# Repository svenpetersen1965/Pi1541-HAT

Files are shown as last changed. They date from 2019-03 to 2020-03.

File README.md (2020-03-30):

# Pi1541-HAT
Just another Pi1541-HAT. Please refer to Steve Whites project page (https://cbm-pi1541.firebaseapp.com/), who had the idea for the project and develops the software running in the Raspberry Pi.

There are several Pi1541-HATs, which are all good, nevertheless I have decided to make my own HAT. 

1. It has detachable display, switches and IEC-Bus boards

2. There is a barrel connector on the IEC-Bus Board, so no requirement for using the micro USB and no side entry for the enclosure required.

Find some info on the required cable making <a href="http://tech.guitarsite.de/cable_making.html">on my website</a>

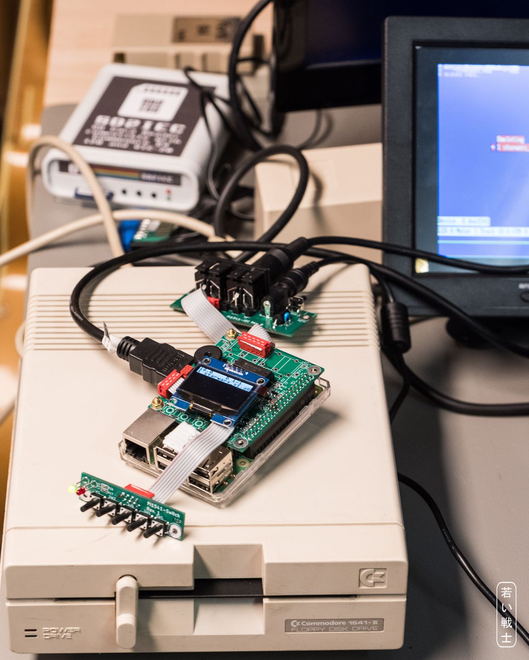
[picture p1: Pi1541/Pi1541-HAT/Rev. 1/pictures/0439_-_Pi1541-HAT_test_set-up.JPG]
Pi1541 with the detachable switch and iec board


I have made it this way to add flexibility to the HAT when it comes to be installed in an enclose and also alows a lower profile enclosure, since the high IEC-bus jacks are not above HAT level.

As a replacement for the switch board, a pcb with a rotary encoder with push button has been developed. This adds a quite bit more comfort while navigating through the directories. It mimiks the select, up and down button. This way, it works with the regular firmware (even before 1.21). Depending on the amount of text to be scrolled on the display, some pulses might get lost, which is hard to notice and does not reduce the usability.

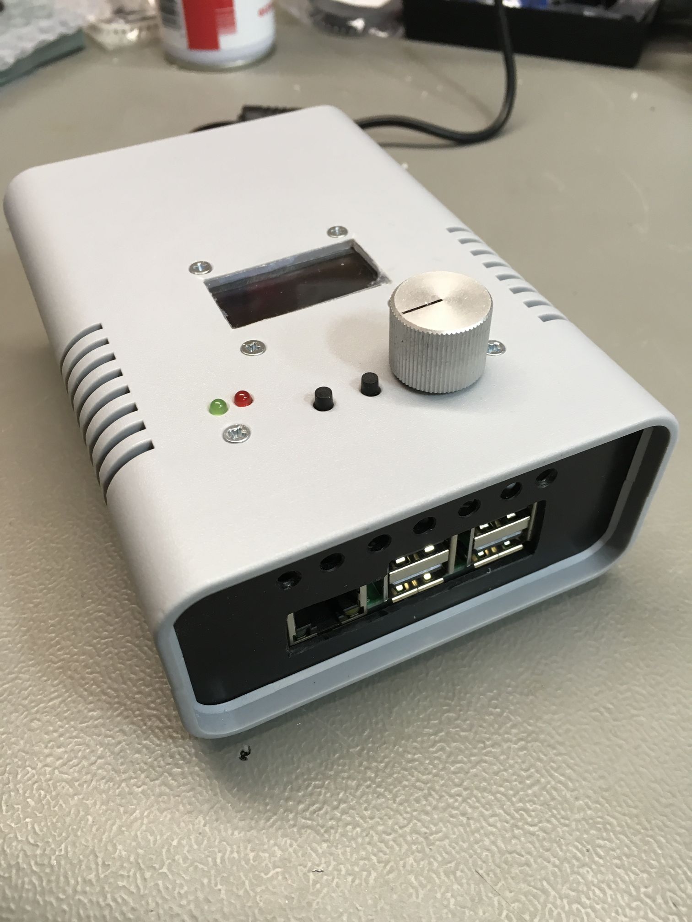
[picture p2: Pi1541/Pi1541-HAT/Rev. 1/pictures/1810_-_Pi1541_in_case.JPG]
Pi1541 withRotary Encoder Board in plastic enclusore


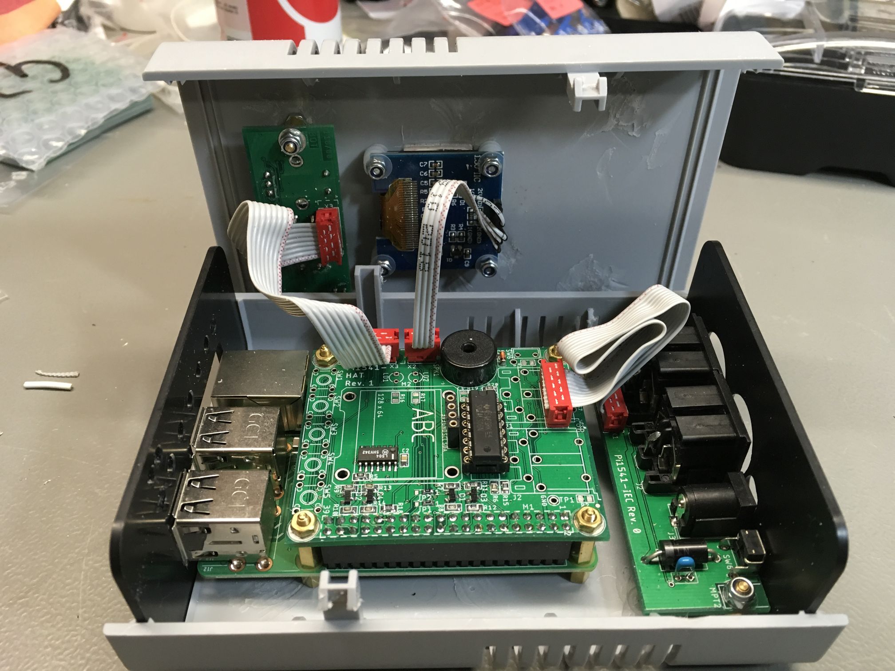
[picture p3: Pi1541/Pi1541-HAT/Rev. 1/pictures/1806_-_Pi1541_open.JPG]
Pi1541 withRotary Encoder Board (case open)


The kernal revision v1.21 supports the connection of a rotary encoder. Rev. 2 of the HAT PCB provides the connection of a rotary encoder module (KY-040), which is widely available on ebay etc. This is ment to be as a cheaper alternative for the otary encoder board of this project. 

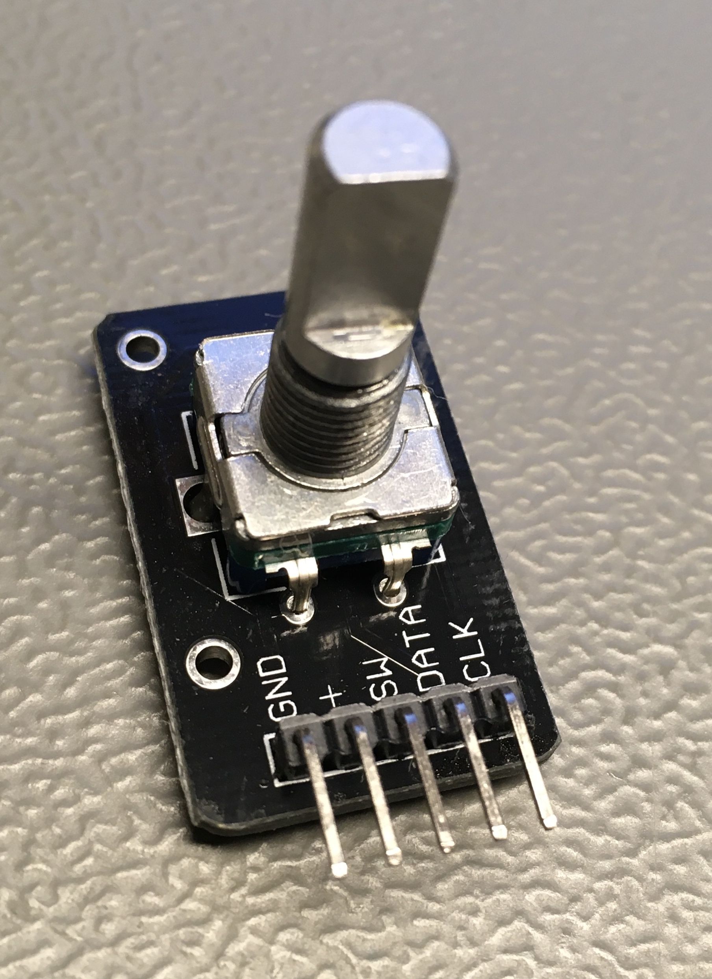
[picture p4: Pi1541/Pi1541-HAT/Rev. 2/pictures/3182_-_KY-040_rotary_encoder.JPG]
KY-040


The Rev. 2 of HAT and Switch and the (newest) Rev. 1 of the IEC board were tested and are fully functional.

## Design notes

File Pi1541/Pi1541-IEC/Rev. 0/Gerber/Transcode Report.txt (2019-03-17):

   ---- Transcoding 'X:\Projekte\_Eigene\Pi1541\Pi1541-IEC\Rev. 0\Gerber\gerber_Pi1541_IEC.crc' ----   Wed Feb 27 17:10:41 2019

D10   --> D100
D11   --> D101
-----------------------------------------------------------------

   ---- Transcoding 'X:\Projekte\_Eigene\Pi1541\Pi1541-IEC\Rev. 0\Gerber\gerber_Pi1541_IEC.out' ----   Wed Feb 27 17:10:41 2019

D12   --> D102
D13   --> D103
D14   --> D104
-----------------------------------------------------------------

   ---- Transcoding 'X:\Projekte\_Eigene\Pi1541\Pi1541-IEC\Rev. 0\Gerber\gerber_Pi1541_IEC.plc' ----   Wed Feb 27 17:10:41 2019

D12   --> D105
D13   --> D106
D14   --> D107
D15   --> D108
D16   --> D109
D17   --> D110
D18   --> D111
-----------------------------------------------------------------

   ---- Transcoding 'X:\Projekte\_Eigene\Pi1541\Pi1541-IEC\Rev. 0\Gerber\gerber_Pi1541_IEC.stc' ----   Wed Feb 27 17:10:41 2019

D12   --> D112
D13   --> D113
D14   --> D114
D15   --> D115
D16   --> D116
D17   --> D117
D18   --> D118
D19   --> D119
D20   --> D120
D21   --> D121
D22   --> D122
D23   --> D123
D24   --> D124
D25   --> D125
D26   --> D126
D27   --> D127
-----------------------------------------------------------------

   ---- Transcoding 'X:\Projekte\_Eigene\Pi1541\Pi1541-IEC\Rev. 0\Gerber\gerber_Pi1541_IEC.sts' ----   Wed Feb 27 17:10:41 2019

D12   --> D128
D13   --> D129
D14   --> D130
D15   --> D131
D16   --> D132
D17   --> D133
D18   --> D134
D20   --> D135
D22   --> D136
D23   --> D137
D24   --> D138
D25   --> D139
D26   --> D140
-----------------------------------------------------------------

   ---- Transcoding 'X:\Projekte\_Eigene\Pi1541\Pi1541-IEC\Rev. 0\Gerber\gerber_Pi1541_IEC.top' ----   Wed Feb 27 17:10:41 2019

D12   --> D141
D13   --> D142
D14   --> D143
D19   --> D144
D20   --> D145
D21   --> D146
D22   --> D147
D23   --> D148
D24   --> D149
D25   --> D150
D26   --> D151
D27   --> D152
D28   --> D153
D29   --> D154
D30   --> D155
D32   --> D156
-----------------------------------------------------------------

   ---- Transcoding 'X:\Projekte\_Eigene\Pi1541\Pi1541-IEC\Rev. 0\Gerber\excellon_Pi1541_IEC.ndk' ----   Wed Feb 27 17:10:57 2019

T1   --> T12
-----------------------------------------------------------------

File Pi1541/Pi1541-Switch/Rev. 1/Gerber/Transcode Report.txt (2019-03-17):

   ---- Transcoding 'X:\Projekte\_Eigene\Pi1541\Pi1541-Switch\Rev. 1\Gerber\gerber_Pi1541_Switch.crc' ----   Wed Feb 27 17:13:12 2019

D10   --> D100
D11   --> D101
-----------------------------------------------------------------

   ---- Transcoding 'X:\Projekte\_Eigene\Pi1541\Pi1541-Switch\Rev. 1\Gerber\gerber_Pi1541_Switch.out' ----   Wed Feb 27 17:13:12 2019

D12   --> D102
D13   --> D103
D14   --> D104
-----------------------------------------------------------------

   ---- Transcoding 'X:\Projekte\_Eigene\Pi1541\Pi1541-Switch\Rev. 1\Gerber\gerber_Pi1541_Switch.plc' ----   Wed Feb 27 17:13:12 2019

D12   --> D105
D13   --> D106
D14   --> D107
D15   --> D108
D16   --> D109
D17   --> D110
D18   --> D111
D19   --> D112
-----------------------------------------------------------------

   ---- Transcoding 'X:\Projekte\_Eigene\Pi1541\Pi1541-Switch\Rev. 1\Gerber\gerber_Pi1541_Switch.pls' ----   Wed Feb 27 17:13:13 2019

D12   --> D113
D13   --> D114
D14   --> D115
D15   --> D116
D16   --> D117
-----------------------------------------------------------------

   ---- Transcoding 'X:\Projekte\_Eigene\Pi1541\Pi1541-Switch\Rev. 1\Gerber\gerber_Pi1541_Switch.stc' ----   Wed Feb 27 17:13:13 2019

D12   --> D118
D13   --> D119
D14   --> D120
D15   --> D121
D16   --> D122
D17   --> D123
D18   --> D124
D19   --> D125
D20   --> D126
D21   --> D127
D22   --> D128
D23   --> D129
D24   --> D130
-----------------------------------------------------------------

   ---- Transcoding 'X:\Projekte\_Eigene\Pi1541\Pi1541-Switch\Rev. 1\Gerber\gerber_Pi1541_Switch.sts' ----   Wed Feb 27 17:13:13 2019

D12   --> D131
D13   --> D132
D14   --> D133
D15   --> D134
D16   --> D135
D17   --> D136
D18   --> D137
D19   --> D138
D21   --> D139
D23   --> D140
-----------------------------------------------------------------

   ---- Transcoding 'X:\Projekte\_Eigene\Pi1541\Pi1541-Switch\Rev. 1\Gerber\gerber_Pi1541_Switch.top' ----   Wed Feb 27 17:13:13 2019

D12   --> D141
D13   --> D142
D14   --> D143
D15   --> D144
D20   --> D145
D21   --> D146
D22   --> D147
D23   --> D148
D24   --> D149
D25   --> D150
D26   --> D151
-----------------------------------------------------------------

   ---- Transcoding 'X:\Projekte\_Eigene\Pi1541\Pi1541-Switch\Rev. 1\Gerber\excellon_Pi1541_Switch.ndk' ----   Wed Feb 27 17:13:25 2019

T1   --> T6
-----------------------------------------------------------------

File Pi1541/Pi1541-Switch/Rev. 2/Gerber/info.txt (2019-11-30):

       Board: Pi1541_Switch
       Rev.:  2
  
       Files:
       ======
  
       All Gerber files are generated in extended gerber format (RS274X)
       *.TOP        : Film top copper
       *.BOT        :  -"- bottom copper
       *.STC        :  -"- top soldermask 
       *.STS        :  -"- bottom soldermask
       *.PLC        :  -"- silk screen top
       *.PLS        :  -"- silk screen bottom
       *.CRC        :  -"- cream top
       *.DK         : Drills plated Through (Excellon)
       *.NDK        : Drills not plated Through (Excellon)
       *.OUT        : Board outline

       Board Size:
       ===========
       Length     :   13.65 mm
       Width      :   56.0 mm
       Thickness  :   1.6 mm
       Material   :   FR 4
       Copper     :   35 um
       Surface    :   HASL
       
       Remarks:
       ========

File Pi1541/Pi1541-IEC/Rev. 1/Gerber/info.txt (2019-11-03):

      
       Board: Pi1541-IEC
       Rev.:  1
  
       Files:
       ======
  
       All Gerber files are generated in extended gerber format (RS274X)
       *.TOP        : Film top copper
       *.BOT        :  -"- bottom copper
       *.STC        :  -"- top soldermask 
       *.STS        :  -"- bottom soldermask
       *.PLC        :  -"- silk screen top
       *.PLS        :  -"- silk screen bottom
       *.CRC        :  -"- cream top
       *.DK         : Drills plated Through (Excellon)
       *.NDK        : Drills not plated Through (Excellon)
       *.OUT        : Board outline

       Board Size:
       ===========
       Length     :   74.0 mm
       Width      :   25.5 mm
       Thickness  :   1.6 mm
       Material   :   FR 4
       Copper     :   35 um
       Surface    :   HASL
       
       Remarks:
       ========
       Width >= 8mil
       Distance >= 6mil
       Drill >= 0.4mm

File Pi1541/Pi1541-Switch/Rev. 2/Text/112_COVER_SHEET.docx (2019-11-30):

Documentation

Pi1541 - Switch

Project number: 112

Revision: 2

Date: 30.11.2019

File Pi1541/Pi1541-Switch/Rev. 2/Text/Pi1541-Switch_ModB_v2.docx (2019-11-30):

Pi1541 – Switch Rev. 2

Module description

# Description

The Pi1541-Switch is a detachable switch board for the Pi1541 HAT (project number 111). The connector to the Pi1541 HAT is placed on the solder side of the PCB. Further on, the switches SW1, SW2 and SW3 can be replaced by a pin header (J3, placed on the solder side), which is designed for connecting a rotary encoder module (such as the KY-040), which is supported since the Pi1541 kernel v1.21, which was released in November 2019.

# Switches

The switches have functions according to the firmware and configuration, which can be found at this website: https://cbm-pi1541.firebaseapp.com/ (https://cbm-pi1541.firebaseapp.com/%20%20)

The default configuration is:

Switch | Function
SW1 (left) | Select/Reset
SW2 | Move Up/Previous Disk
SW3 | Move Down/Next Disk
SW4 | Exit Folder
SW5 (right) | Insert Disk

# LEDs

LED | Color | Function
LD2 | Green | Power Indicator
LD1 | Red | Busy Indicator

# Connector

X3: 8p Micro Match, female, THT (Tyco or alternative)

The ribbon cable can also be soldered in directly.

Pin | Signal
1 | /SW1
2 | /SW2
3 | /SW3
4 | /SW4
5 | /SW5
6 | LED_OUT (LD1)
7 | +3V3
8 | GND

## Rotary Encoder connector

J3 – 5-pin pin header (2.54mm pitch) vertical or 90°.

Pin | Signal
1 | GND
2 | +3V3
3 | SW (/SW1_IN)
4 | DATA (/SW3_IN)
5 | CLK (/SW2_IN)

# Measures

Can be found in the board print out

# Revision History

Rev. 0: Prototype

Rev. 1: Moved the connector X3 to the solder side

Rev. 2: added J3 for connecting the rotary encoder.

Pi1541-Switch_ModB_v2.docx 30.11.2019 16:55 Drafted by Sven Petersen Page 2 of 2 Doc.-No.: 112-6-01-02

Pi1541-Switch_ModB_v2.docx 30.11.2019 16:55 Drafted by Sven Petersen Page 1 of 1 Doc.-No.: 112-6-01-02

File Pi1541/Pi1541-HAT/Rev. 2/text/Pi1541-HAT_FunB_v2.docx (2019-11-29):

Pi1541-HAT Rev. 2

Functional Description

J1 and J2 are the IEC-Bus connectors for the Commodore computers. X1 can be assembled instead of J1 and J2 to make use of an external IEC-Bus PCB.

SW6 is an IEC-Bus RESET switch.

IC1A is the bus driver for the IEC-Bus DATA signal. R3 is the required 1k pull-up-resistor. Since DATA is a bi-directional signal, there is an input stage (IC2A and IC2B), too. This circuit resembled the original 1541 input circuitry. The input signals are inverted twice (which is not required, since the Pi1541 can be configured to use inverted input signals). Q1 in conjunction with R7 and R8 is acting as a 5V/3.3V level shifter. This is a common level shifter circuit as suggested for I²C-bus level shifting by NXP.

The circuit for the CLK signal of the IEC-bus is the same. ATN and /RESET do not have an output stage. The input stage of the /RESET signal is making use of the 74LS06 (IC1). Thus, the pull-up-resistor R6 is required.

M1 is the Raspberry Pi connector.

LD1 is the activity LED. LD2 is the power LED.

Both jumpers JP1 and JP2 should be jumpered 1-2 to drive the display M2 with the primary I²C-Bus of the Raspberry Pi.

A 0.96” OLED-Display can be connected to M3. In case a 1.3” display is used, the LED and the switches cannot be populated anymore and an external Pi1541-Switch board is required.

The display can also be connected to the MicroMatch connector X2.

SW1 to SW5 are the user interface for navigating through the directories of the disk archive on the SD-card.

Q5 is driving the piezo buzzer. D1 is acting as a protection, since piezo crystals are generating a voltage, when they are moved/compressed. R20 is required, since the idle level of the SND_OUT signal is HIGH. C3 can be used for sound shaping and additional protection.

TP1 is a ground connection for measurement/debugging.

J3 is for attaching a rotary encoder module. The pinning matches the wide spread KY-040.

Pi1541-HAT_FunB_v2.docx 29.11.2019 17:01 Drafted by Sven Petersen Page 2 of 2 Doc.-No.: 000-6-00-00

Pi1541-HAT_FunB_v2.docx 29.11.2019 17:01 Drafted by Sven Petersen Page 1 of 1 Doc.-No.: 111-6-02-02

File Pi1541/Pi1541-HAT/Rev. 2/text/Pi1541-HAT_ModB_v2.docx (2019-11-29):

Pi1541-HAT Rev. 2

Module description

# Description

The Pi1541 HAT is the required electrical and user interface for the Raspberry Pi (Model 3, 3+ or better) to emulate the Commodore 1541 floppy disk drive in conjunction with Steve White’s software project (https://cbm-pi1541.firebaseapp.com/ (https://cbm-pi1541.firebaseapp.com/%20%20)). This software is a cycle exact, real-time emulation of the 1541. The disk images are stored on the SD-card of the Raspberry Pi and the switches and the display (of the HAT) allow the user to navigate through his disk archive. Since Pi1541 emulates the exact hardware of the 1541, it is compatible to every speed loader, that work with the original disk drive.

This Pi1541 HAT is one of many possible variants. It holds the original I/O-driver configuration of the 1541, which is then adapted to the Raspberry Pi. The user interface consists of an OLED-display, six switches and a piezo buzzer, which resembles the sound of the working stepper motor.

Further on, it is designed to offer a good flexibility. The display can be either connected to a 4 pole receptable on the board or it can be detached and connected with a small piece of ribbon cable. The switches can also be soldered on the PCB or on a little extra PCB (Pi1541-Switch), which also holds two LEDs and is designed for a front panel mount. The two IEC-connectors can be mounted on this PCB or a separate PCB (Pi1541-IEC), which also holds a RESET switch and a barrel connector for a 5V power supply.

# Pin outs

## IEC-Bus

J1 and J2 – Lumberg 010599 06, 6p DIN receptables

Pin | Signal
1 | /SRQ (not used in this design)
2 | GND
3 | ATN
4 | CLK
5 | DATA
6 | /RESET

## IEC Bus (break out board)

X1 – 10p Micro Match receptible, female, vertical, through hole, e.g. MPE Garry 369-1-010

X1 can be assembled instead of J1 and J2

Pin | Signal
1 | /SRQ (not used in this design)
2 | GND
3 | ATN
4 | CLK
5 | DATA
6 | /RESET
7 | +5V
8 | +5V
9 | GND
10 | GND

## Display

M2 - A 0.96” OLED display (I²C) can be connected to the 4p receptable M2 (0.1” pin distance). This connector provides +3.3V supply voltage. It is important to check the pinning of the display. Some might have swapped +3.3V and GND, so inserting those displays will destroy them.

From left to right:

Pin | Signal
1 | VCC
2 | GND
3 | SCL
4 | SDA

## External Display

In case the display is desired to be mounted externally or it is bigger than the footprint (e.g. 1.3”) or it has a different pin sequence such as GND, VCC etc. it can be attached to this connector.

X2 – 4p Micro Match receptible, female, vertical, through hole, e.g. MPE Garry 369-1-004

Pin | Signal
1 | VCC
2 | GND
3 | SCL
4 | SDA

## External Switches

X3 – 8p Micro Match receptible, female, vertical, through hole, e.g. MPE Garry 369-1-008

Pin | Signal
1 | /SW1
2 | /SW2
3 | /SW3
4 | /SW4
5 | /SW5
6 | LED_OUT (LD1)
7 | +3V3
8 | GND

## Raspberry Pi Connector

A 2x20 Pin receptible, assembled on the solder side of the PCB.

Pin | GPIO | Signal | Comment
1 | - | +3.3V | Supply voltage
2 | - | +5V | Supply voltage
3 | SDA | SDA (I²C) | I²C-Bus (display)
4 | - | +5V | Supply voltage
5 | SCL | SCL (I²C) | I²C-Bus (display)
6 | - | GND | Ground
7 | 4 | /SW4_IN | Switch 4, active low
9 | - | GND | Ground
11 | 17 | /CLK_OUT | /CLK_(output to IEC-Bus driver)
12 | 18 | /DATA_OUT | /DATA (output to IEC-Bus driver)
13 | 27 | /SW1_IN | Switch 1, active low
14 | - | GND | Ground
15 | 22 | /SW2_IN | Switch 2, active low
16 | 23 | /SW3_IN | Switch 3, active low
17 | - | +3.3V | Supply voltage
18 | 24 | ATN_IN | ATN (IEC-Bus), 3.3V-level
20 | - | GND | Ground
22 | 25 | DATA_IN | DATA (IEC-Bus), 3.3V-level
25 | - | GND | Ground
27 | ID_SD | ID_SD | Secondary I²C: SDA
28 | IC_SC | ID_SC | Secondary I²C: SCL
29 | 5 | /SW5_IN | Switch 5, active low
30 | - | GND | Ground
33 | 13 | SND_OUT | Sound/Piezo buzzer
34 | - | GND | Ground
36 | 16 | LED_OUT | Activity LED
37 | 26 | CLK_IN | CLK (IEC-Bus), 3.3V-level
38 | 20 | /RESET_IN | /RESET (IEC-Bus), 3.3V-level
39 | - | GND | Ground

## Rotary Encoder connector

J3 – 5-pin pin header (2.54mm pitch) vertical or 90°.

Pin | Signal
1 | GND
2 | +3V3
3 | SW (/SW1_IN)
4 | DATA (/SW3_IN)
5 | CLK (/SW2_IN)

# Jumpers

JP1 and JP2 are SMD jumpers (to be bridged by a 0603 resistor/0Ω). The I²C bus for the display can be selected. For a proper function, they should both be bridged between 1-2. This selects the primary I²C-bus.

# Switches

Switch | Function
SW1 (left) | Select/Reset
SW2 | Move Up/Previous Disk
SW3 | Move Down/Next Disk
SW4 | Exit Folder
SW5 (right) | Insert Disk

SW6 is a RESET switch for the IEC-Bus

# Configuration

The configuration of the software can be found in the root directory of the micro SD-card (options.txt). It has to be edited before powering up the Raspberry Pi for the first time.

Since there are input and output drivers, for the bidirectional IEC-Bus signals signal, the parameter has to be set in the following way:

splitIECLines = 1

There is a buzzer acting as a sound device for resembling the working stepper motor of the real drive:

SoundOnGPIO = 1

SoundOnGPIODuration = 70 // Length of buzz in micro seconds

SoundOnGPIOFreq = 900 // Frequency of buzz in Hz

The I²C-Bus for the display requires this configuration:

i2cBusMaster = 1 //SDA - pin 3 SCL - pin 5

More information about the configuration and setup can be found on the Pi1541 project website mentioned above. It is highly recommended to read the instructions there before setting up the SD card.

The (optional) rotary encoder is activated with

RotaryEncoderEnable = 1

# Revision history

## Rev. 0 → Rev. 1

- R20 added, due to the SND_OUT being High during idle
- X1 became 10p to enable a power supply being connected on the external IEC-Board
- Added TP1 as a ground connection for measurement

## Rev. 1 → Rev. 2

- J3 for an optional rotary encoder added (supported by the Firmware/Kernel v1.21 and later)

Pi1541-HAT_ModB_v2.docx 29.11.2019 16:20 Drafted by Sven Petersen Page 2 of 2 Doc.-No.: 111-6-01-02

Pi1541-HAT_ModB_v2.docx 29.11.2019 16:20 Drafted by Sven Petersen Page 1 of 1 Doc.-No.: 111-6-01-02

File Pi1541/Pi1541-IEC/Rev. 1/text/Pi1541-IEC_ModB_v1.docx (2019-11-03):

# Pi1541-IEC Rev. 1

# Module Description

# Description

The Pi1541-IEC serves the Pi1541-HAT (project number 111) as an optional break out board for the IEC connectors. It also contains a barrel connector (5,5/2,5mm) for an alternative power supply connection plus an overvoltage protection. A reset switch for the IEC-bus can be placed. A ribbon cable plus a MicroMatch connector provide the connection to the Pi1541-HAT. A power switch can be connected to a pin header (JP1) near the barrel connector. If this is not desired, it can be closed with a solder bridge.

# Pinouts

## IEC-Bus

J1 and J2 – Lumberg 010599 06, 6p DIN receptacles

Pin | Signal
1 | /SRQ (not used in this design)
2 | GND
3 | ATN
4 | CLK
5 | DATA
6 | /RESET

## IEC Bus (to Pi1541 HAT)

X1 – 10p Micro Match receptacle, female, vertical, through hole, e.g. MPE Garry 369-1-010

Pin | Signal
1 | /SRQ (not used in this design)
2 | GND
3 | ATN
4 | CLK
5 | DATA
6 | /RESET
7 | +5V
8 | +5V
9 | GND
10 | GND

## +5VDC Power

5,5mm/2,5mm barrel connector

Pin | Signal
Center | +5VDC
Shaft | GND

# Prototype Testing

The prototype was tested together with Pi1541-HAT Rev. 1. Please refer to the respective document.

# Revision History

## Rev. 0 → Rev. 1

- Jumper JP1 added for connecting a power switch

Pi1541-IEC_ModB_v1.docx 03.11.2019 08:36 Drafted by Sven Petersen Page 2 of 2 Doc.-No.: 115-6-01-01

Pi1541-IEC_ModB_v1.docx 03.11.2019 08:36 Drafted by Sven Petersen Page 1 of 1 Doc.-No.: 115-6-01-00

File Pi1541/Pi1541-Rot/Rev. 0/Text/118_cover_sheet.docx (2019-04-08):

Project Documentation

Pi1541 – Rotary Encoder Board

Project number: 118

Revision: 0

Date: 17.03.2019

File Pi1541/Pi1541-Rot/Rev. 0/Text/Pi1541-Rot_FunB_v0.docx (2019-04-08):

Pi1541 – Rotary Encoder Board Rev. 0

Functional Description

The rotary encoder RT1 issues two square wave signals on channel A and channel B, depending on the direction of the turn, channel A is ahead of channel B or vice versa.

Since the rotary encoder is working mechanically, the two channels are required to be “debounced”. R6/R8/C6 or R5/R7/C7 are serving this purpose, as recommended by the manufacturer of the rotary encoder.

There are two identical circuits for the direction recognition, which consist of a D-flip flop and a mono-flop each. For both directions, channel A and Channel B play an opposite role.

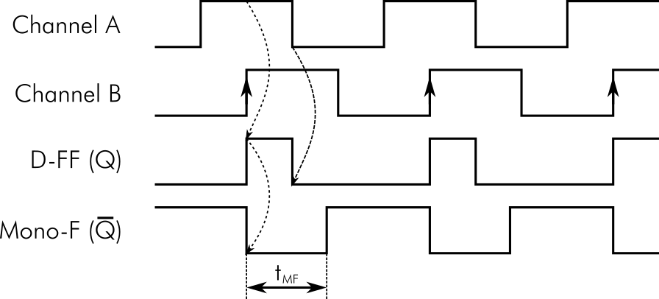
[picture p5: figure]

Figure 1: Channel A ahead of channel B

The case shown in Figure 1 describes a turn fitting the detected direction. Here, channel B is driving the clock signal of the D-flipflop (IC1), while channel A is connected to the D-input and the /CLR-signal of that D-FF. A rising edge of channel B will latch the level of channel A (in this case a HIGH) to the output Q. Later in the signal cycle, channel A will get LOW, which resets the D-FF via the /CLR input. The positive pulse generated on the output Q triggers the following mono-flop (IC2). This way, a LOW pulse of a duration tMF will be issued on the /Q output of IC2. tMF is determined by the R/C combination (R3 and C3 or R4 and C4) connected to the mono-flop.

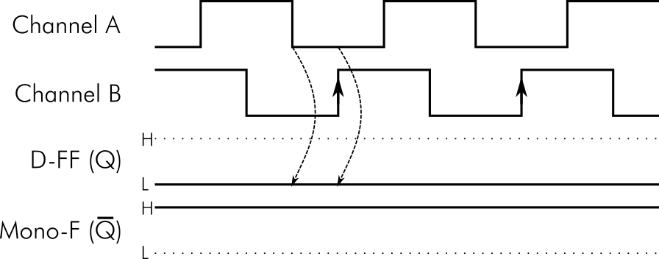
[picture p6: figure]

Figure 2: Channel B ahead of channel A

Turning the rotary encoder opposite to the detected direction will result in output signals shown in Figure 2. A LOW level of channel A will reset the D-FF. The output Q of IC1 will be reset. When the rising edge of Channel B latches the level of channel A, which is LOW at that time. The output Q of the D-FF will remain low. No pulses are generated by the mono-flop (IC2).

Pushing the rotary encoder will work as the Select/Reset switch. Pushing SW4 will exit the folder, SW5 will select the disk images for a multi disk game/demo.

Pi1541-Rot_FunB_v0.docx 08.04.2019 16:58 Drafted by Sven Petersen Page 2 of 2 Doc.-No.: 000-6-00-00

Pi1541-Rot_FunB_v0.docx 08.04.2019 16:58 Drafted by Sven Petersen Page 1 of 1 Doc.-No.: 118-6-02-00

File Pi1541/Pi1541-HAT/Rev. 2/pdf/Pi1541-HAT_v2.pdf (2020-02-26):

# Project Documentation

## Pi1541 HAT

## Project number: 111

## Revision: 2

## Date: 29.11.2019

Pi1541-HAT_ModB_v2.docx | | 29.11.2019 16:20
Drafted by Sven Petersen | Page 1 of 4 | Doc.-No.: 111-6-01-02

### Pi1541-HAT Rev. 2

### Module description

## Description

The Pi1541 HAT is the required electrical and user interface for the Raspberry Pi (Model 3, 3+ or better) to emulate the Commodore 1541 floppy disk drive in conjunction with Steve White’s software project (https://cbm-pi1541.firebaseapp.com/). This software is a cycle exact, real-time emulation of the 1541. The disk images are stored on the SD-card of the Raspberry Pi and the switches and the display (of the HAT) allow the user to navigate through his disk archive. Since Pi1541 emulates the exact hardware of the 1541, it is compatible to every speed loader, that work with the original disk drive.

This Pi1541 HAT is one of many possible variants. It holds the original I/O-driver configuration of the 1541, which is then adapted to the Raspberry Pi. The user interface consists of an OLED-display, six switches and a piezo buzzer, which resembles the sound of the working stepper motor.

Further on, it is designed to offer a good flexibility. The display can be either connected to a 4 pole receptable on the board or it can be detached and connected with a small piece of ribbon cable. The switches can also be soldered on the PCB or on a little extra PCB (Pi1541-Switch), which also holds two LEDs and is designed for a front panel mount. The two IEC-connectors can be mounted on this PCB or a separate PCB (Pi1541-IEC), which also holds a RESET switch and a barrel connector for a 5V power supply.

## Pin outs

### IEC-Bus

J1 and J2 – Lumberg 010599 06, 6p DIN receptables

Pin Signal
1 /SRQ (not used in this design) 2 GND
3 ATN
4 CLK
5 DATA
6 /RESET

### IEC Bus (break out board)

X1 – 10p Micro Match receptible, female, vertical, through hole, e.g. MPE Garry 369-1-010

X1 can be assembled instead of J1 and J2

Pi1541-HAT_ModB_v2.docx | | 29.11.2019 16:20
Drafted by Sven Petersen | Page 2 of 4 | Doc.-No.: 111-6-01-02
Pin | Signal
1 /SRQ (not used in this design) 2 GND
3 ATN
4 CLK
5 DATA
6 /RESET
7 +5V
8 +5V
9 GND
10 GND

### Display

M2 - A 0.96” OLED display (I²C) can be connected to the 4p receptable M2 (0.1” pin distance).
This connector provides +3.3V supply voltage. It is important to check the pinning of the display. Some might have swapped +3.3V and GND, so inserting those displays will destroy them.

From left to right:

Pin Signal
1 VCC
2 GND
3 SCL
4 SDA

### External Display

In case the display is desired to be mounted externally or it is bigger than the footprint (e.g. 1.3”) or it has a different pin sequence such as GND, VCC etc. it can be attached to this connector.

X2 – 4p Micro Match receptible, female, vertical, through hole, e.g. MPE Garry 369-1-004

Pin Signal
1 VCC
2 GND
3 SCL
4 SDA

### External Switches

X3 – 8p Micro Match receptible, female, vertical, through hole, e.g. MPE Garry 369-1-008

Pin Signal
1 /SW1
2 /SW2
3 /SW3
4 /SW4
5 /SW5
6 LED_OUT (LD1)
7 +3V3
8 GND

Pi1541-HAT_ModB_v2.docx | | 29.11.2019 16:20
Drafted by Sven Petersen | Page 3 of 4 | Doc.-No.: 111-6-01-02

### Raspberry Pi Connector

A 2x20 Pin receptible, assembled on the solder side of the PCB.

Pin | GPIO | Signal | Comment
1 | - | +3.3V | Supply voltage
2 | - | +5V | Supply voltage
3 | SDA | SDA (I²C) | I²C-Bus (display)
4 | - | +5V | Supply voltage
5 | SCL | SCL (I²C) | I²C-Bus (display)
6 | - | GND | Ground
7 | 4 | /SW4_IN | Switch 4, active low
9 | - | GND | Ground
11 | 17 | /CLK_OUT | /CLK_(output to IEC-Bus driver)
12 | 18 | /DATA_OUT | /DATA (output to IEC-Bus driver)
13 | 27 | /SW1_IN | Switch 1, active low
14 | - | GND | Ground
15 | 22 | /SW2_IN | Switch 2, active low
16 | 23 | /SW3_IN | Switch 3, active low
17 | - | +3.3V | Supply voltage
18 | 24 | ATN_IN | ATN (IEC-Bus), 3.3V-level
20 | - | GND | Ground
22 | 25 | DATA_IN | DATA (IEC-Bus), 3.3V-level
25 | - | GND | Ground
27 | ID_SD | ID_SD | Secondary I²C: SDA
28 | IC_SC | ID_SC | Secondary I²C: SCL
29 | 5 | /SW5_IN | Switch 5, active low
30 | - | GND | Ground
33 | 13 | SND_OUT | Sound/Piezo buzzer
34 | - | GND | Ground
36 | 16 | LED_OUT | Activity LED
37 | 26 | CLK_IN | CLK (IEC-Bus), 3.3V-level
38 | 20 | /RESET_IN | /RESET (IEC-Bus), 3.3V-level
39 | - | GND | Ground

### Rotary Encoder connector

J3 – 5-pin pin header (2.54mm pitch) vertical or 90°.

Pin Signal
1 GND
2 +3V3
3 SW (/SW1_IN)
4 DATA (/SW3_IN)
5 CLK (/SW2_IN)

## Jumpers

JP1 and JP2 are SMD jumpers (to be bridged by a 0603 resistor/0Ω). The I²C bus for the display can be selected. For a proper function, they should both be bridged between 1-2. This selects the primary I²C-bus.

Pi1541-HAT_ModB_v2.docx | | 29.11.2019 16:20
Drafted by Sven Petersen | Page 4 of 4 | Doc.-No.: 111-6-01-02

## Switches

Switch | Function
SW1 (left) | Select/Reset
SW2 | Move Up/Previous Disk
SW3 | Move Down/Next Disk
SW4 | Exit Folder
SW5 (right) | Insert Disk

SW6 is a RESET switch for the IEC-Bus

## Configuration

The configuration of the software can be found in the root directory of the micro SD-card (options.txt). It has to be edited before powering up the Raspberry Pi for the first time.

Since there are input and output drivers, for the bidirectional IEC-Bus signals signal, the parameter has to be set in the following way:

splitIECLines = 1

There is a buzzer acting as a sound device for resembling the working stepper motor of the real drive:

SoundOnGPIO = 1

SoundOnGPIODuration = 70 // Length of buzz in micro seconds

SoundOnGPIOFreq = 900 // Frequency of buzz in Hz

The I²C-Bus for the display requires this configuration:

i2cBusMaster = 1 //SDA - pin 3 SCL - pin 5

More information about the configuration and setup can be found on the Pi1541 project website mentioned above. It is highly recommended to read the instructions there before setting up the SD card.

The (optional) rotary encoder is activated with

RotaryEncoderEnable = 1

## Revision history

### Rev. 0 → Rev. 1

- R20 added, due to the SND_OUT being High during idle
- X1 became 10p to enable a power supply being connected on the external IEC-Board
- Added TP1 as a ground connection for measurement

### Rev. 1 → Rev. 2

- J3 for an optional rotary encoder added (supported by the Firmware/Kernel v1.21 and later)

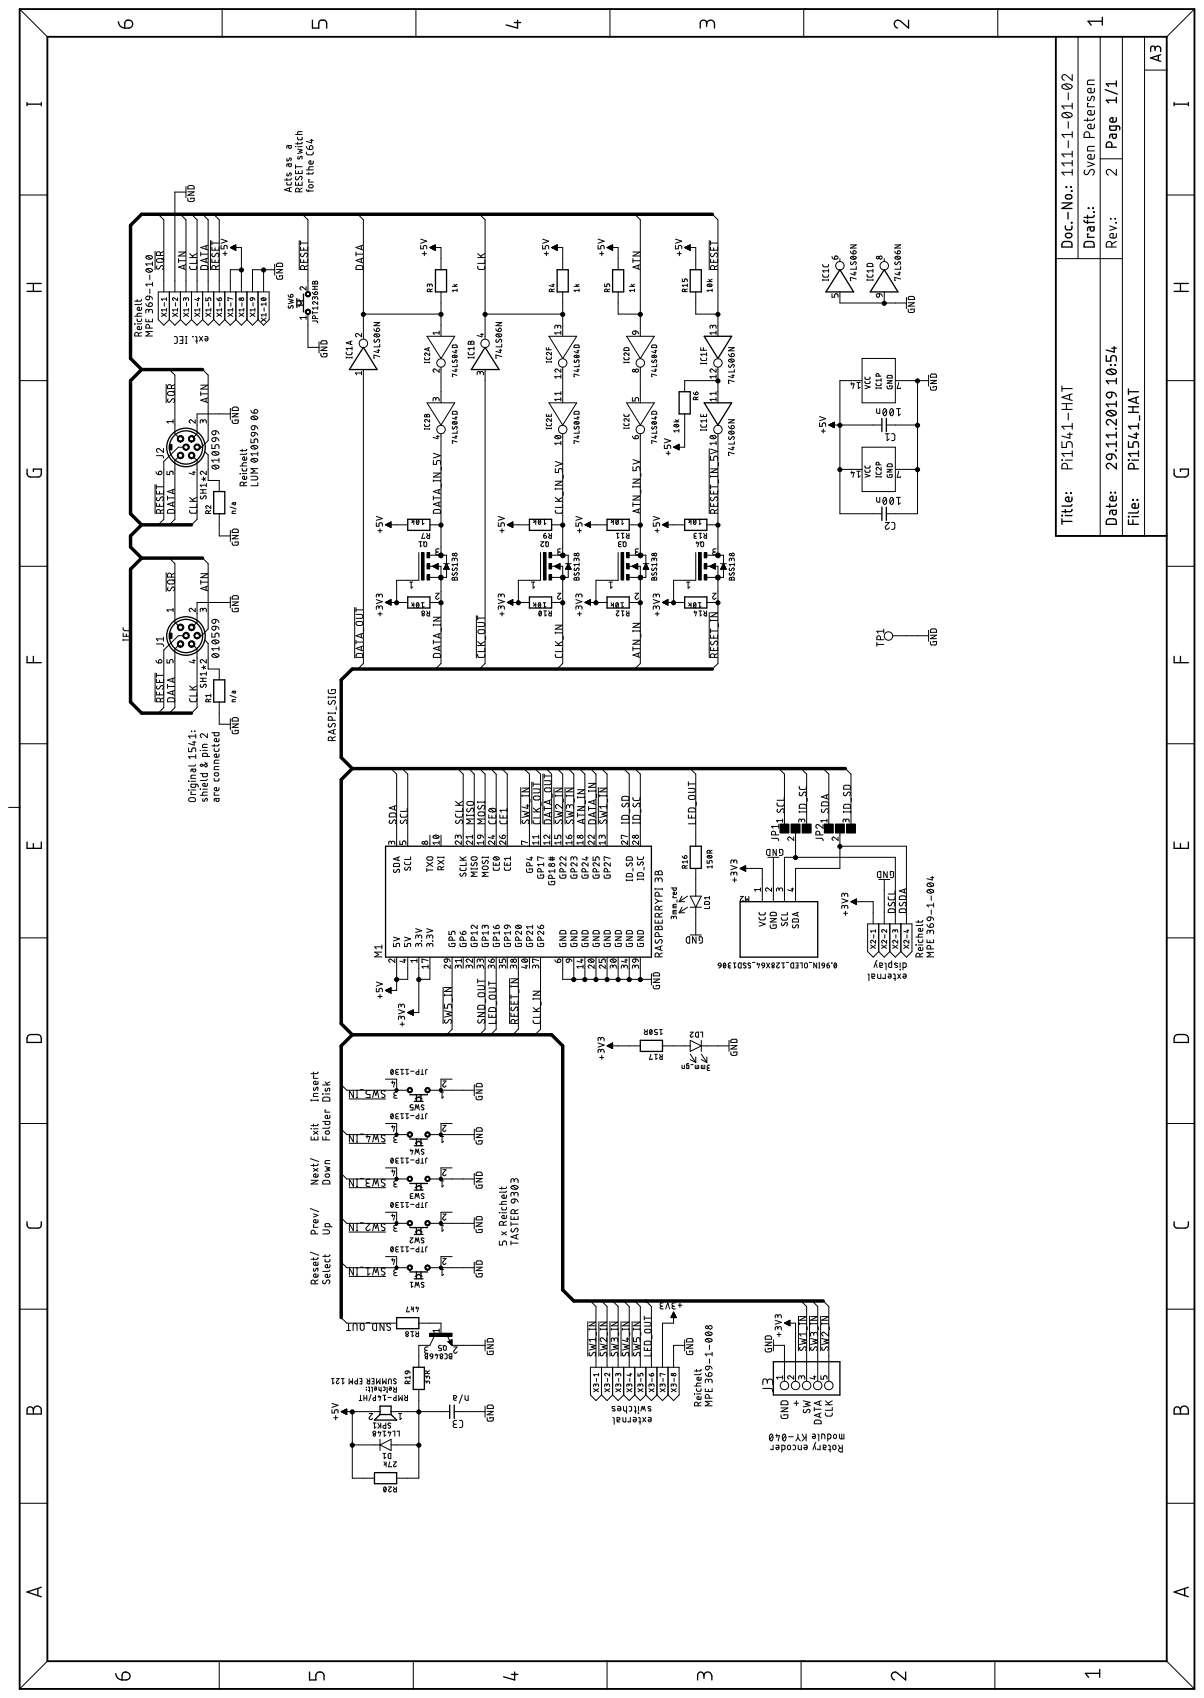
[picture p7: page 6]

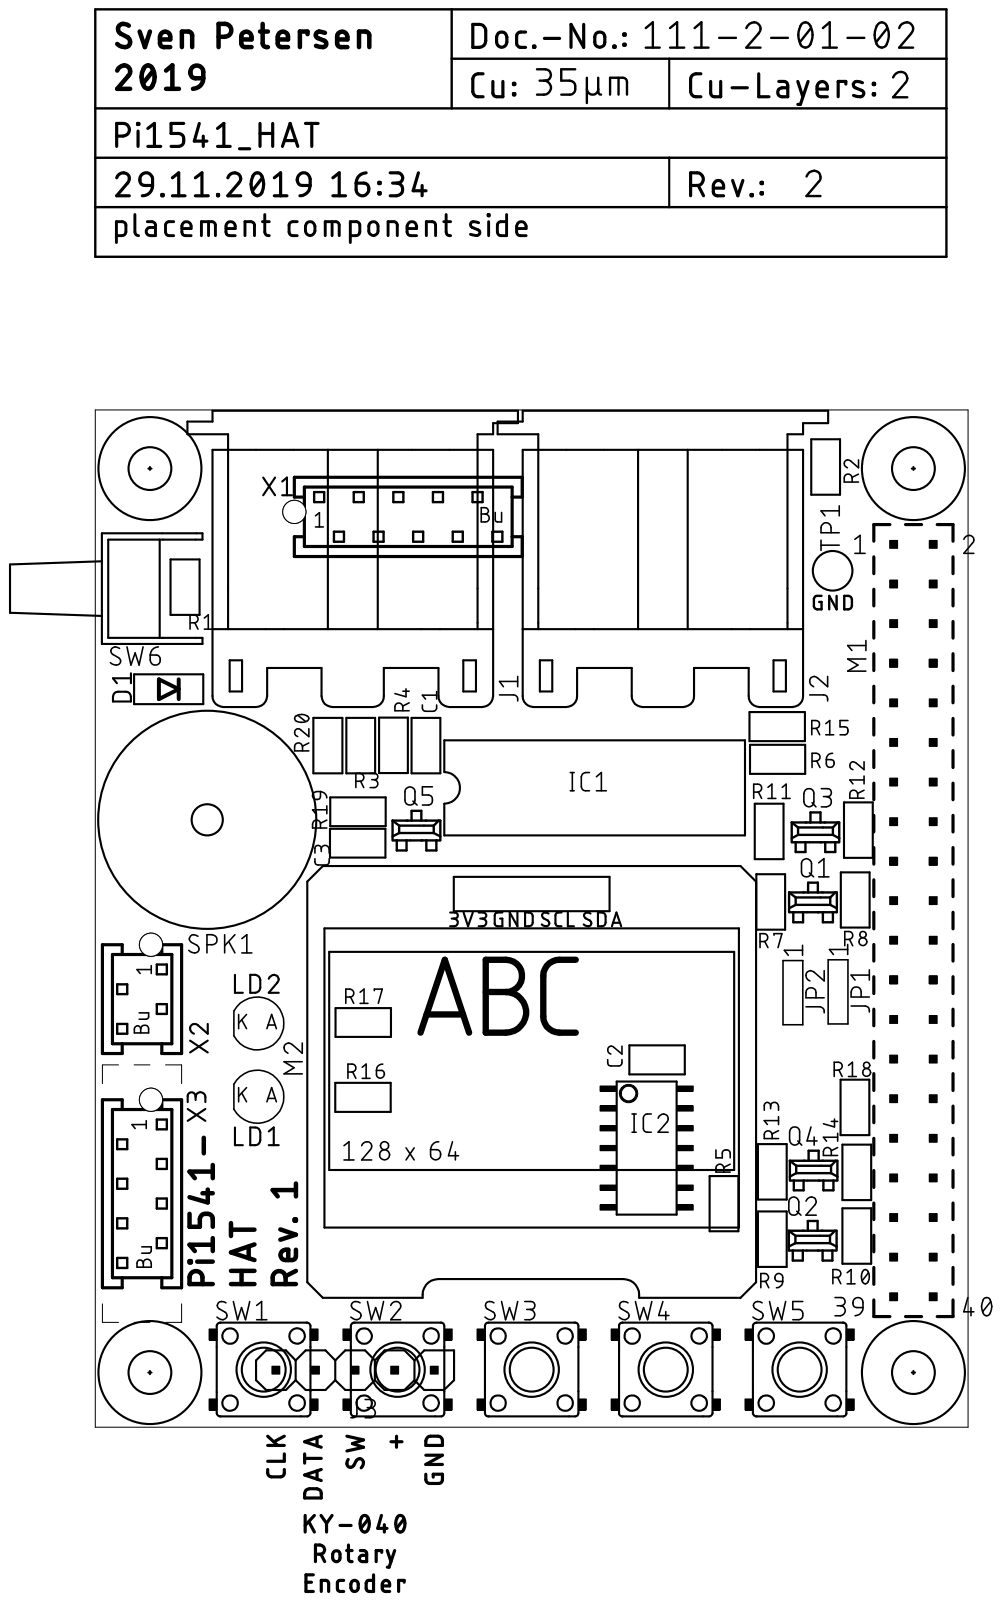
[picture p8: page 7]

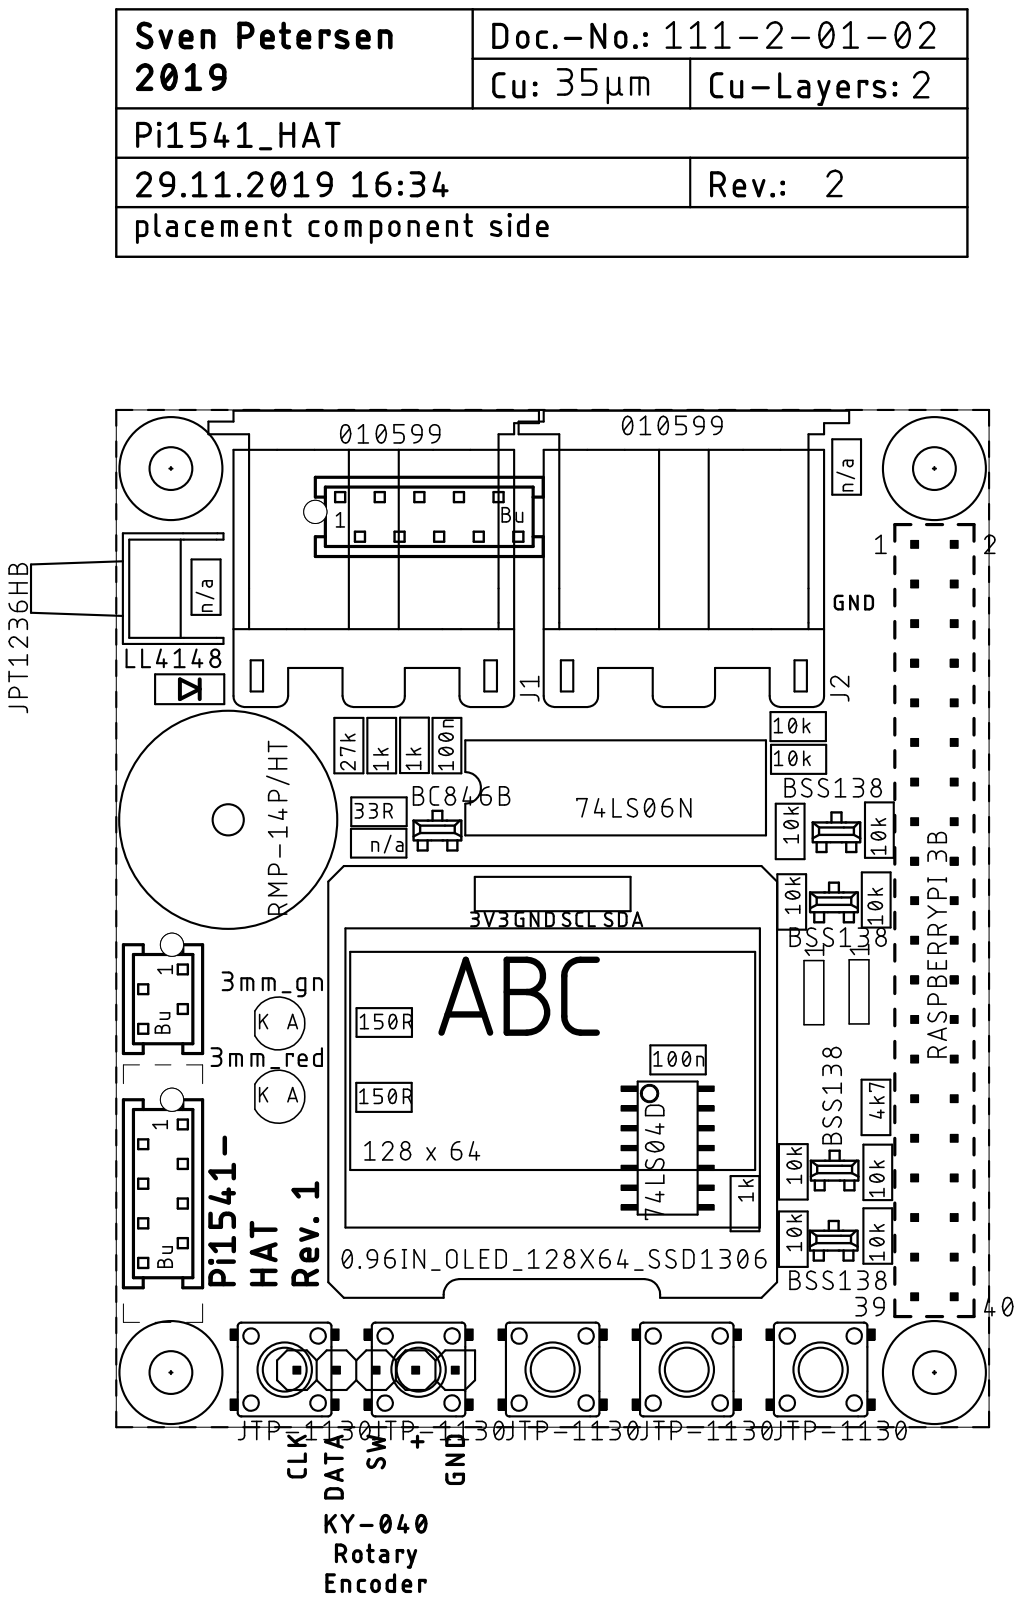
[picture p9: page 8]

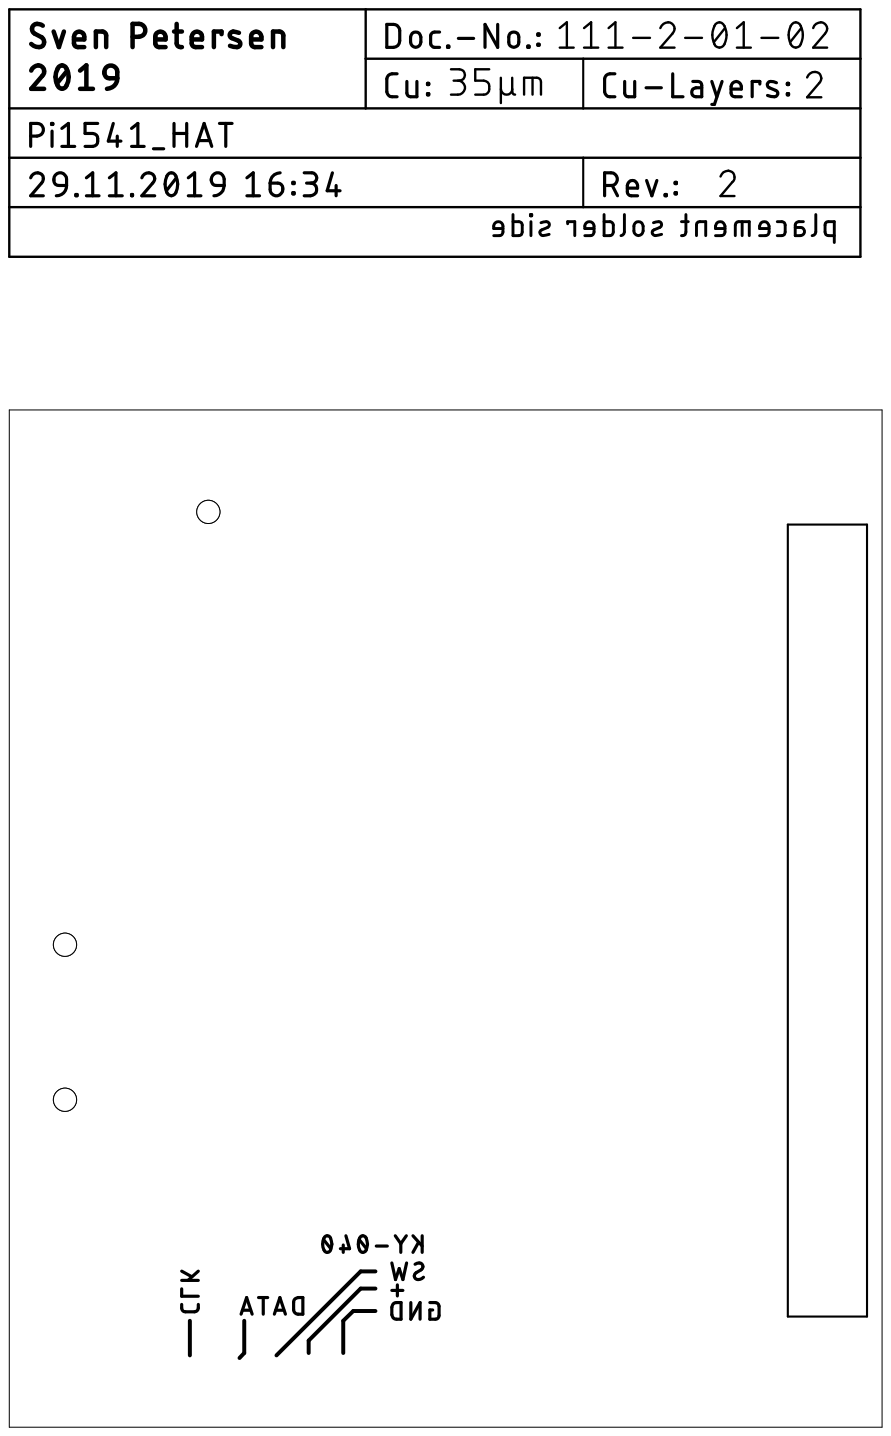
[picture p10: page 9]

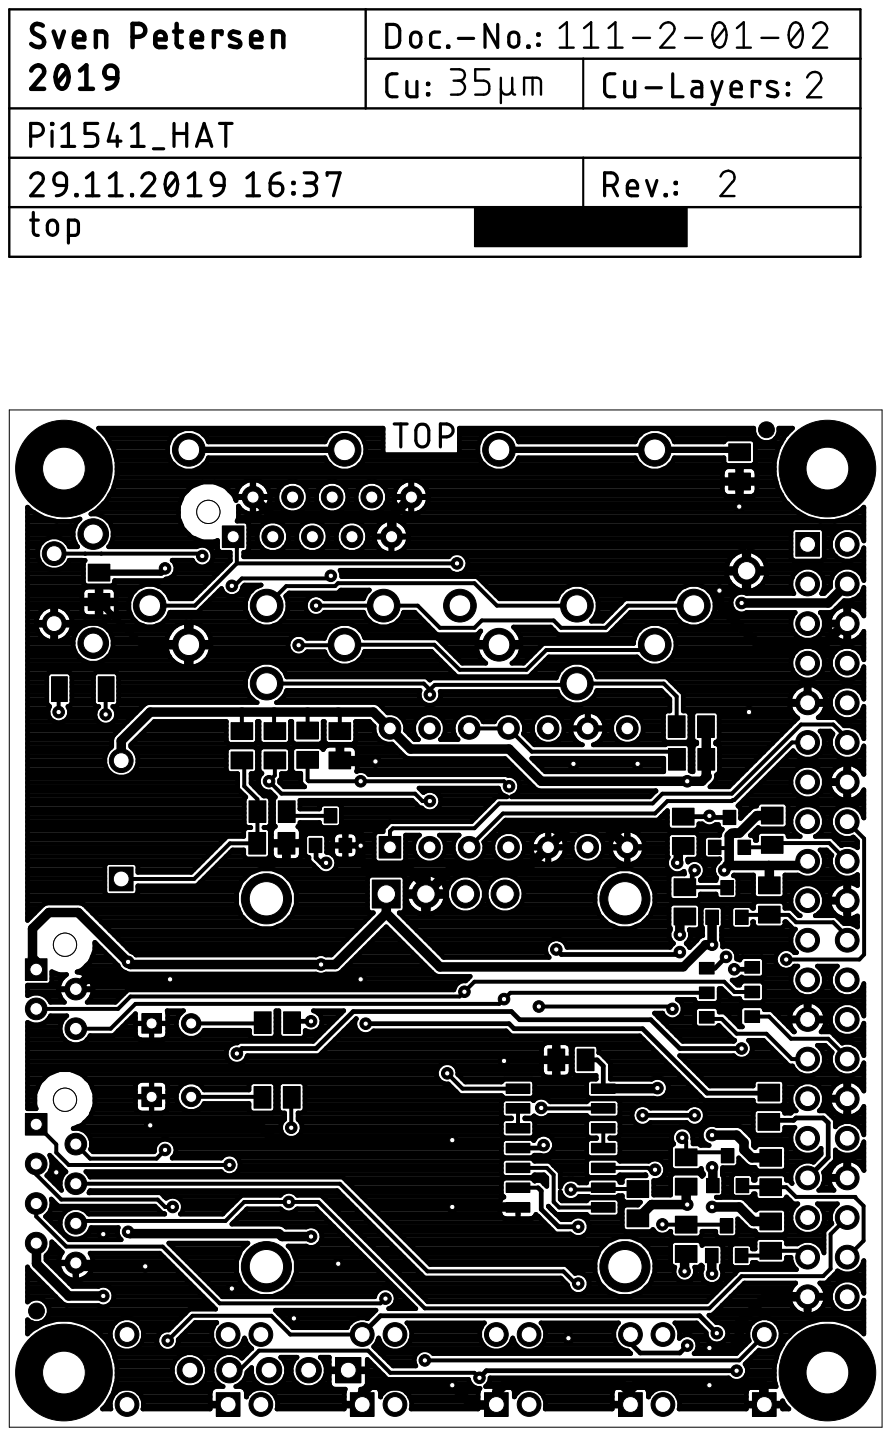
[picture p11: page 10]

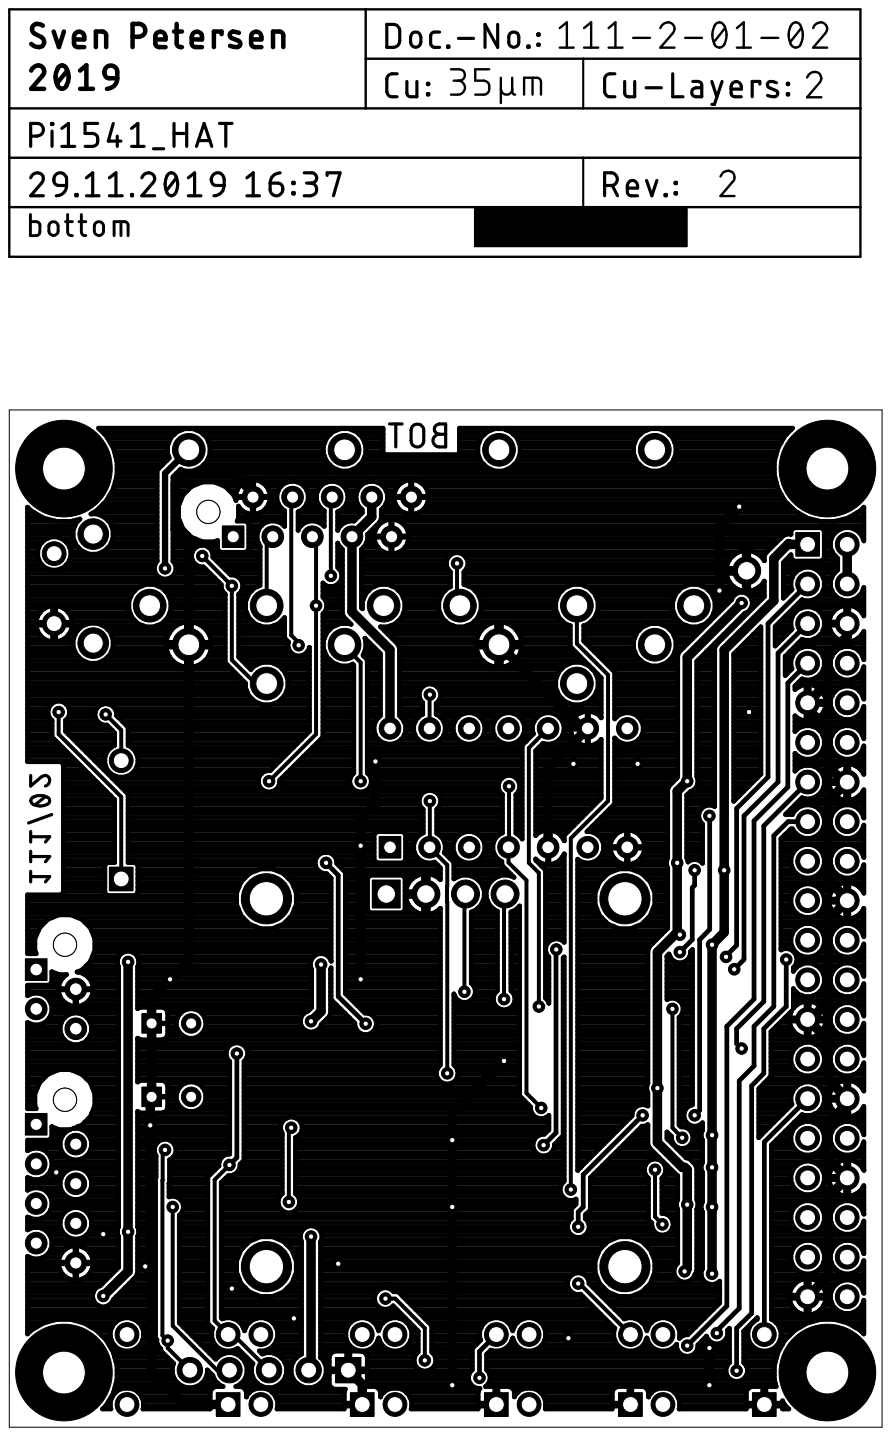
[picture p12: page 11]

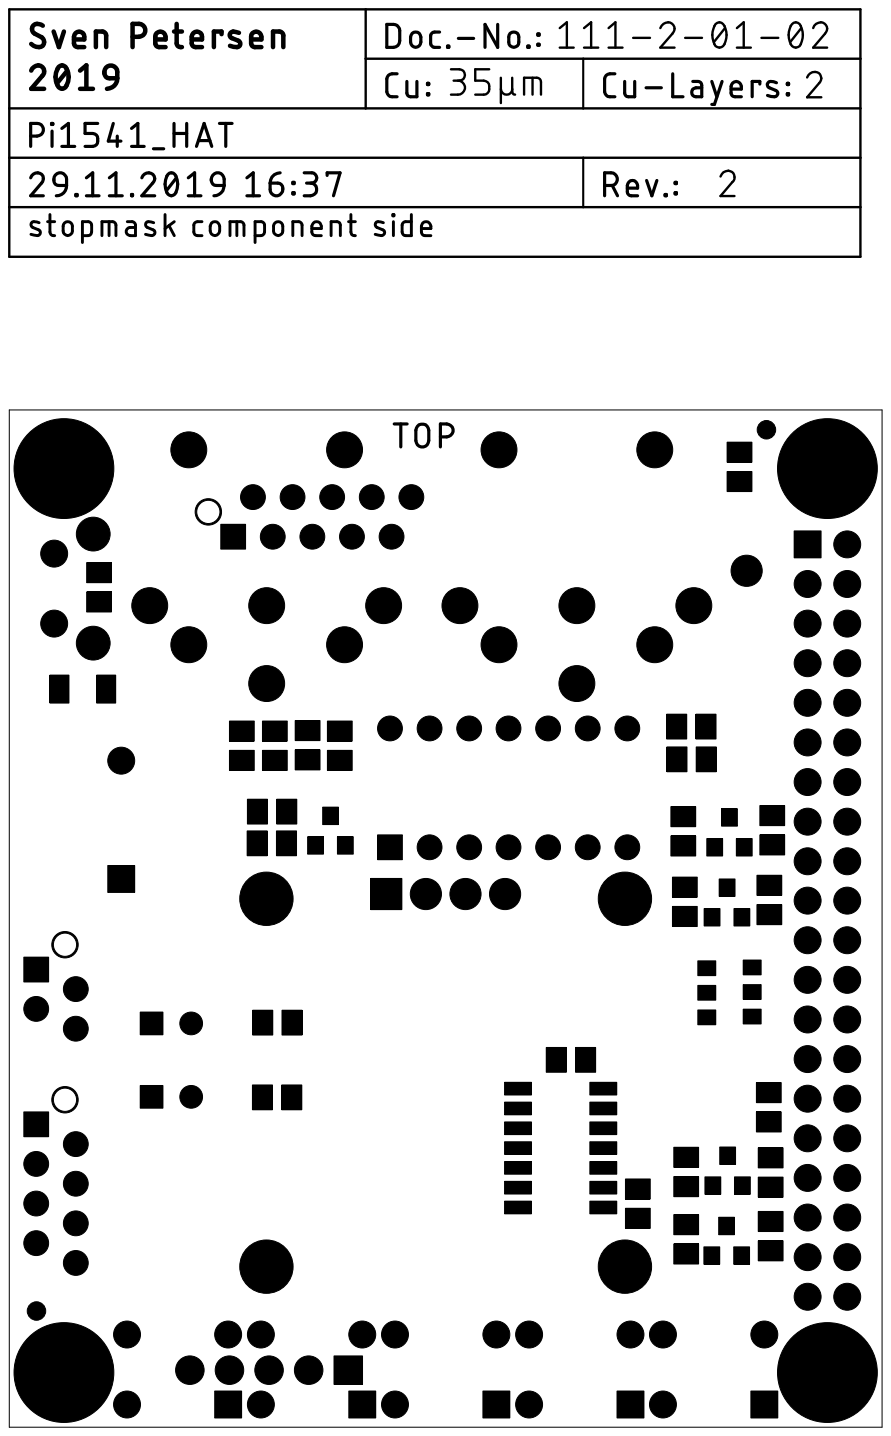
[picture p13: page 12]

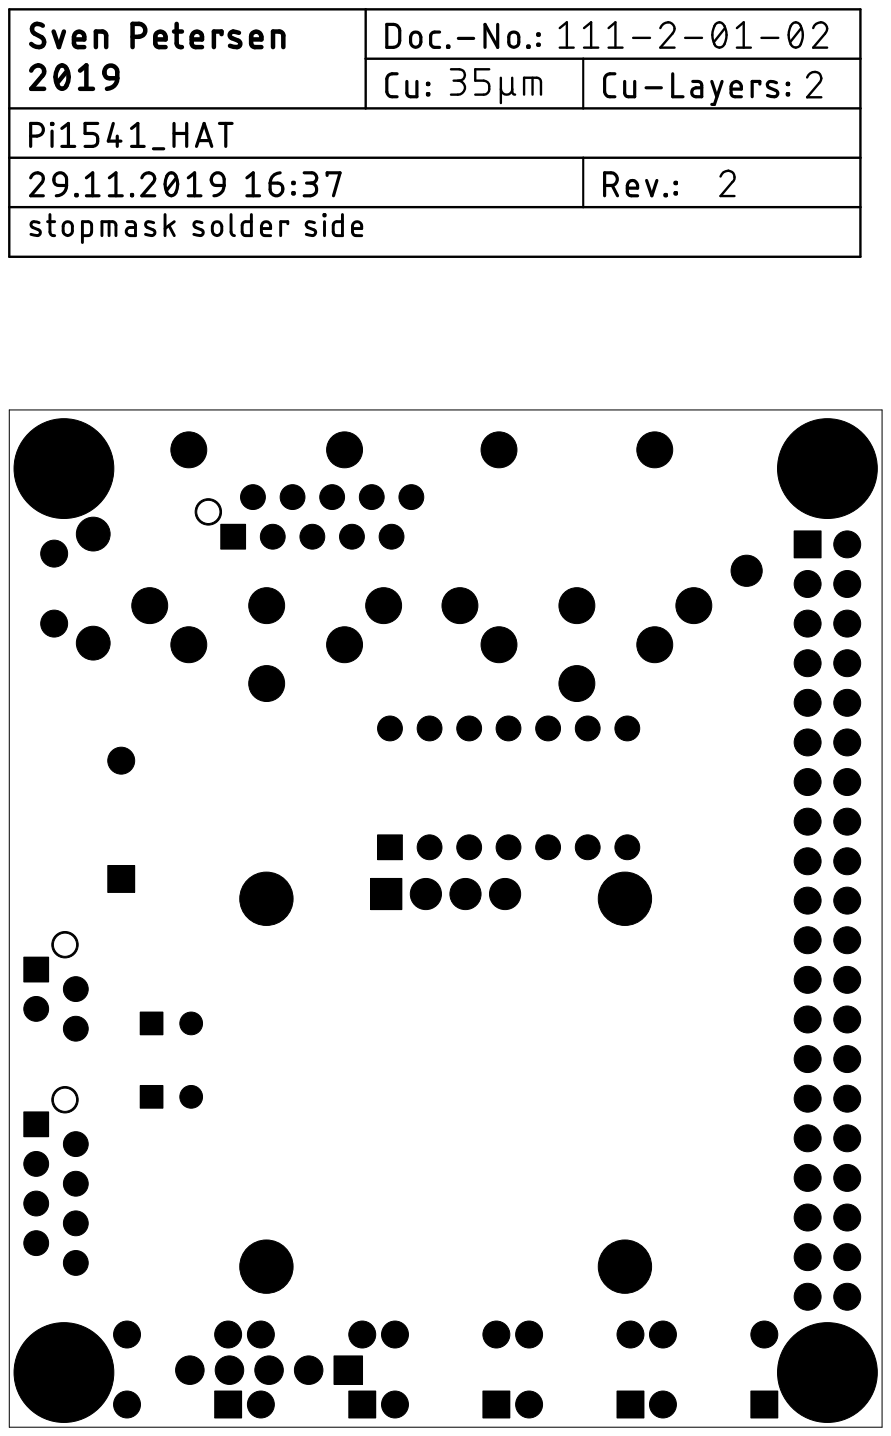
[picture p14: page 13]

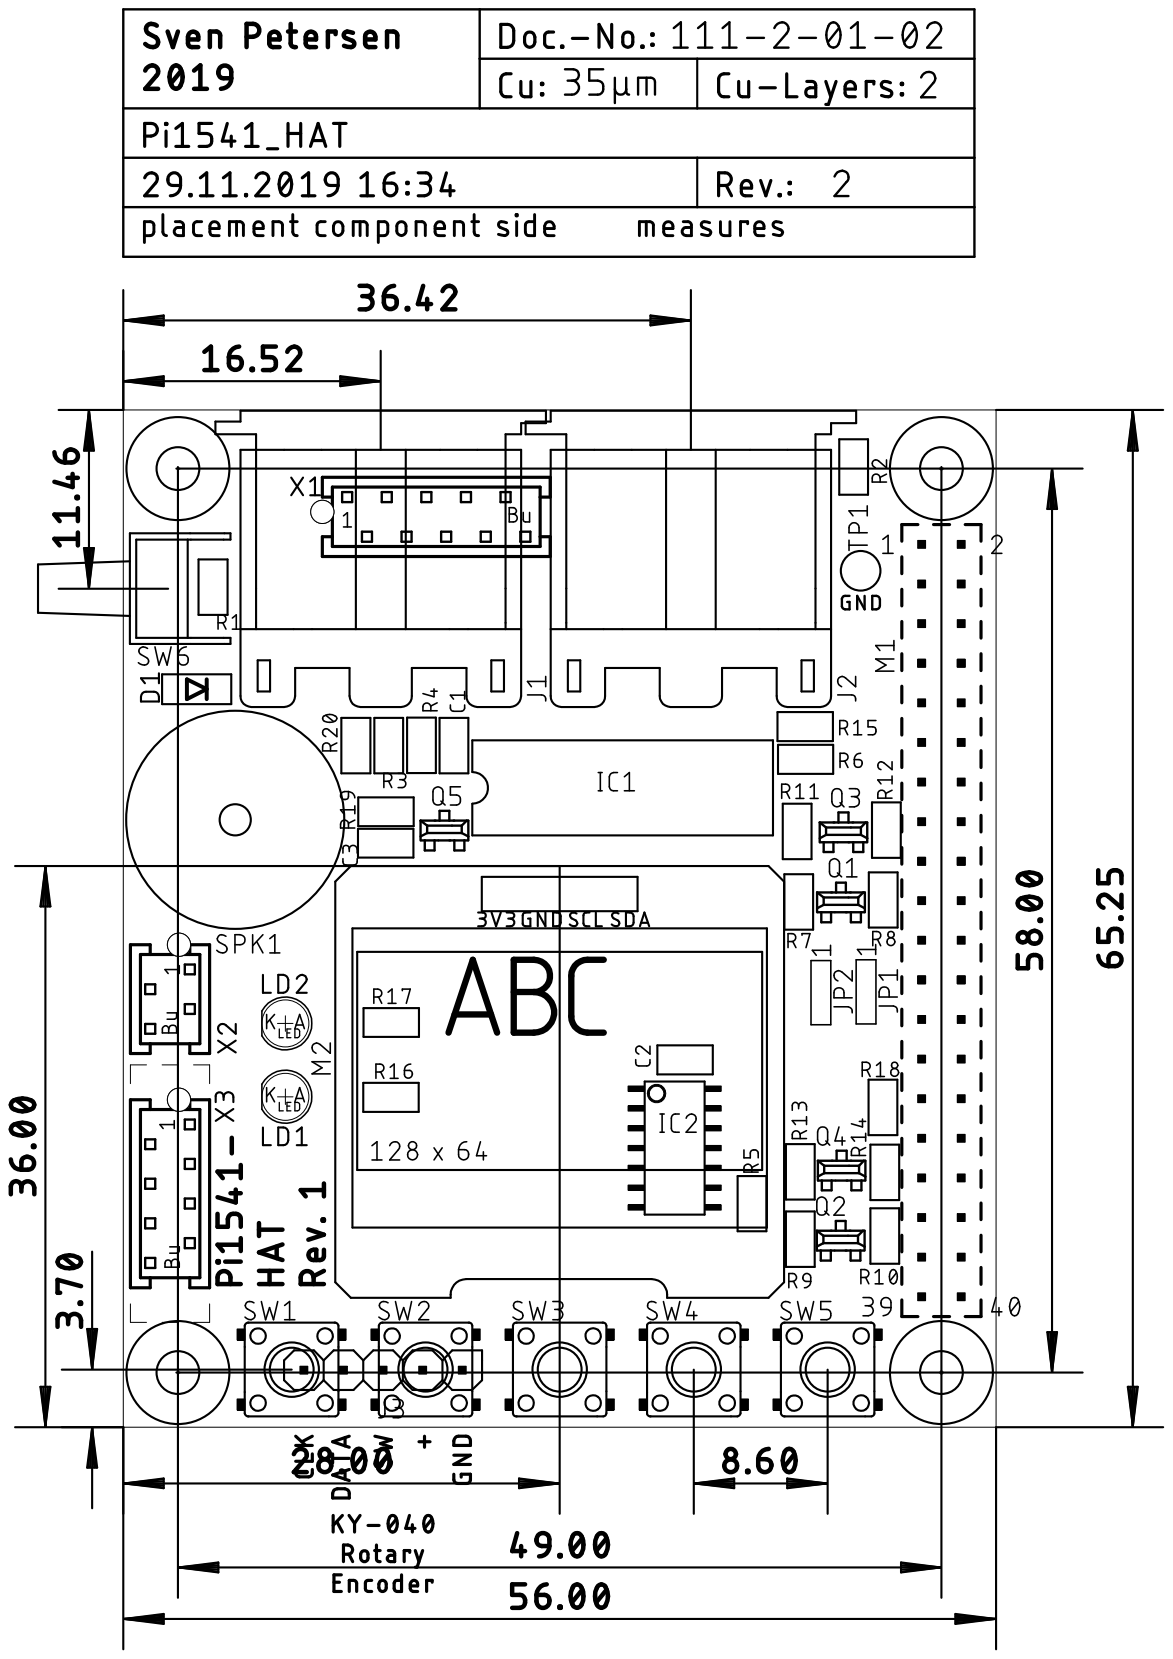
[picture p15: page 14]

Pi1541-HAT_FunB_v2.docx | | 29.11.2019 17:01
Drafted by Sven Petersen | Page 1 of 1 | Doc.-No.: 111-6-02-02

### Pi1541-HAT Rev. 2

### Functional Description

J1 and J2 are the IEC-Bus connectors for the Commodore computers. X1 can be assembled instead of J1 and J2 to make use of an external IEC-Bus PCB.

SW6 is an IEC-Bus RESET switch.

IC1A is the bus driver for the IEC-Bus DATA signal. R3 is the required 1k pull-up-resistor. Since DATA is a bi-directional signal, there is an input stage (IC2A and IC2B), too. This circuit resembled the original 1541 input circuitry. The input signals are inverted twice (which is not required, since the Pi1541 can be configured to use inverted input signals). Q1 in conjunction with R7 and R8 is acting as a 5V/3.3V level shifter. This is a common level shifter circuit as suggested for I²C-bus level shifting by NXP.

The circuit for the CLK signal of the IEC-bus is the same. ATN and /RESET do not have an output stage. The input stage of the /RESET signal is making use of the 74LS06 (IC1). Thus, the pull-up-resistor R6 is required.

M1 is the Raspberry Pi connector.

LD1 is the activity LED. LD2 is the power LED.

Both jumpers JP1 and JP2 should be jumpered 1-2 to drive the display M2 with the primary I²C-Bus of the Raspberry Pi.

### A 0.96” OLED-Display can be connected to M3. In case a 1.3” display is used, the LED and

the switches cannot be populated anymore and an external Pi1541-Switch board is required.

The display can also be connected to the MicroMatch connector X2.

SW1 to SW5 are the user interface for navigating through the directories of the disk archive on the SD-card.

Q5 is driving the piezo buzzer. D1 is acting as a protection, since piezo crystals are generating a voltage, when they are moved/compressed. R20 is required, since the idle level of the SND_OUT signal is HIGH. C3 can be used for sound shaping and additional protection.

TP1 is a ground connection for measurement/debugging.

J3 is for attaching a rotary encoder module. The pinning matches the wide spread KY-040.

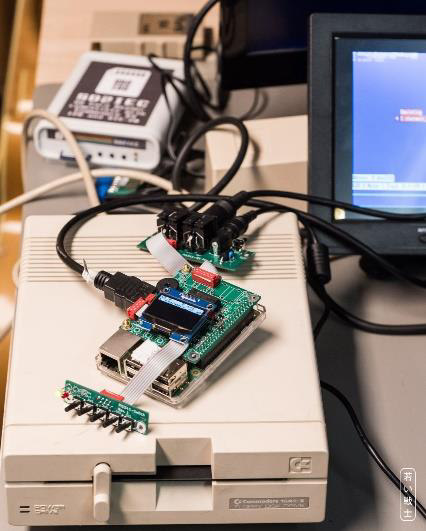
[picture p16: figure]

Pi1541-HAT_Prototype_Testing_v2.docx | | 26.02.2020 14:41
Drafted by Sven Petersen | Page 1 of 3 | Doc.-No.: 111-6-03-01

### Pi1541-HAT Rev. 2

### Prototype Testing

## Test set-up

The testing setup was a C64G (ASSY 250469), standard kernel, no cartridge, connected to the Pi1541 (Device 8) which was then connected to a 1541-II (device 9).

Firmware version of Pi!541 was v1.19 (ROM: CBM DOS V2.6).

Figure 1: Test set-up
The external keyboard “Pi1541 Switch Rev. 1” was attached to the HAT with a ribbon cable (length
15cm) and the external IEC-connectors “Pi1541-IEC Rev. 0” was attached via a ribbon cable of approximately 15cm. The Pi1541 was powered with a 5V/4A PSU via the barrel connector on the Pi5141-IEC.

## Test

Test | Result | Testing
Powering from Micro-USB | Pi1541 boots and is functional | ok
Powering from Barrel connector | Pi1541 boots and is functional | ok
1.3” OLED Display | Shows graphics and lists | ok
SW1 (select/Reset) | Selects Images and leaves them again | ok
SW2 (up) | Scrolling lists works | ok
SW3 (down) | Scrolling lists works | ok
SW4 (Exit Folder) | Exits Folder | ok
SW5 (Insert Disk) | In Browser mode, it enters a directory and leaps to the end of the list. Adding multi disks to a list. | ok
Power LED | Lights up while Pi1541 is powered | ok
Activity LED (LD1) | Lights while drive active | ok
Speaker | Produces sound on track stepping | ok
Loading “Ghost’n’Goblins” | Game loads and plays normally | ok
Loading “Barbarian II” | Loading, flipping disks works, game plays normally | ok

Pi1541-HAT_Prototype_Testing_v2.docx | | 26.02.2020 14:41
Drafted by Sven Petersen | Page 2 of 3 | Doc.-No.: 111-6-03-02
Test | Result | Testing
Loading “Creatures 2” | Loading, flipping disks works, game plays normally | ok
Loading “Defender of the crown” | Disk 1 loads normally and runs. Hooks up on flipping to disk 2. See addendum. | ok
Copying Disk from Pi1541 to 1541-II with DraCopy | Worked several times | ok
Copying Disk from 1541-II to Pi1541 with DraCopy | Worked | ok
Loading the X’2018 demo “drinking buddy” | Demo loads and runs normally | ok
Copying “drinking buddy” to a floppy disk using DraCopy | Disk copied successfully, demo loads and runs normally from a floppy disk (temporarily: Pi1541 disconnected, 1541-II set to device 8) | ok
Copying “drinking buddy” from floppy disk to Pi1541using DraCopy | Disk copied successfully, demo loads and runs normally | ok
Loading X’2018 demo “dsr-x2018.d64” | Demo loads and runs normally | ok
Loading X’2018 demo “frantic4bhf.d64” | Demo loads and runs normally | ok
Loading X’2018 demo “unboxed side1.d64” | Demo loads and runs until inserting the image “unboxed side 2.d64”, then hooks up. See addendum. | ok
Loading X’2018 demo “rewind.d64” | Demo loads and runs normally | ok
Loading X’2018 demo “starwars_s1.d64” | Demo loads and runs normally, flipping to disk 2 (s2): system hooks up” See addendum. | ok
Loading Galencia with Final Cartridge III+ | Game loads and plays normally | ok
Loading L’Abbaye des Morts with Final Cartridge III+ | Game loads and plays normally | ok

## Conclusion

The Pi1541 HAT and all attached boards seem to work properly. The problem with flipping disks occurs with modern software, that is assumed to detect the disk automatically. Leaving
the disk image with “select” (SW1), navigating to the other disk image and selecting is again
is not working in this case. A similar problem was observed when accidentally trying to load something from the P1541, while no disk image was selected. This causes a hook-up of the C64 even in plain BASIC mode. This is considered to be a software issue or a matter of the applied method of flipping disks.

Addendum:
Adding the disks of a multi-disk game or demo works with adding them to a list with SW5. Then flipping disks can be achieved with SW2 and SW3 and select.

The system is fully functional.

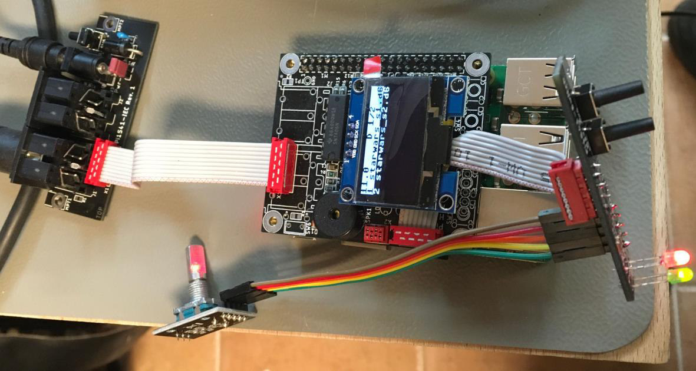
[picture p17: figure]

Pi1541-HAT_Prototype_Testing_v2.docx | | 26.02.2020 14:41
Drafted by Sven Petersen | Page 3 of 3 | Doc.-No.: 111-6-03-02

## Rev. 2

The rotary encoder support of software version v1.2 was tested. The file “options.txt” was modified
for that (add “RotaryEncoderEnable = 1“. The connection of a KY-040 module to the HAT and the switch board, both worked.

Figure 2: Test Setup Rev. 2

The HAT Rev. 2, the Switch Board Rev. 2 and the (new) IEC Rev. 1 were connected and tested:

Loading and saving programs worked properly.

The buttons 4 and 5 (on the Switch board) work as expected.

The STARWARS Demo of X2018 works properly. Some other demos, as well. (Those demos are considered to be good test cases for the Pi1541 firmware).
Ghost’n’goblins loads properly (this is also considered to be a test case for the Pi1541 (7406
drivers).

Conclusion:

Pi1541-HAT Rev. 2, Pi1541-Switch Rev. 2 and Pi1541-IEC Rev. 1 are considered to be fully functional.

Pos. Qty Value Footprint Ref.-No. Comment

1 1 111-2-01-02 2 Layer PCB Rev. 2 2 layer, Cu 35µ, HASL, 56.0mm x 65.25mm, 1.6mm FR4

2 1 369-1-008 MICMA08B X3 MicroMatch MPE, e.g. Reichelt MPE 369-1-008

3 1 372-1-008 (X3) option: MicroMatch MPE, e.g. Reichelt MPE 372-1-008

4 1 0.96IN_OLED_128X64_SS

D1306

OLED_0.96_SSD

1306

M2 0.96" OLED Display 128x64, controller: SSD1306 or

1.3" OLED Display 128x64, controller SH1106

5 1 115-1-004 (M2) option: MPE Garry, e.g. Reichelt MPE 115-1-004

6 2 010599 10599 J1, J2 Lumberg, e.g. Reichelt 010599 06

7 3 100n 0805 C1, C2, C3

8 10 10k 0805 R6, R7, R8, R9, R10, R11, R12,

R13, R14, R15

9 2 150R 0805 R16, R17

10 3 1k 0805 R3, R4, R5

11 1 33R 0805 R19

12 1 3mm_gn 3MM LD2 LED 3mm, green
13 1 3mm_red 3MM LD1 LED 3mm, red

14 1 74LS04D SO-14 IC2

15 1 74LS06N DIL-14 IC1
16 1 BC846B SOT23 Q5

17 4 BSS138 SOT23 Q1, Q2, Q3, Q4

18 2 JMP_0603 CP3P JP1, JP2 Jumper, default: 0R/0603 (1-2)

19 2 0R 0603 (JP1), (JP2)

20 1 JPT1236HB JTP_1236HB SW6 Namae Electronics, e.g. Reichelt TASTER 3305B
21 5 JTP-1130 JTP-1130 SW1, SW2, SW3, SW4, SW5 Namae Electronics, e.g. Reichelt TASTER 9303

22 1 LL4148 SOD80C D1 Diode

23 1 369-1-004 MICMA04B X2 MicroMatch MPE, e.g. Reichelt MPE 369-1-004

24 1 372-1-004 (X2) option: MicroMatch MPE, e.g. Reichelt MPE 372-1-004

25 1 369-1-010 MICMA06B X1 MicroMatch MPE, e.g. Reichelt MPE 369-1-010

26 1 372-1-010 (X1) option: MicroMatch MPE, e.g. Reichelt MPE 372-1-010

27 1 RASPBERRYPI 3B M1 Raspberry Pi 3B or better

## Pi1541-HAT Rev. 2

## Bill of Material Rev. 2.0

Pi1541-HAT_BOM_v2_0.xlsx

Drafted by Sven Petersen Page 1 of 2

29.11.2019 16:31
Doc.No.: 111-5-01-02.0

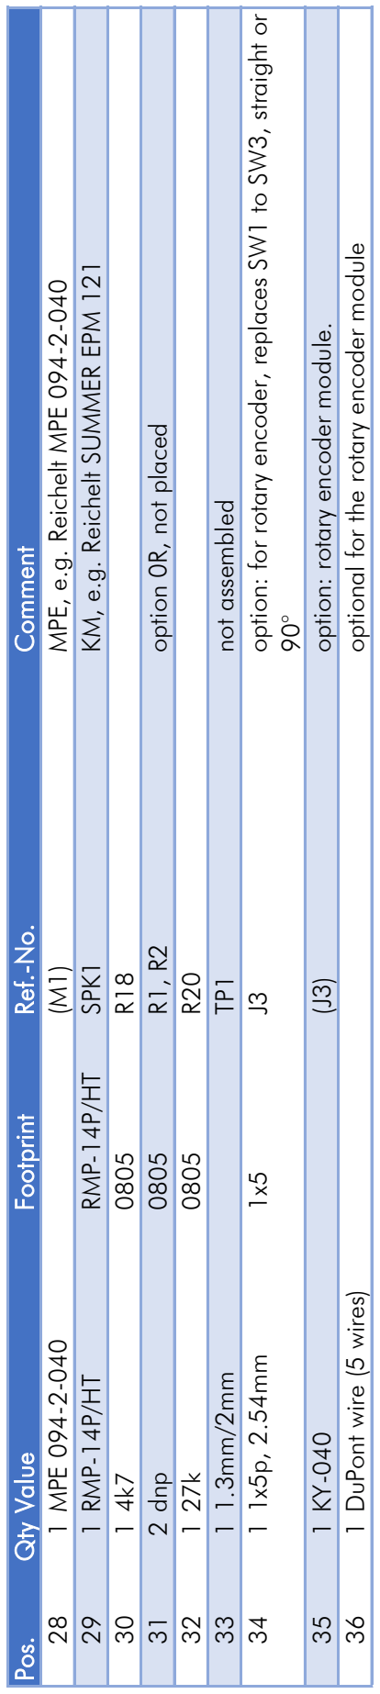
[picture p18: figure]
33 1 1.3mm/2mm TP1 not assembled

Pos. Qty Value Footprint Ref.-No. Comment

## Pi1541-HAT Rev. 2

## Bill of Material Rev. 2.0

28 1 MPE 094-2-040 (M1) MPE, e.g. Reichelt MPE 094-2-040

29 1 RMP-14P/HT RMP-14P/HT SPK1 KM, e.g. Reichelt SUMMER EPM 121

31 2 dnp 0805 R1, R2 option 0R, not placed

34 1 1x5p, 2.54mm 1x5 J3 option: for rotary encoder, replaces SW1 to SW3, straight or

35 1 KY-040 (J3) option: rotary encoder module.

36 1 DuPont wire (5 wires) optional for the rotary encoder module

Pos. Rev. 1 ® Rev. 2

### 1 PCB revision 34 new, option

### 35 new, option

### 36 new, option

Pi1541-HAT_BOM_v2_0.xlsx

Drafted by Sven Petersen Page 2 of 2

29.11.2019 16:31
Doc.No.: 111-5-01-02.0

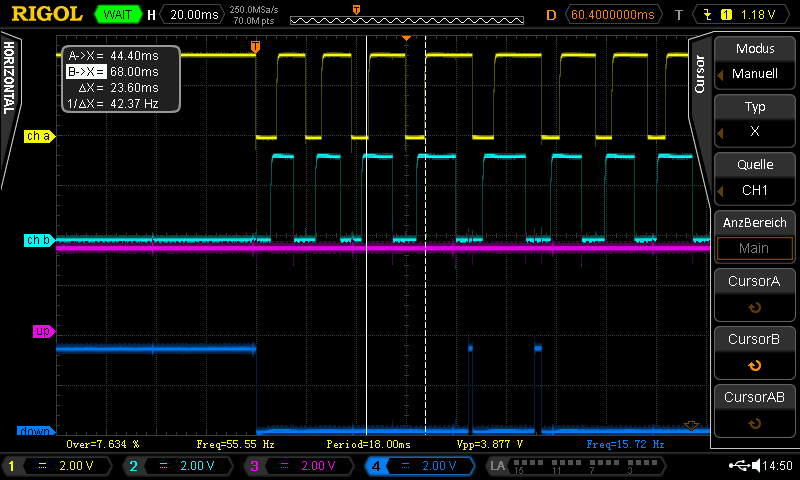
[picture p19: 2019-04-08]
Pi1541/Pi1541-Rot/Rev. 0/pictures/CW_over_75k.png

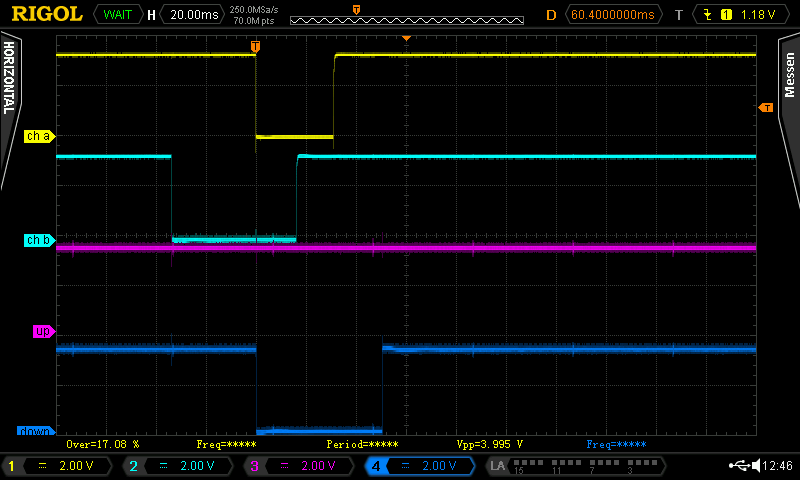
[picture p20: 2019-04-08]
Pi1541/Pi1541-Rot/Rev. 0/pictures/CW_150k.png

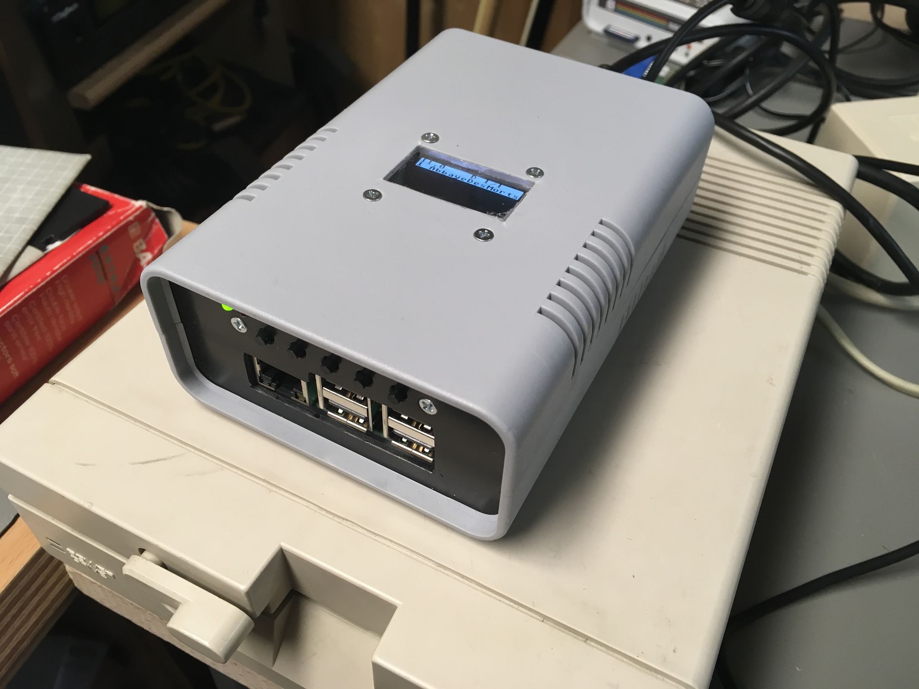
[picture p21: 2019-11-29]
Pi1541/Pi1541-HAT/Rev. 2/pictures/1747_-_Pi1541_in_case.JPG

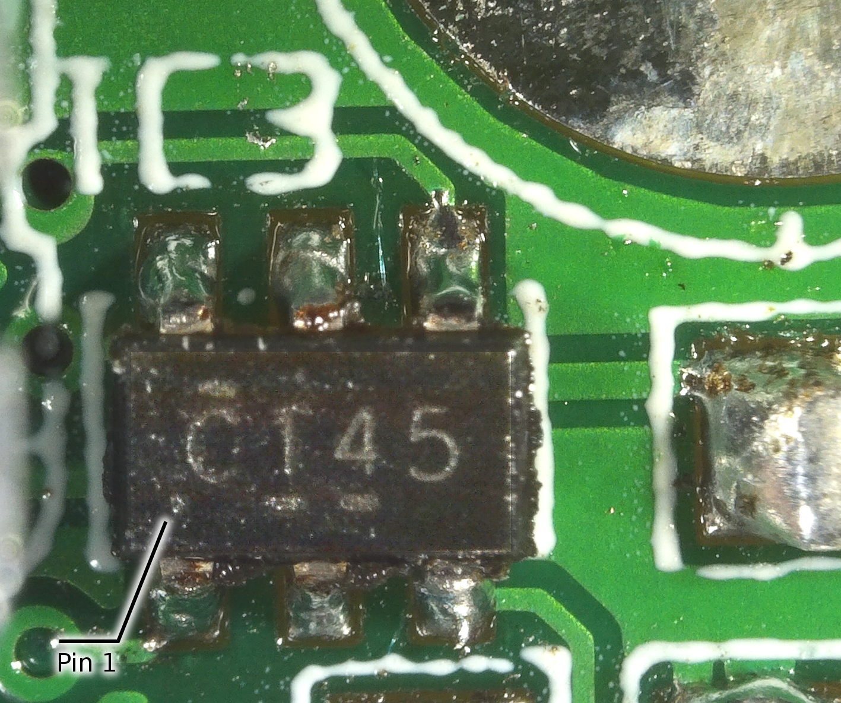
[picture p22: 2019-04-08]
Pi1541/Pi1541-Rot/Rev. 0/pictures/Pi1541-Rot_IC3_plc.JPG

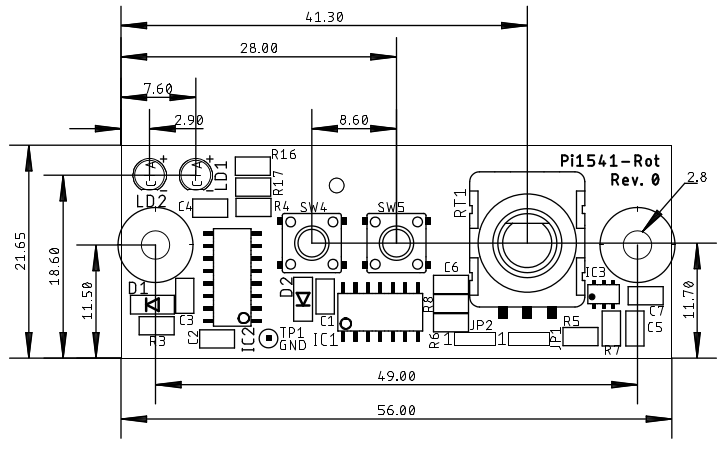
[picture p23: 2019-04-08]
Pi1541/Pi1541-Rot/Rev. 0/pictures/Pi1541-Rot_meas_v0.png

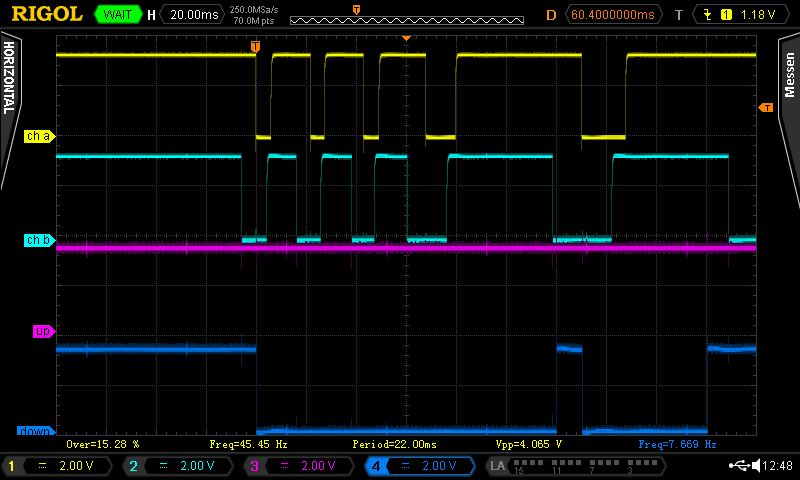
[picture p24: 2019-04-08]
Pi1541/Pi1541-Rot/Rev. 0/pictures/CW_over_150k_2.png

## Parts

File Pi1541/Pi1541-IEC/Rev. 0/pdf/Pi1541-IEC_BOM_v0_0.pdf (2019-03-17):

Pos. | Qty Value | Footprint | Ref.-No. | Comment
1 | 1 115-2-01-00 | 2 Layer | PCB Rev. 0 | 2 layer, Cu 35µ, HASL, LLL x BBB, 1.6mm FR4
2 | 2 10599 | 10599 | J1, J2 | Lumberg, e.g. Reichelt 010599 06
3 | 1 100n | C-2,5 | C1
4 | 1 1N5908 | CB429 | D1 | TVS Diode (5V)
5 | 1 369-1-010 | MICMA10B | X1 | MicroMatch MPE, e.g. Reichelt MPE 369-1-010
6 | 1 372-1-010 | | (X1) | MicroMatch MPE, e.g. Reichelt MPE 372-1-010
6 | 2 5.60.223 | 5.60.223 | MPT1, MPT2 | Ettinger, e.g. Bürklin 17 H 917
7 | 1 FCR681465P | FCR681465P | J3 | Cliff, Reichelt CLIFF FCR681465P
8 | 1 JPT1236HB | JTP_1236HB | SW6 | Namae Electronics, e.g. Reichelt TASTER 3305B
9 | 2 n/a | 0805 | R1, R2 | not assembled

## Pi1541-IEC Rev. 0 Bill of Material Rev. 0.0

Pi1541-IEC_BOM_v0_0.xlsx
Drafted by Sven Petersen | Page 1 of 1

27.02.2019 14:09
Doc.No.: 115-5-01-00.0

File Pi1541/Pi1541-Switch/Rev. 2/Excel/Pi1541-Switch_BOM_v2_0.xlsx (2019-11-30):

Pi1541-Switch Rev. 2
Bill of Material Rev. 2.0
Pos. | Qty | Value | Footprint | Ref.-No. | Comment
1 | 1 | 112-2-01-02 | 2 Layers | PCB Rev. 2 | 2 layers, Cu 35µ, HASL, 13.65mm x 56.0mm, 1.6mm FR4
2 | 1 | 369-1-008 | MICMA08B | X3 | MPE Garry, Reichel MPE 369-1-008, Micromatch, female, tht, 8 pin
3 | 2 | 150R | 0805 | R16, R17 | resistor
4 | 1 | 3mm_gn | 3MM | LD2 | LED, 3mm, green
5 | 1 | 3mm_red | 3MM | LD1 | LED, 3mm, red
6 | 5 | JTP-1130D | JTP-1130 | SW1, SW2, SW3, SW4, SW5 | Namae Electronics, Reichelt JTP-1130, H=13mm
7 | 1 | 1x5p, pitch 2.54mm |  | J3 | Optional for rotary encoder (KY-040 etc.), standard pin header. Replaces SW1, SW2 and SW3
Pos. |  | Rev. 1 ® Rev. 2
1 |  | PCB revision
7 |  | new

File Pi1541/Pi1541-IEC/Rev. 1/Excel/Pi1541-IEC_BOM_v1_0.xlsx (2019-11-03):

Pi1541-IEC Rev. 1
Bill of Material Rev. 1.0
Pos. | Qty | Value | Footprint | Ref.-No. | Comment
1 | 1 | 115-2-01-01 | 2 Layer | PCB Rev. 1 | 2 layer, Cu 35µ, HASL, 71.0mm x 25.5mm, 1.6mm FR4
2 | 2 | 10599 | 10599 | J1, J2 | Lumberg, e.g. Reichelt 010599 06, tme.eu: 0105-06
3 | 1 | 100n | C-2,5 | C1 | ceramic capacitor, pitch: 2.5mm
4 | 1 | 1N5908 | CB429 | D1 | TVS Diode (5V)
5 | 1 | 369-1-010 | MICMA10B | X1 | MicroMatch MPE, e.g. Reichelt MPE 369-1-010, tme.eu 1-215079-0/C
6 | 1 | 372-1-010 |  | (X1) | MicroMatch MPE, e.g. Reichelt MPE 372-1-010, tme.eu: 1-215083-0/C
6 | 2 | 5.60.223 | 5.60.223 | MPT1, MPT2 | Ettinger, e.g. Bürklin 17 H 917 (optional for mounting)
7 | 1 | FCR681465P | FCR681465P | J3 | Cliff, Reichelt: CLIFF FCR681465P, tme.eu: FCR681465P
8 | 1 | JPT1236HB | JTP_1236HB | SW6 | Namae Electronics, e.g. Reichelt TASTER 3305B, tme.eu: TACTA-68N-F
9 | 2 | n/a | 0805 | R1, R2 | not assembled
10 | 1 | jumper 2.54mm |  | JP1 | optional for connecting power switch
 |  | Rev. 0 ® Rev. 1
Pos. | 1 | PCB revision
Pos. | 10 | new

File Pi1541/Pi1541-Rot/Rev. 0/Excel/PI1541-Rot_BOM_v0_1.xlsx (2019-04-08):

Pi1541-Rotary Encoder Board Rev. 0
Bill of Material Rev. 0.1
Pos. | Qty | Value | Footprint | Ref.-No. | Comment
1 | 1 | 118-2-01-00 | 2 Layer | PCB Rev. 0 | 2 layer, Cu 35µ, HASL, LLL x BBB, 1.6mm FR4
2 | 1 | 369-1-008 | MICMA08B | X3 | MPE Garry, Reichel MPE 369-1-008, Micromatch, female, tht, 8 pin
3 | 3 | 100n | 0805 | C1, C2, C7 | cer cap 0805
4 | 4 | 10k | 0805 | R5, R6, R7, R8 | resistor 0805, 5% or better
5 | 2 | 10n | 0805 | C5, C6 | cer cap 0805
6 | 2 | 150R | 0805 | R16, R17 | resistor 0805, 5% or better
7 | 2 | 100k | 0805 | R3, R4 | resistor 0805, 5% or better
8 | 2 | 1u | 0805 | C3, C4 | cer cap 0805, 10% or better, e.g. Reichelt X5R 0805 CD 1,0U
9 | 1 | 3mm_gn | 3MM | LD2 | LED, 3mm, green, e.g. Reichelt LED 3MM GN
10 | 1 | 3mm_red | 3MM | LD1 | LED, 3mm, red, e.g. Reichelt LED 3MM RT
11 | 2 | JMP_0603 | CP3P | JP1, JP2 | Jumper (in copper, no sourcable part), 0R resistor (0603) placed 1-2 by default
12 | 1 | 0R | 603 | (JP1), (JP2) | resistor 0603, placed on SMD jumper, e.g. Reichelt RND 0603 0
13 | 2 | JTP-1130 | JTP-1130 | SW4, SW5 | Namae Electronics, Reichelt JTP-1130, H=13mm
14 | 2 | LL4148 | SOD80C | D1, D2 | Diode, MINIMELF
15 | 1 | SN74HC123D | SO-16 | IC2 | e.g. TI, Toshiba, etc. Reichelt: SMD HC 123
16 | 1 | SN74HC74D | SO-14 | IC1 | e.g. NXP, Reichelt: SMD HC 74
17 | 1 | knob for rotary axis 6 mm |  | (RT1) | e.g. Reichelt KNOPF 10-150B
18 | 1 | STEC11B13 | STEC11B13 | RT1 | Alps, Reichelt: STEC11B13
19 | 2 | n/a | 0805 | R1, R2 | not assembled
20 | 1 | SN74LVC2G14 | SOT23-6 | IC3 | TI, e.g. Reichelt SN 74LVC2G14DBV
 |  | Revision History
Pos |  | v0.0 -> v0.1
7 |  | Value | R3/4
8 |  | Reichelt P/N | C3/4

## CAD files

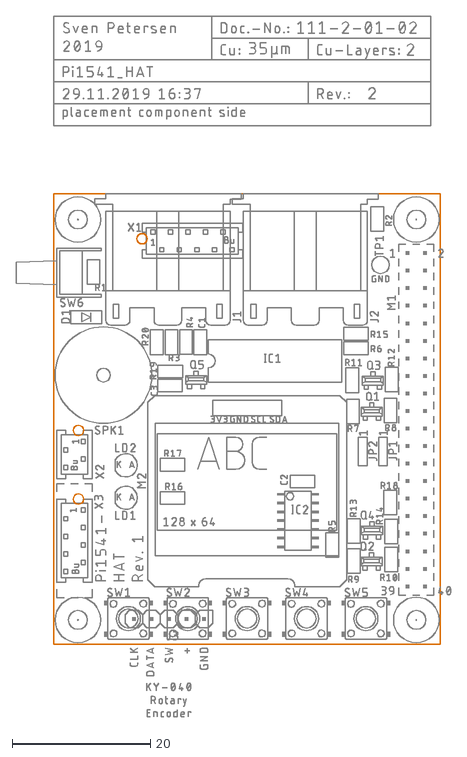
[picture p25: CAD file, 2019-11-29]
Pi1541/Pi1541-HAT/Rev. 2/dxf/Pi1541_HAT.dxf
63.0 x 101.5

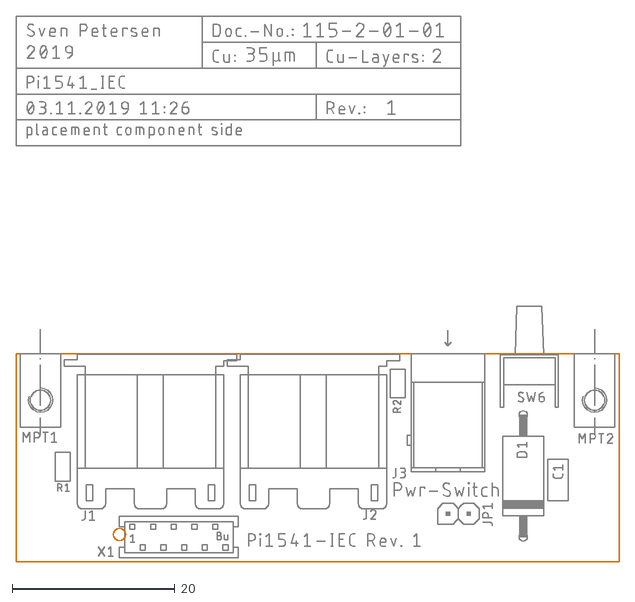
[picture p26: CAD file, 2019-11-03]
Pi1541/Pi1541-IEC/Rev. 1/dxf/Pi1541_IEC.dxf
74.0 x 66.9

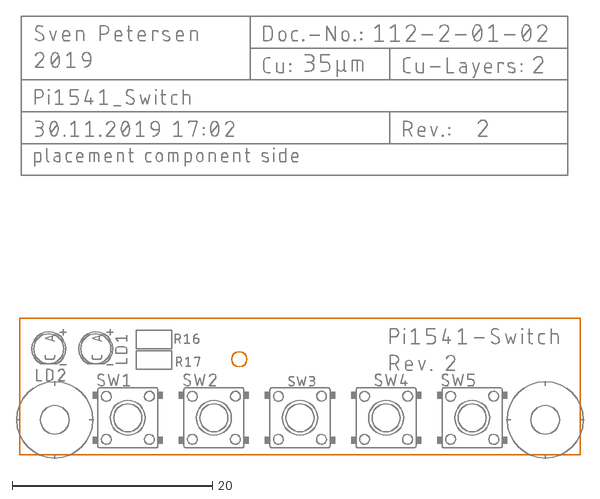
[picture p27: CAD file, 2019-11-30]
Pi1541/Pi1541-Switch/Rev. 2/dxf/Pi1541_Switch.dxf
56.7 x 44.2

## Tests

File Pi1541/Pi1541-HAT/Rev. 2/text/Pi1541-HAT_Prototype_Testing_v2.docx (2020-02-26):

Pi1541-HAT Rev. 2

Prototype Testing

# Test set-up

The testing setup was a C64G (ASSY 250469), standard kernel, no cartridge, connected to the Pi1541 (Device 8) which was then connected to a 1541-II (device 9).

Firmware version of Pi!541 was v1.19 (ROM: CBM DOS V2.6).

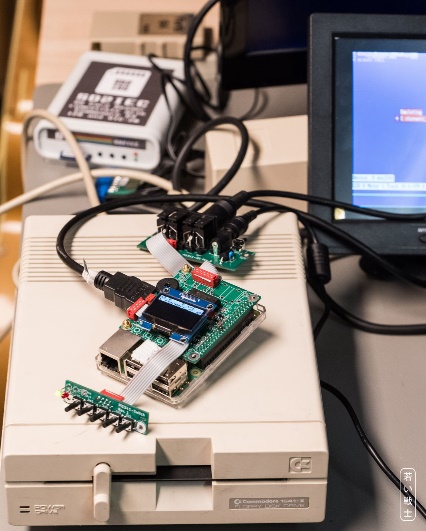
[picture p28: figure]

Figure 1: Test set-up

The external keyboard “Pi1541 Switch Rev. 1” was attached to the HAT with a ribbon cable (length 15cm) and the external IEC-connectors “Pi1541-IEC Rev. 0” was attached via a ribbon cable of approximately 15cm. The Pi1541 was powered with a 5V/4A PSU via the barrel connector on the Pi5141-IEC.

# Test

Test | Result | Testing
Powering from Micro-USB | Pi1541 boots and is functional | ok
Powering from Barrel connector | Pi1541 boots and is functional | ok
1.3” OLED Display | Shows graphics and lists | ok
SW1 (select/Reset) | Selects Images and leaves them again | ok
SW2 (up) | Scrolling lists works | ok
SW3 (down) | Scrolling lists works | ok
SW4 (Exit Folder) | Exits Folder | ok
SW5 (Insert Disk) | In Browser mode, it enters a directory and leaps to the end of the list. Adding multi disks to a list. | ok
Power LED | Lights up while Pi1541 is powered | ok
Activity LED (LD1) | Lights while drive active | ok
Speaker | Produces sound on track stepping | ok
Loading “Ghost’n’Goblins” | Game loads and plays normally | ok
Loading “Barbarian II” | Loading, flipping disks works, game plays normally | ok
Loading “Creatures 2” | Loading, flipping disks works, game plays normally | ok
Loading “Defender of the crown” | Disk 1 loads normally and runs. Hooks up on flipping to disk 2. See addendum. | ok
Copying Disk from Pi1541 to 1541-II with DraCopy | Worked several times | ok
Copying Disk from 1541-II to Pi1541 with DraCopy | Worked | ok
Loading the X’2018 demo “drinking buddy” | Demo loads and runs normally | ok
Copying “drinking buddy” to a floppy disk using DraCopy | Disk copied successfully, demo loads and runs normally from a floppy disk (temporarily: Pi1541 disconnected, 1541-II set to device 8) | ok
Copying “drinking buddy” from floppy disk to Pi1541using DraCopy | Disk copied successfully, demo loads and runs normally | ok
Loading X’2018 demo “dsr-x2018.d64” | Demo loads and runs normally | ok
Loading X’2018 demo “frantic4bhf.d64” | Demo loads and runs normally | ok
Loading X’2018 demo “unboxed side1.d64” | Demo loads and runs until inserting the image “unboxed side 2.d64”, then hooks up. See addendum. | ok
Loading X’2018 demo “rewind.d64” | Demo loads and runs normally | ok
Loading X’2018 demo “starwars_s1.d64” | Demo loads and runs normally, flipping to disk 2 (s2): system hooks up” See addendum. | ok
Loading Galencia with Final Cartridge III+ | Game loads and plays normally | ok
Loading L’Abbaye des Morts with Final Cartridge III+ | Game loads and plays normally | ok

# Conclusion

The Pi1541 HAT and all attached boards seem to work properly. The problem with flipping disks occurs with modern software, that is assumed to detect the disk automatically. Leaving the disk image with “select” (SW1), navigating to the other disk image and selecting is again is not working in this case. A similar problem was observed when accidentally trying to load something from the P1541, while no disk image was selected. This causes a hook-up of the C64 even in plain BASIC mode. This is considered to be a software issue or a matter of the applied method of flipping disks.

Addendum:
Adding the disks of a multi-disk game or demo works with adding them to a list with SW5. Then flipping disks can be achieved with SW2 and SW3 and select.

The system is fully functional.

# Rev. 2

The rotary encoder support of software version v1.2 was tested. The file “options.txt” was modified for that (add “RotaryEncoderEnable = 1“. The connection of a KY-040 module to the HAT and the switch board, both worked.

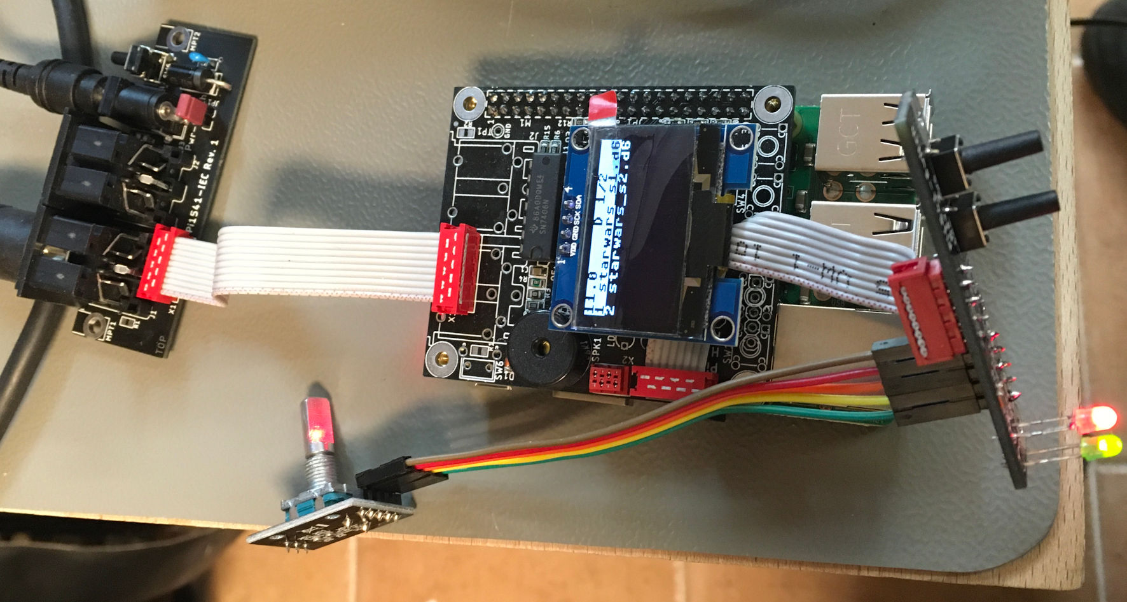
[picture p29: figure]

Figure 2: Test Setup Rev. 2

The HAT Rev. 2, the Switch Board Rev. 2 and the (new) IEC Rev. 1 were connected and tested:

Loading and saving programs worked properly.

The buttons 4 and 5 (on the Switch board) work as expected.

The STARWARS Demo of X2018 works properly. Some other demos, as well. (Those demos are considered to be good test cases for the Pi1541 firmware).

Ghost’n’goblins loads properly (this is also considered to be a test case for the Pi1541 (7406 drivers).

Conclusion:

Pi1541-HAT Rev. 2, Pi1541-Switch Rev. 2 and Pi1541-IEC Rev. 1 are considered to be fully functional.

Pi1541-HAT_Prototype_Testing_v2.docx 26.02.2020 14:35 Drafted by Sven Petersen Page 2 of 2 Doc.-No.: 111-6-03-02

Pi1541-HAT_Prototype_Testing_v2.docx 26.02.2020 14:35 Drafted by Sven Petersen Page 1 of 1 Doc.-No.: 111-6-03-01

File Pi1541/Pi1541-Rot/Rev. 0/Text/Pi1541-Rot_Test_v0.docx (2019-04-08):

Pi1541 – Rotary Encoder Board Rev. 0

Prototype Testing

# Test Setup

The Board was connected to the existing Pi1541 setup, replacing the switch board. The software running on the Pi1541 is v1.19 (not modified).

A 4-channel oscilloscope was connected to the two rotary encoder outputs and the outputs for the up and down switch. The latter outputs are active low, that means a pulse is present while low level.

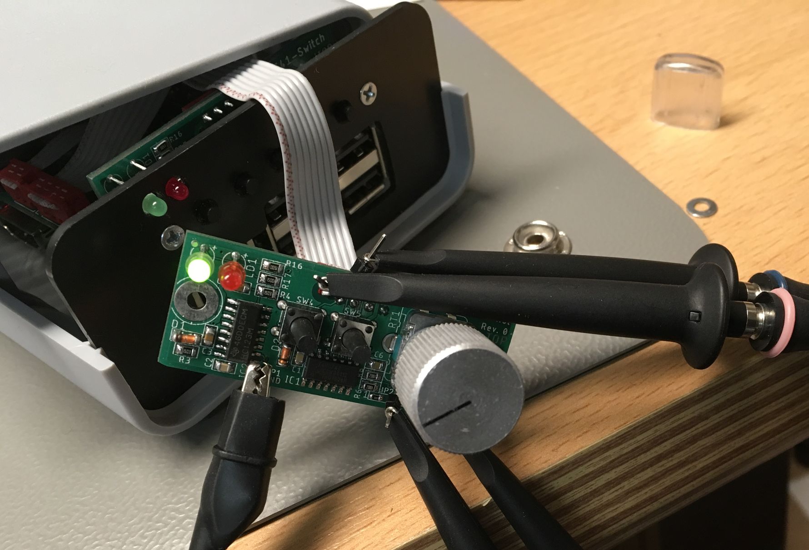
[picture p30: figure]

Figure 1: Test setup

# Test Results

Test | Result | Testing
Turning the rotary encode CW | Proper function as a down switch (SW3) | Ok
Turning the rotary encoder CCW | Proper function as an up switch (SW2 | Ok
Pushing the rotary encode | Proper function as the select switch (SW1) | Ok
Pushing Switch SW4 | Proper function as a back switch | Ok
Pushing Switch SW5 | Proper function as an insert disk switch | Ok
Turning the rotary encoder fast (in every direction) | Some pulses get lost. It seems that the Pi1541 is not fast enough to follow. The more to scroll on the display, the more pulses get lost. | It does not influence the usability in a bad way. Ok.
Optimizing the mono-flop timing: R3 and R4 replaced with 47k | Pulses too short for the Pi1541 to detect | Not ok.
Optimizing the mono-flop timing: R3 and R4 replaced with 100k | Pulses are detected by the Pi1541 software. Pulse length 33ms | Ok.
Optimizing the mono-flop timing: R3 and R4 replaced with 75k | Pulses are detected by the Pi1541 software. Pulse length 26ms | Ok.


Figure 2: Turning clockwise (R3/4=150k) Þ Pulses on the „down-channel” (SW3)

Figure 2 shows the signals of the rotary encode (ch a and ch b) and the output signals issued in the up-switch (SW2) and down-switch channel (SW3). When turning clockwise, the (low) pulse is issued on the “down” channel.

Turning counter-clockwise is shown in Figure 3. The pulse width od the pulses is determined by the capacitors C3 and C4 (both 1u) and the resistors R3 and R4. Turning the rotary encoder too fast is resulting in “wide pulses”, the mono-flop is retriggered while the set time is elapsing, thus a pulse is lost. This shown in Figure 4. The first four ticks on the rotary encoder result in one pulse.

To increase the possible speed of the rotary encode, the resistors R3/R4 are modified. A value of 47k instead of the original 150k for these resistors results in the rotary encoder is not recognized by the Pi1541 software at all. In this case the pulse width is approximately 17ms. The resistor values were increased to 100k, the rotary encoder was effective again. The capacitors have a tolerance of 10%. Proving, that the value of 100k is suitable, two 75k resistors were soldered in. The output signals were recognized by the Pi1541 software.

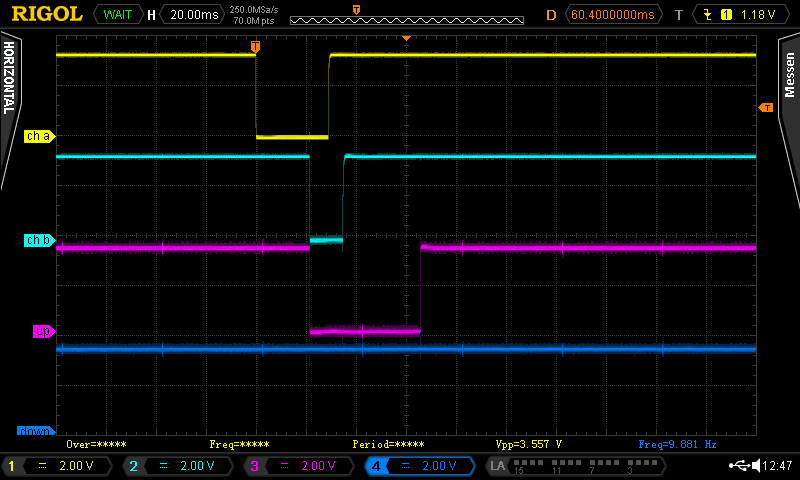
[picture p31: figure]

Figure 3: Turning counter-clockwise (R3/4=150k) Þ Pulses on the „up-channel” (SW2)


Figure 4: Turning CW too fast

# Assembly

The latches at the side of the rotary encoder were a bit tight fit, the component could be installed, though. In future revisions, the size of the holes should be increased from 2.4mm to 2.6mm.

IC3 does not have a Pin 1 mark on the top silk layer, it is only included in the documentation print out (layer 51 tDocu). This can be improved in the library.

# Conclusion

The rotary encoder board is fully functional and the lost pulses, when turning too fast are not considered as a problem. A rate of approximately 15 clicks per seconds can be achieved by the hardware. One complete turn of the rotary encoder are 20 clicks. In case the file/directory names are long, the scrolling is slower than if the names to be scrolled are short. The rotary encoder speeds up the navigation a lot compared to navigating with the buttons. It is much more comfortable to use.

Pi1541-Rot_Test_v0.docx 08.04.2019 16:59 Drafted by Sven Petersen Page 2 of 2 Doc.-No.: 118-6-03-00

Pi1541-Rot_Test_v0.docx 08.04.2019 16:59 Drafted by Sven Petersen Page 1 of 1 Doc.-No.: 118-6-03-00

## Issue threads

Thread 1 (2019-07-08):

(FR) add on/off switch next to the barrel connector

r10513, 2019-07-08:
In this way user can turn off her pi1541 without unplugging the power jack from the barrel.

svenpetersen1965, 2019-11-03:
Good idea. I will do it in a revision.

svenpetersen1965, 2019-11-03:
Done.

Closed 2019-11-07.

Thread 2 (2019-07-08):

(FR) swap positions of iec bus and switches bus

r10513, 2019-07-08:
This mod will enable users with Raspberry PI 3A/3A+ to have the connectors for serial cables where normally are the ethernet jack and the 4 USB sockets. Rpi 3a is shorter than Rpi 3b.

svenpetersen1965, 2019-11-07:
I have done it.

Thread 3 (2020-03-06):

Input-Stage Question

drachenminister, 2020-03-06:
Your are using a 74LS04 in the Input-Stages for DATA_IN, CLK_IN and ATN_IN and Level-Shifting via BSS138s and 10K resistors.

Would it be possible to use something like a [74HC4049 Hex inverting HIGH-to-LOW level shifter](https://assets.nexperia.com/documents/data-sheet/74HC4049.pdf) running off of 3.3v instead?

Or is there a problem with it beeing push-pull and not open collector?

Also, as it should be possible to only invert the signals once (ore use the non inverting 74HC4050) one could make room for RESET_IN as well an get rid of the BSS138s and 10K resitors all together.

But then there is a second pull-up resistor between the two inverters on the RESET_IN which baffels me.

lg
Martin Schneider

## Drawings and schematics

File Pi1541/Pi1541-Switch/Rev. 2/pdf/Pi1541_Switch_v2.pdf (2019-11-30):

# Documentation

## Pi1541 - Switch

## Project number: 112

## Revision: 2

## Date: 30.11.2019

Pi1541-Switch_ModB_v2.docx | | 30.11.2019 16:55
Drafted by Sven Petersen | Page 1 of 2 | Doc.-No.: 112-6-01-02

### Pi1541 – Switch Rev. 2

### Module description

## Description

The Pi1541-Switch is a detachable switch board for the Pi1541 HAT (project number 111). The connector to the Pi1541 HAT is placed on the solder side of the PCB. Further on, the switches SW1, SW2 and SW3 can be replaced by a pin header (J3, placed on the solder side), which is designed for connecting a rotary encoder module (such as the KY-040), which is supported since the Pi1541 kernel v1.21, which was released in November 2019.

## Switches

The switches have functions according to the firmware and configuration, which can be found at this website: https://cbm-pi1541.firebaseapp.com/

The default configuration is:

Switch | Function
SW1 (left) | Select/Reset
SW2 | Move Up/Previous Disk
SW3 | Move Down/Next Disk
SW4 | Exit Folder
SW5 (right) | Insert Disk

## LEDs

LED | Color | Function
LD2 | Green | Power Indicator
LD1 | Red | Busy Indicator

## Connector

X3: 8p Micro Match, female, THT (Tyco or alternative)

The ribbon cable can also be soldered in directly.

Pin | Signal
1 /SW1
2 /SW2
3 /SW3
4 /SW4
5 /SW5
6 LED_OUT (LD1)
7 +3V3
8 GND

Pi1541-Switch_ModB_v2.docx | | 30.11.2019 16:55
Drafted by Sven Petersen | Page 2 of 2 | Doc.-No.: 112-6-01-02

### Rotary Encoder connector

J3 – 5-pin pin header (2.54mm pitch) vertical or 90°.

Pin Signal
1 GND
2 +3V3
3 SW (/SW1_IN)
4 DATA (/SW3_IN)
5 CLK (/SW2_IN)

## Measures

Can be found in the board print out

## Revision History

Rev. 0: Prototype

Rev. 1: Moved the connector X3 to the solder side

Rev. 2: added J3 for connecting the rotary encoder.

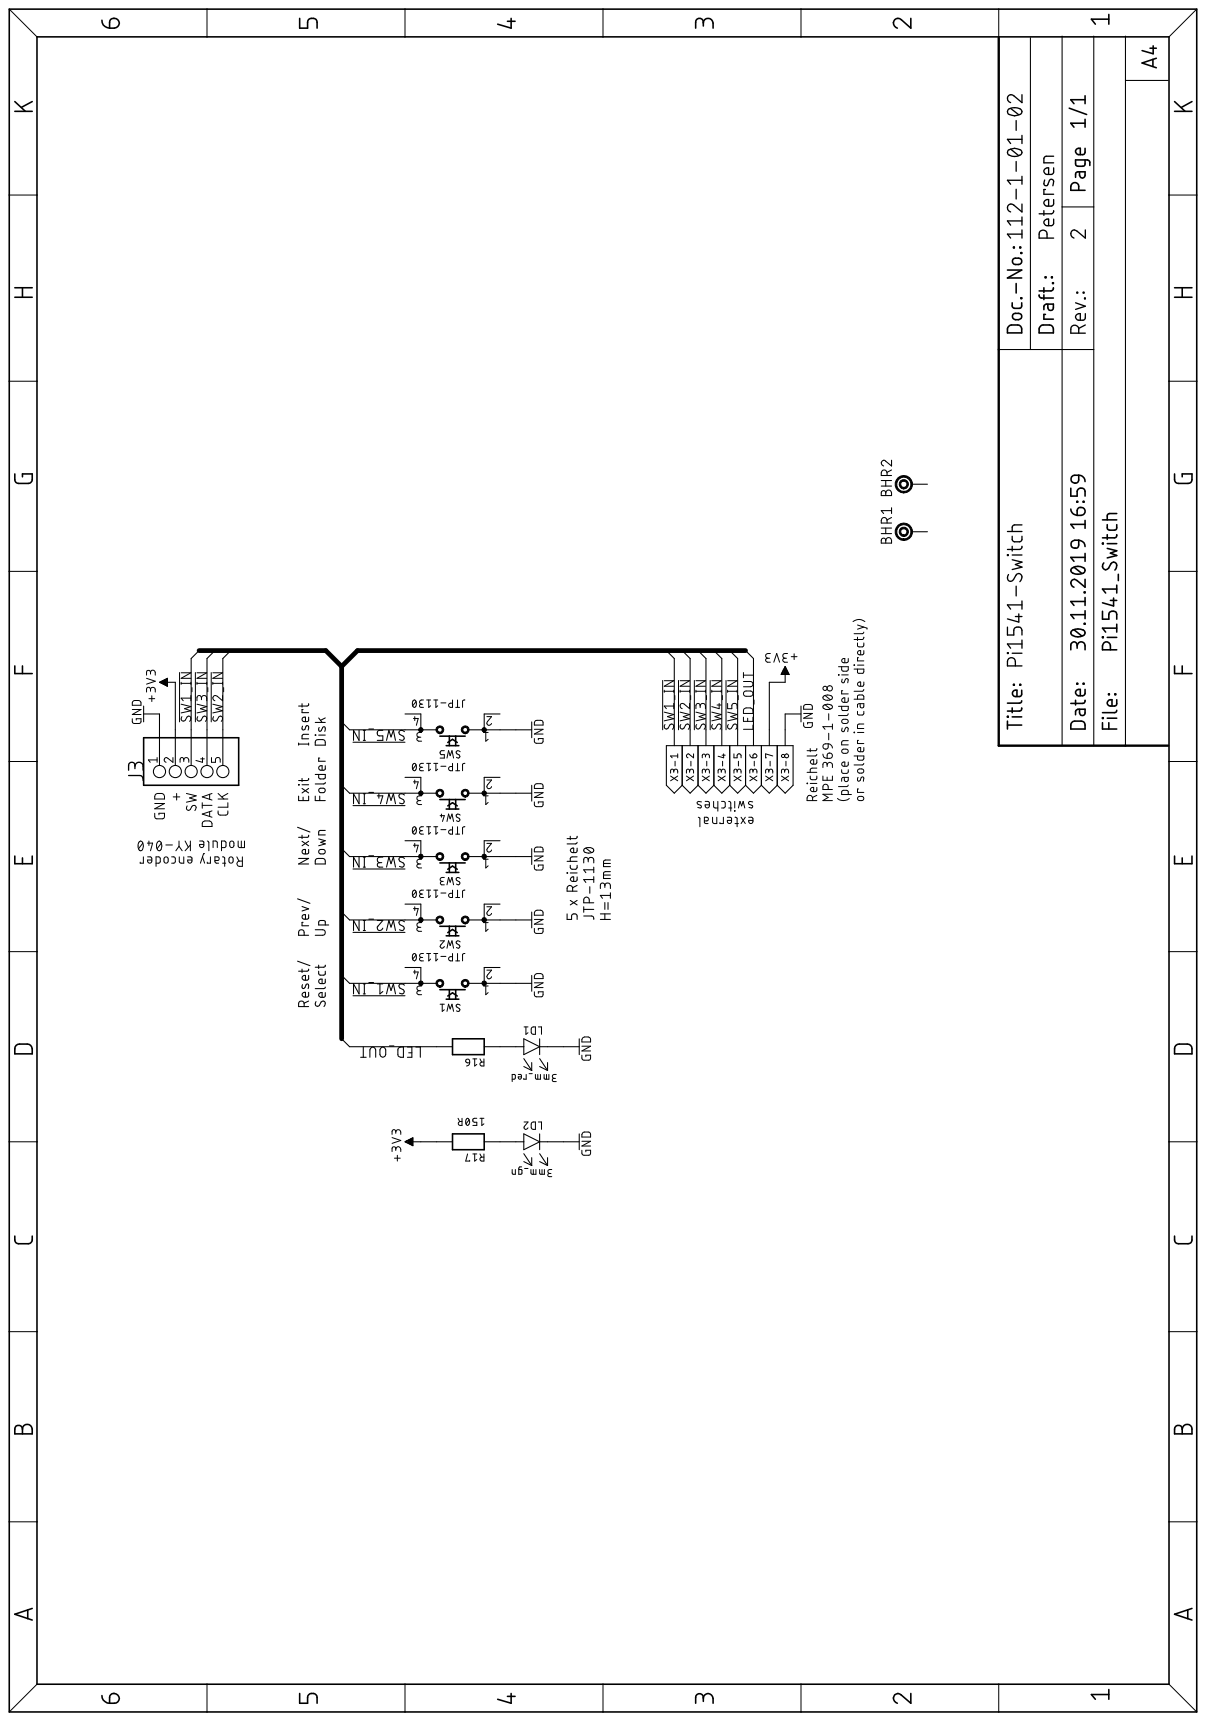
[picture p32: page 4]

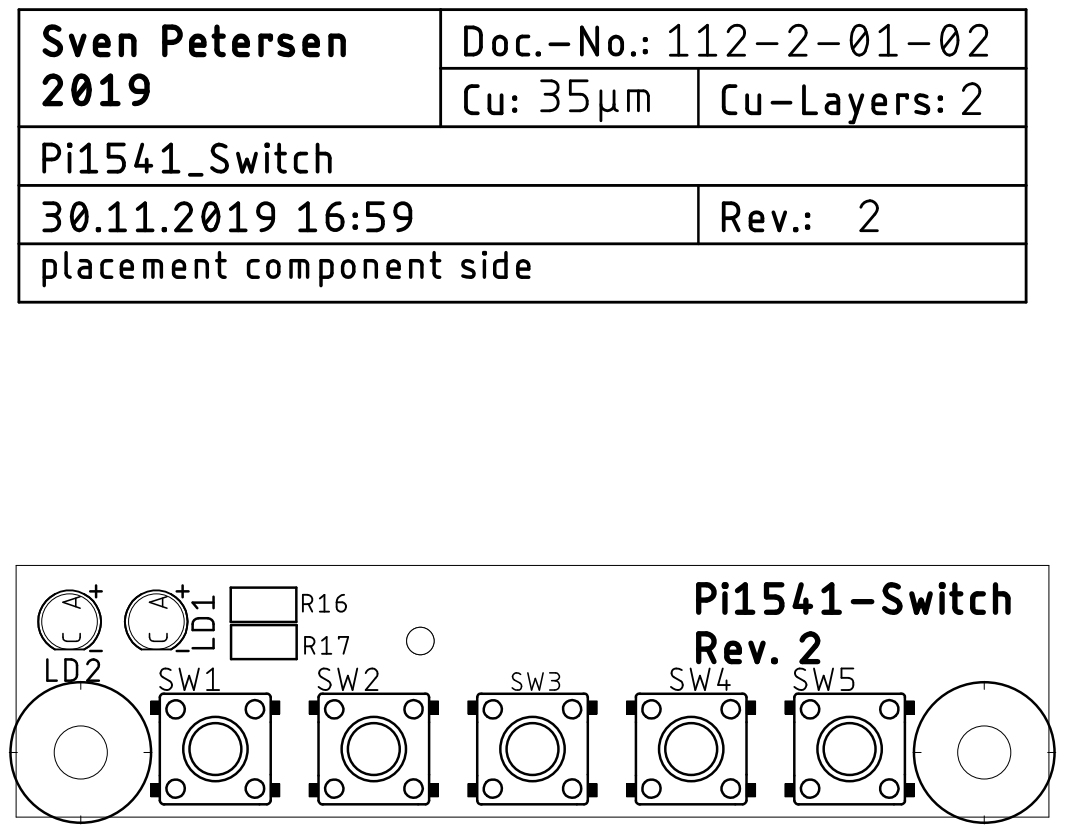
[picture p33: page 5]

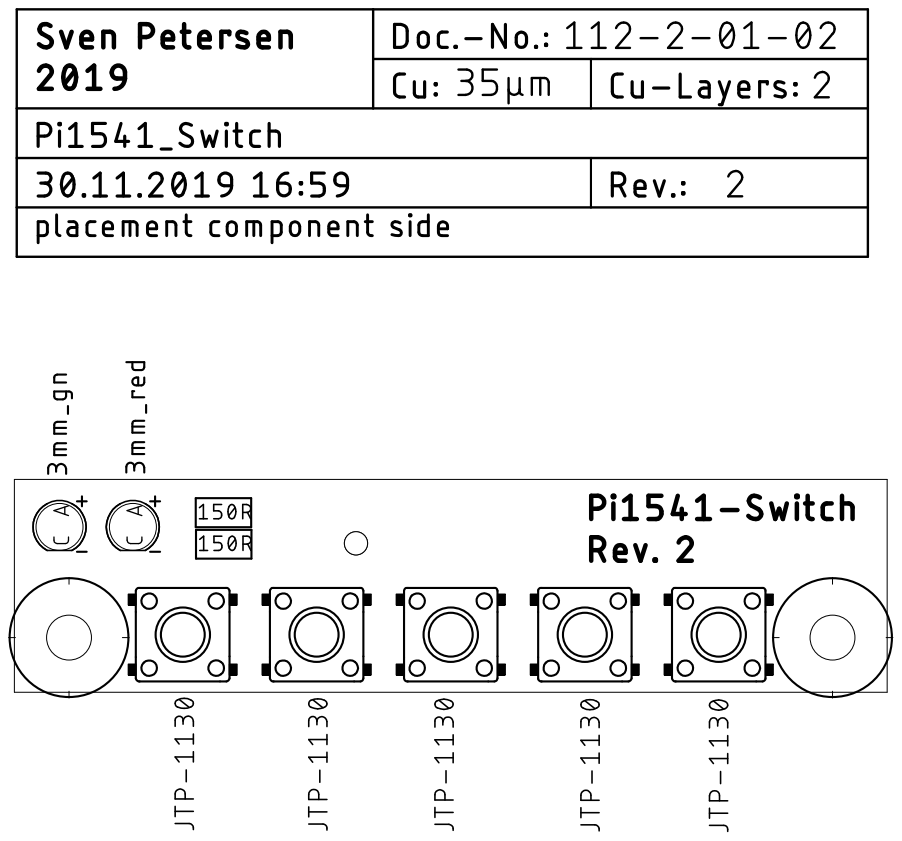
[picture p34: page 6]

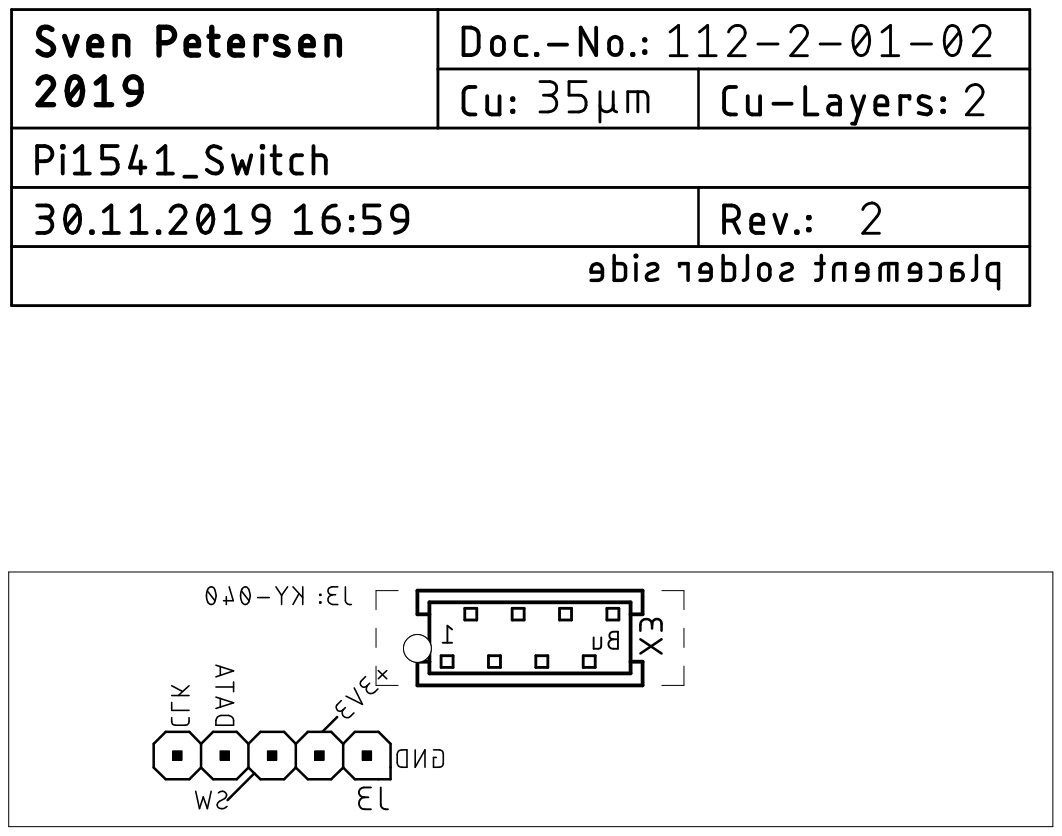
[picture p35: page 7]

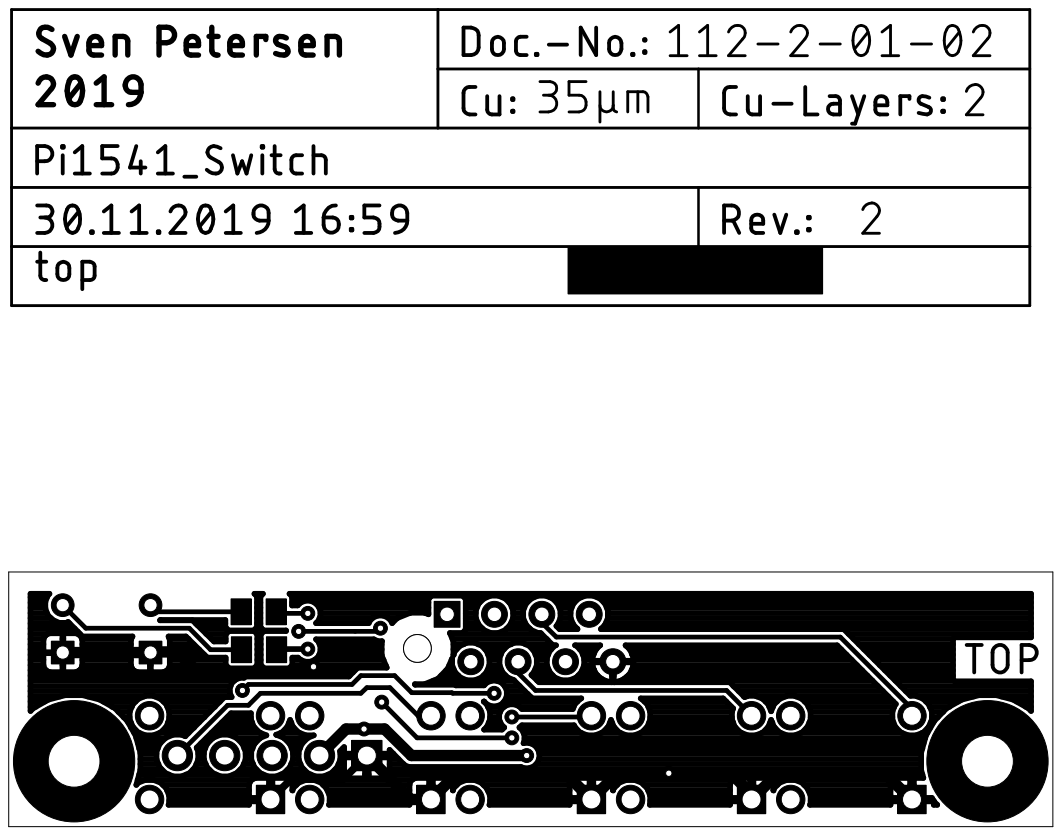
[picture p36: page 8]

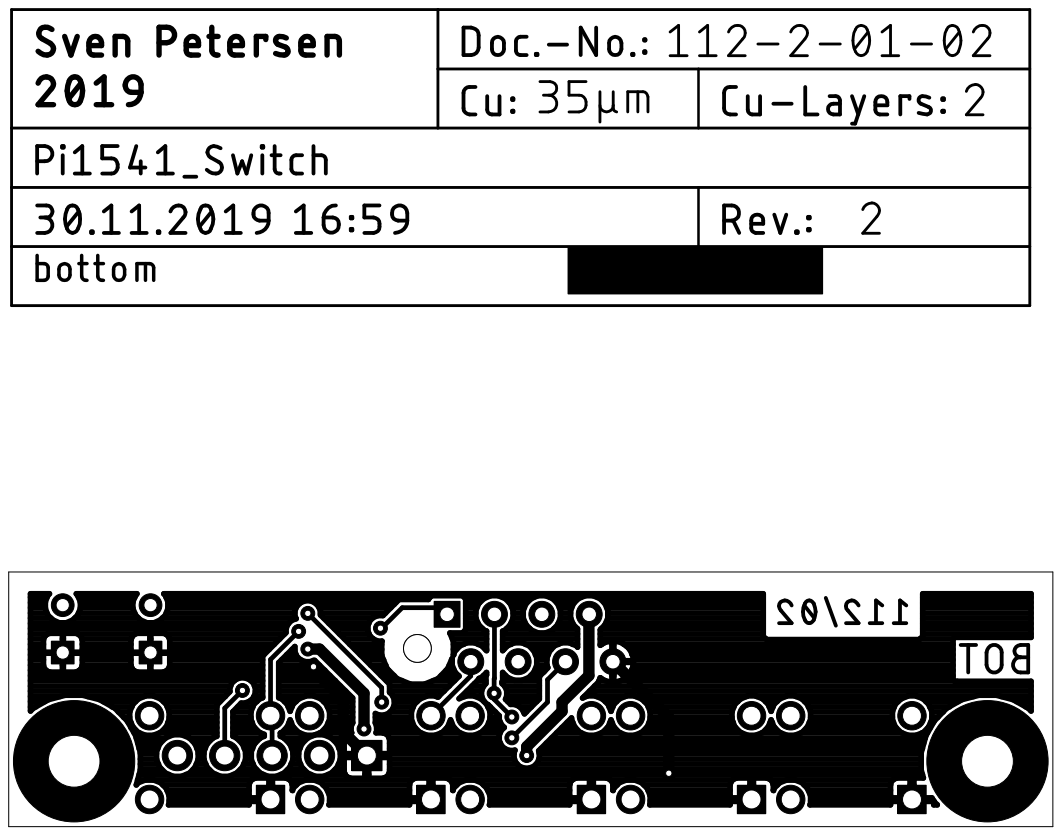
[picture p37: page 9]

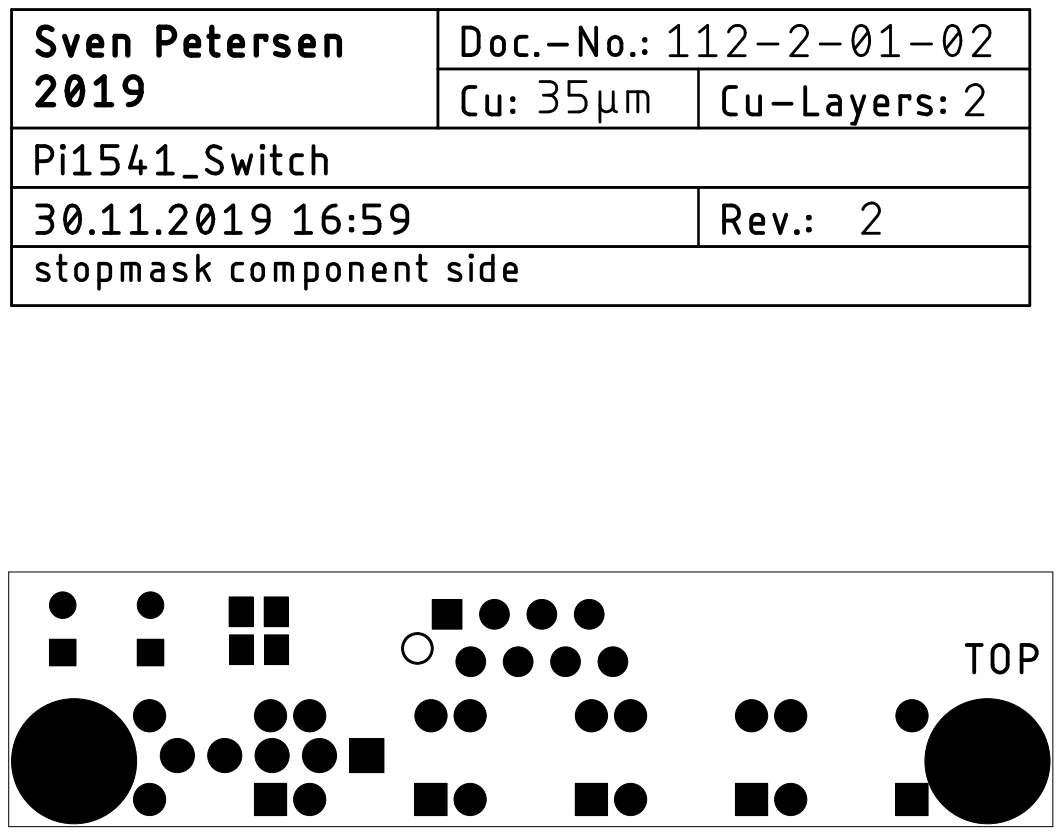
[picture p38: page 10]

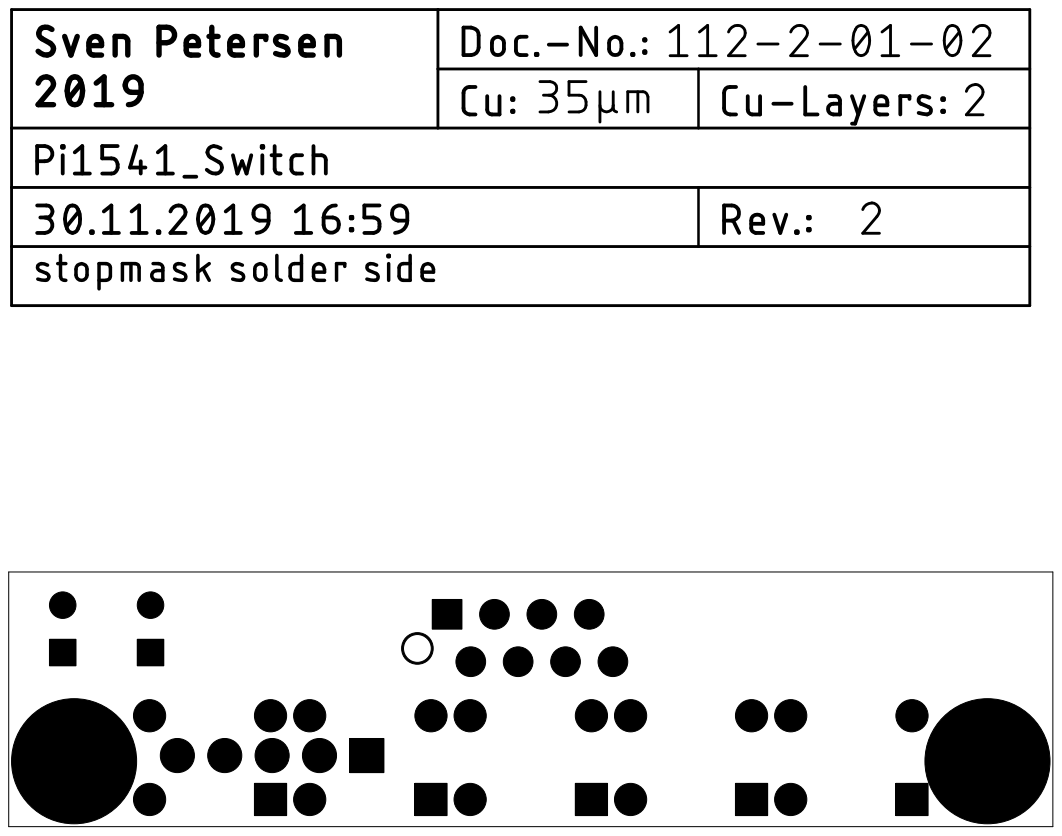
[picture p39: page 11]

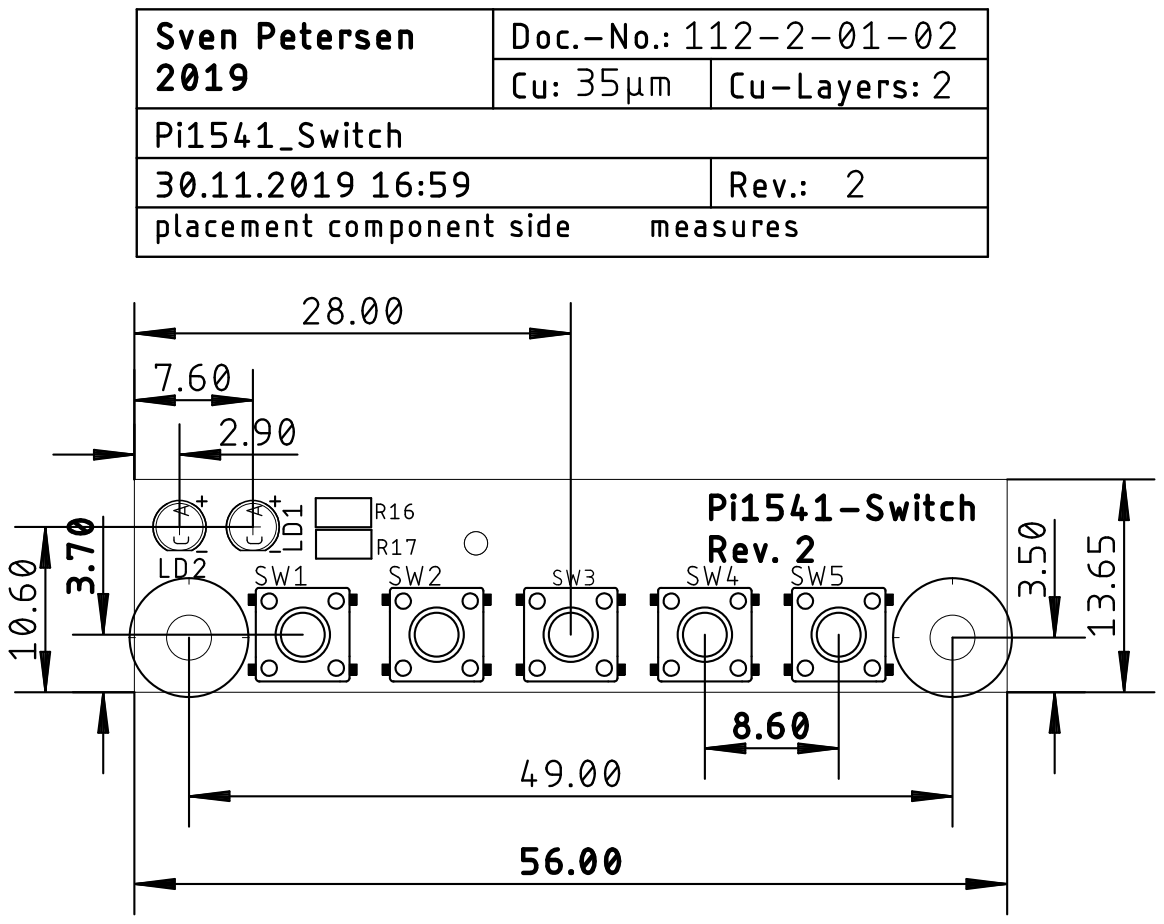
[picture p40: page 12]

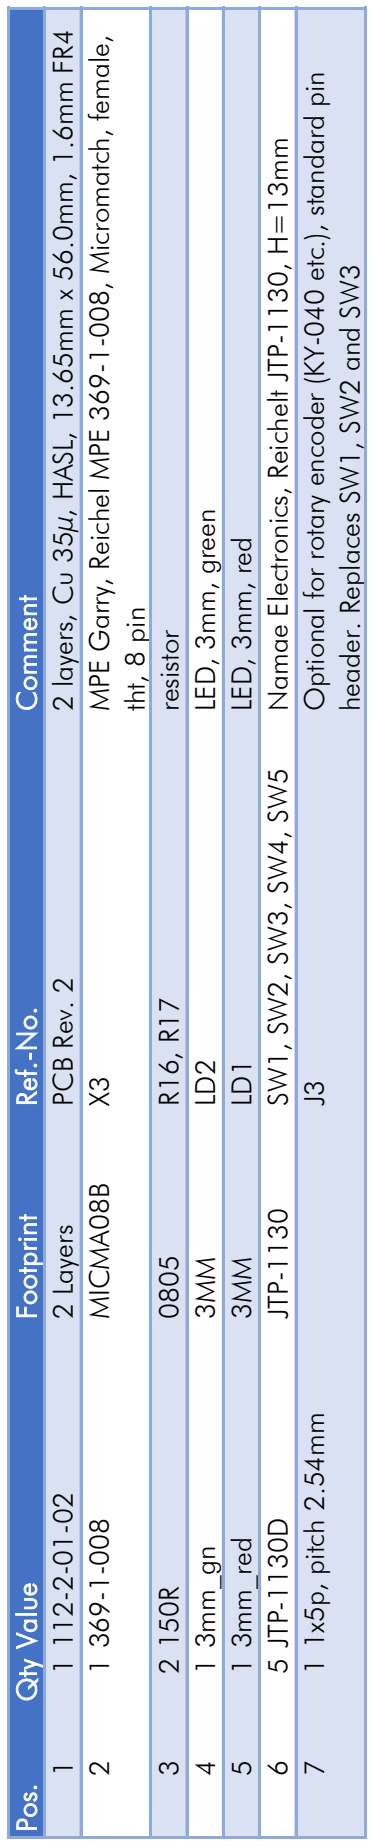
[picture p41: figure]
tht, 8 pin; 3 2 150R 0805 R16, R17 resistor; 4 1 3mm_gn 3MM LD2 LED, 3mm, green; 5 1 3mm_red 3MM LD1 LED, 3mm, red; header. Replaces SW1, SW2 and SW3

Pos. Qty Value Footprint Ref.-No. Comment

1 1 112-2-01-02 2 Layers PCB Rev. 2 2 layers, Cu 35µ, HASL, 13.65mm x 56.0mm, 1.6mm FR4
2 1 369-1-008 MICMA08B X3 MPE Garry, Reichel MPE 369-1-008, Micromatch, female,

6 5 JTP-1130D JTP-1130 SW1, SW2, SW3, SW4, SW5 Namae Electronics, Reichelt JTP-1130, H=13mm

7 1 1x5p, pitch 2.54mm J3 Optional for rotary encoder (KY-040 etc.), standard pin

### Pos. Rev. 1 → Rev. 2

### 1 PCB revision

### 7 new

## Pi1541-Switch Rev. 2

## Bill of Material Rev. 2.0

Pi1541-Switch_BOM_v2_0.xlsx

Drafted by Sven Petersen Page 1 of 1

30.11.2019 16:49
Doc.No.: 112-5-01-02.0

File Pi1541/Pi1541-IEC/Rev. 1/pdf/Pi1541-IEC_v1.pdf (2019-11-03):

# Project Documentation

## Pi1541-IEC

## Project number: 115

## Revision: 1

## Date: 03.11.2019

Pi1541-IEC_ModB_v1.docx | | 03.11.2019 08:36
Drafted by Sven Petersen | Page 1 of 2 | Doc.-No.: 115-6-01-01

## Pi1541-IEC Rev. 1

## Module Description

## Description

The Pi1541-IEC serves the Pi1541-HAT (project number 111) as an optional break out board for the IEC connectors. It also contains a barrel connector (5,5/2,5mm) for an alternative power supply connection plus an overvoltage protection. A reset switch for the IEC-bus can be placed. A ribbon cable plus a MicroMatch connector provide the connection to the Pi1541-HAT. A power switch can be connected to a pin header (JP1) near the barrel connector. If this is not desired, it can be closed with a solder bridge.

## Pinouts

### IEC-Bus

J1 and J2 – Lumberg 010599 06, 6p DIN receptacles

Pin Signal
1 /SRQ (not used in this design) 2 GND
3 ATN
4 CLK
5 DATA
6 /RESET

### IEC Bus (to Pi1541 HAT)

X1 – 10p Micro Match receptacle, female, vertical, through hole, e.g. MPE Garry 369-1-010

Pin Signal
1 /SRQ (not used in this design) 2 GND
3 ATN
4 CLK
5 DATA
6 /RESET
7 +5V
8 +5V
9 GND
10 GND

### +5VDC Power

5,5mm/2,5mm barrel connector

Pin | Signal
Center | +5VDC
Shaft | GND

## Prototype Testing

The prototype was tested together with Pi1541-HAT Rev. 1. Please refer to the respective document.

Pi1541-IEC_ModB_v1.docx | | 03.11.2019 08:36
Drafted by Sven Petersen | Page 2 of 2 | Doc.-No.: 115-6-01-01

## Revision History

### Rev. 0 → Rev. 1

- Jumper JP1 added for connecting a power switch

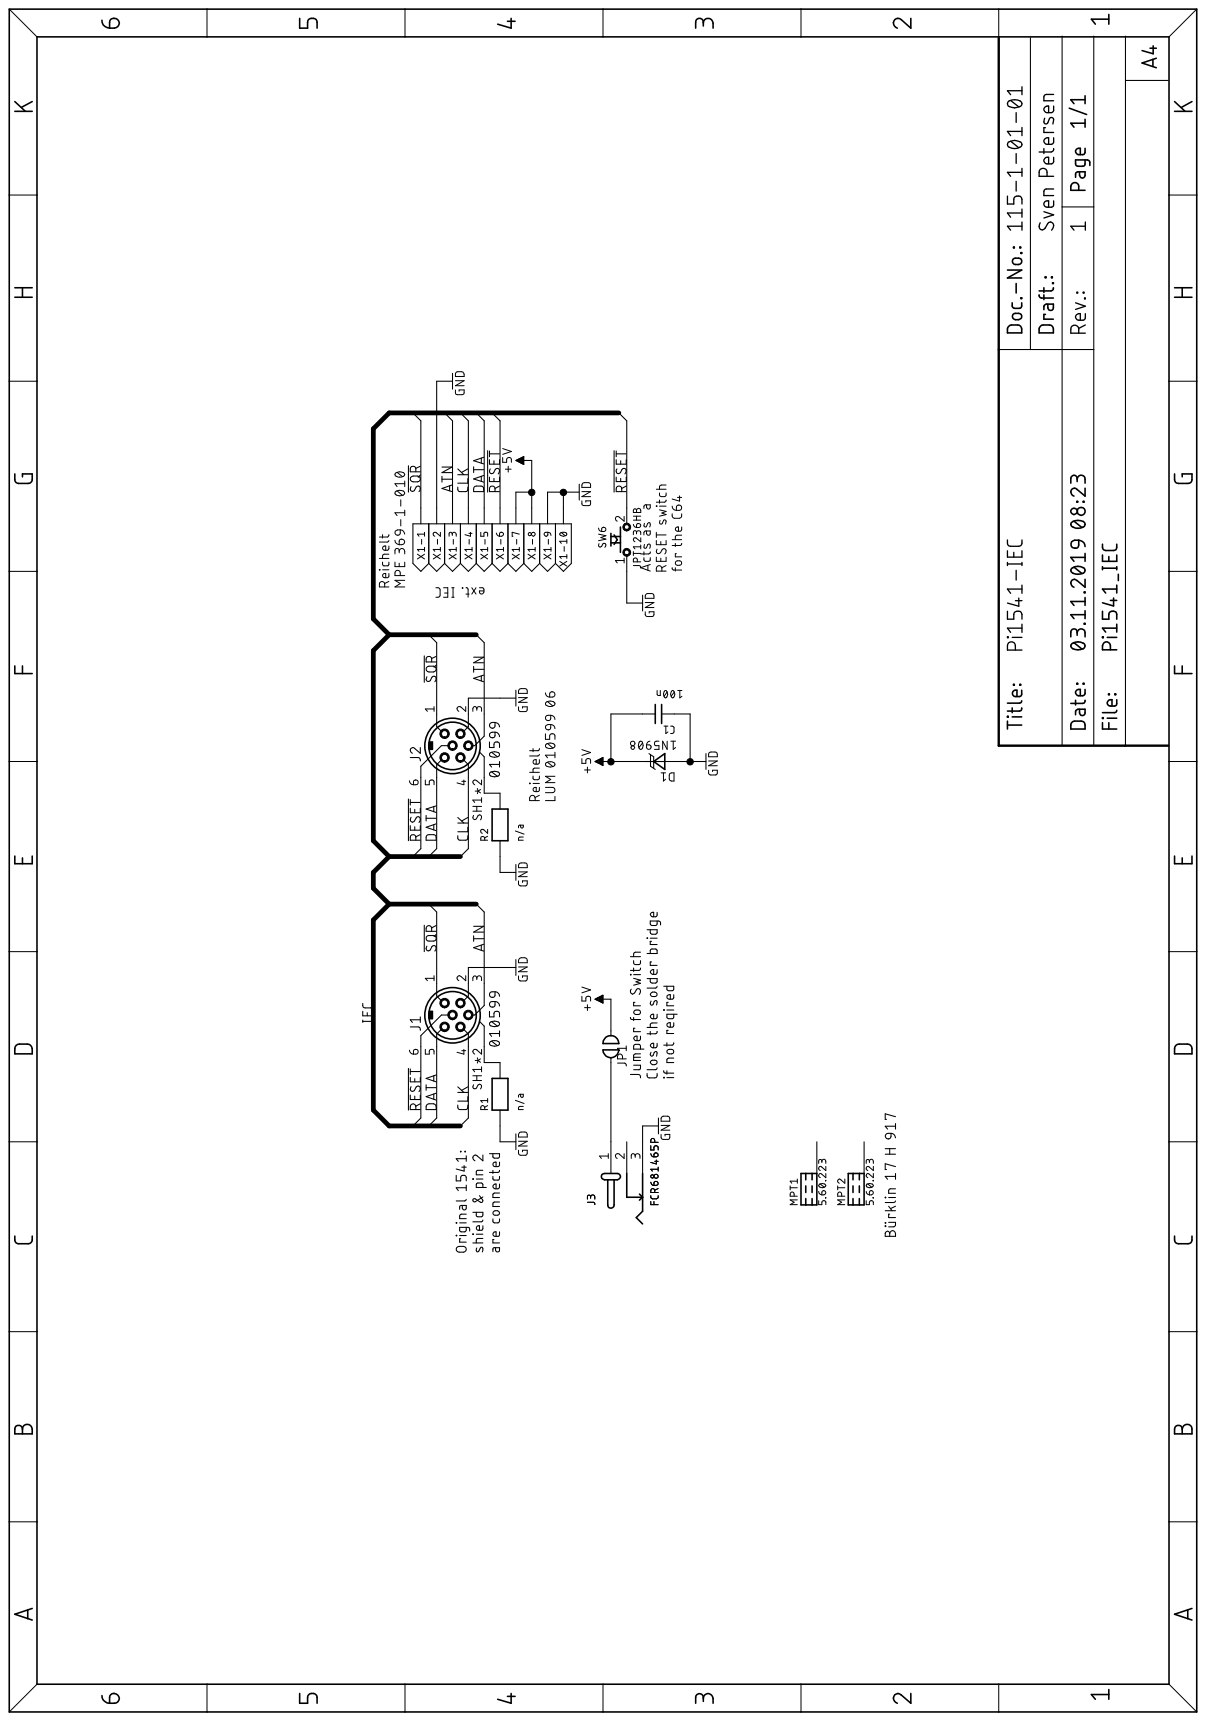
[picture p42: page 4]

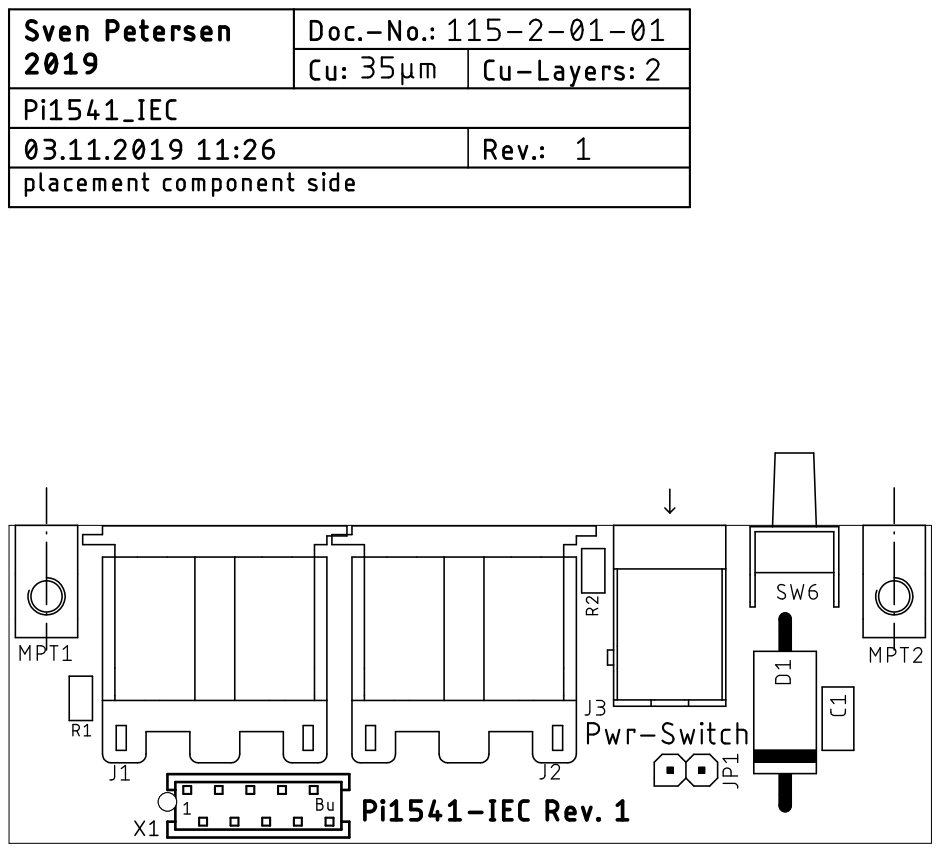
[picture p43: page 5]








Pos. Qty Value Footprint Ref.-No. Comment

1 1 115-2-01-01 2 Layer PCB Rev. 1 2 layer, Cu 35µ, HASL, 71.0mm x 25.5mm, 1.6mm FR4
2 2 10599 10599 J1, J2 Lumberg, e.g. Reichelt 010599 06, tme.eu: 0105-06

3 1 100n C-2,5 C1 ceramic capacitor, pitch: 2.5mm

4 1 1N5908 CB429 D1 TVS Diode (5V)

5 1 369-1-010 MICMA10B X1 MicroMatch MPE, e.g. Reichelt MPE 369-1-010, tme.eu 1-

215079-0/C

6 1 372-1-010 (X1) MicroMatch MPE, e.g. Reichelt MPE 372-1-010, tme.eu: 1-

215083-0/C

6 2 5.60.223 5.60.223 MPT1, MPT2 Ettinger, e.g. Bürklin 17 H 917 (optional for mounting)

7 1 FCR681465P FCR681465P J3 Cliff, Reichelt: CLIFF FCR681465P, tme.eu: FCR681465P
8 1 JPT1236HB JTP_1236HB SW6 Namae Electronics, e.g. Reichelt TASTER 3305B, tme.eu:

TACTA-68N-F

9 2 n/a 0805 R1, R2 not assembled

## Pi1541-IEC Rev. 1

## Bill of Material Rev. 1.0

Pi1541-IEC_BOM_v1_0.xlsx

Drafted by Sven Petersen Page 1 of 1

03.11.2019 11:22
Doc.No.: 115-5-01-01.0

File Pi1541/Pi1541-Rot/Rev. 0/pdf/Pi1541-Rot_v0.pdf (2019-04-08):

Project Documentation
Pi1541 – Rotary Encoder Board
Project number: 118
Revision: 0
Date: 17.03.2019

The default configuration is: Switch Function SW4 Exit Folder SW5 Insert Disk

Pi1541-Rot_ModB_v0.docx 08.04.2019 16:57 Drafted by Sven Petersen Page 1 of 2 Doc.-No.: 118-6-01-00

Pi1541 – Rotary Encoder Board Rev. 0
Module Description
The Rotary Encoder Board is intended to work with the Pi1541-HAT (Project 111) instead of the Pi1541-Switch Board (Project 112). Instead of the switches SW1 (Enter/Escape), SW2 (down) and SW3 (up) on the board mentioned above, a rotary encoder is used, which issues pulses (active low) to SW2 and SW3 depending on the direction in which it is turned. Pushing the axis of the rotary
encoder will switch the SW1 signal.
The duration of the up or down pulses is determined by R/C combination and can be adapted to the requirements of the software. This way, no adaptation is requited of the Pi1541 software
running on the Raspberry Pi to operate the rotary encoder.
The distances of the mounting holes, the LEDs and the switches remain the same like on the Pi1541-Switch board. The rotary encoder axis does not fit into the 8.6mm grid of the switches on
the Pi1541-Switch board.

Figure 1: Measures of the Pi1541-Rot Board

Switches Rotary encoder
The switches have functions according to the firmware and configuration, which can be found at
this website: https://cbm-pi1541.firebaseapp.com/


Pi1541-Rot_ModB_v0.docx 08.04.2019 16:57 Drafted by Sven Petersen Page 2 of 2 Doc.-No.: 118-6-01-00

Rotary Enc. Function
Push Select/Reset
CCW Move Up/Previous Disk
CW Move Down/Next Disk

LEDs
LED Color Function
LD2 Green Power Indicator
LD1 Red Busy Indicator

Connector
X3: 8p Micro Match, female, THT (Tyco or alternative) The ribbon cable can also be soldered in directly.
Pin Signal
1 /SW1 (push)
2 /SW2 (CCW)
3 /SW3 (CW)
4 /SW4
5 /SW5

### 6 LED_OUT (LD1)

7 +3V3

### 8 GND

Placement of IC3
IC3 is a dual Schmitt trigger. The case is symmetric (SOT-23-6) and the pin 1 mark is not very
visible.

Figure 2: Placement of IC3

If the part marking is upright, pin 1 is at the left lower corner of the part as shown in Figure 2.











Pi1541-Rot_FunB_v0.docx 08.04.2019 16:58 Drafted by Sven Petersen Page 1 of 1 Doc.-No.: 118-6-02-00

Pi1541 – Rotary Encoder Board Rev. 0
Functional Description
The rotary encoder RT1 issues two square wave signals on channel A and channel B, depending on the direction of the turn, channel A is ahead of channel B or vice versa. Since the rotary encoder is working mechanically, the two channels are required to be “debounced”. R6/R8/C6 or R5/R7/C7 are serving this purpose, as recommended by the
manufacturer of the rotary encoder.
There are two identical circuits for the direction recognition, which consist of a D-flip flop and a mono-flop each. For both directions, channel A and Channel B play an opposite role.
Figure 1: Channel A ahead of channel B

The case shown in Figure 1 describes a turn fitting the detected direction. Here, channel B is driving the clock signal of the D-flipflop (IC1), while channel A is connected to the D-input and the /CLR-signal of that D-FF. A rising edge of channel B will latch the level of channel A (in this case a HIGH) to the output Q. Later in the signal cycle, channel A will get LOW, which resets the D-FF via the /CLR input. The positive pulse generated on the output Q triggers the following mono-flop (IC2). This way, a LOW pulse of a duration tMF will be issued on the /Q output of IC2. tMF is determined by the R/C combination (R3 and C3 or R4 and C4) connected to the mono-flop.
Figure 2: Channel B ahead of channel A

Turning the rotary encoder opposite to the detected direction will result in output signals shown in Figure 2. A LOW level of channel A will reset the D-FF. The output Q of IC1 will be reset. When the rising edge of Channel B latches the level of channel A, which is LOW at that time. The output Q of the D-FF will remain low. No pulses are generated by the mono-flop (IC2).
Pushing the rotary encoder will work as the Select/Reset switch. Pushing SW4 will exit the folder, SW5 will select the disk images for a multi disk game/demo.
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

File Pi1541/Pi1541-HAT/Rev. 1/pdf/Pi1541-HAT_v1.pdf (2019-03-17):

Project Documentation

Pi1541 HAT
Project number: 111
Revision: 1
Date: 26.02.2019

Pi1541-HAT_ModB_v1.docx 27.02.2019 19:24 Drafted by Sven Petersen Page 1 of 4 Doc.-No.: 111-6-01-01

Pi1541-HAT Rev. 1
Module description

Description
The Pi1541 HAT is the required electrical and user interface for the Raspberry Pi (Model 3, 3+ or better) to emulate the Commodore 1541 floppy disk drive in conjunction with Steve White’s software project (https://cbm-pi1541.firebaseapp.com/). This software is a cycle exact, real-time emulation of the 1541. The disk images are stored on the SD-card of the Raspberry Pi and the switches and the display (of the HAT) allow the user to navigate through his disk archive. Since Pi1541 emulates the exact hardware of the 1541, it is compatible to every speed loader, that work with the original disk drive.
This Pi1541 HAT is one of many possible variants. It holds the original I/O-driver configuration of the 1541, which is then adapted to the Raspberry Pi. The user interface consists of an OLED-display, six switches and a piezo buzzer, which resembles the sound of
the working stepper motor.
Further on, it is designed to offer a good flexibility. The display can be either connected to a 4 pole receptable on the board or it can be detached and connected (https://cbm-pi1541.firebaseapp.com/) with a small piece of ribbon cable. The switches can also be soldered on the PCB or on a little extra PCB (Pi1541-Switch), which also holds two LEDs and is designed for a front panel mount. The two IEC-connectors can be mounted on this PCB or a separate PCB (Pi1541-IEC), which also holds a RESET switch and a barrel connector for a 5V power supply.

Pin outs

IEC-Bus
J1 and J2 – Lumberg 010599 06, 6p DIN receptables
Pin Signal
1 /SRQ (not used in this design)

### 2 GND

### 3 ATN

### 4 CLK

### 5 DATA

6 /RESET

IEC Bus (break out board)
X1 – 10p Micro Match receptible, female, vertical, through hole, e.g. MPE Garry 369-1-010 X1 can be assembled instead of J1 and J2

Pi1541-HAT_ModB_v1.docx 27.02.2019 19:24 Drafted by Sven Petersen Page 2 of 4 Doc.-No.: 111-6-01-01

Pin Signal
1 /SRQ (not used in this design)

### 2 GND

### 3 ATN

### 4 CLK

### 5 DATA

6 /RESET
7 +5V
8 +5V

### 9 GND 10 GND

Display

M2 - A 0.96” OLED display (I²C) can be connected to the 4p receptable M2 (0.1” pin distance).
This connector provides +3.3V supply voltage. It is important to check the pinning of the display. Some might have swapped +3.3V and GND, so inserting those displays will destroy them.
From left to right:
Pin Signal

### 1 VCC

### 2 GND

### 3 SCL

### 4 SDA

External Display
In case the display is desired to be mounted externally or it is bigger than the footprint (e.g. 1.3”) or it has a different pin sequence such as GND, VCC etc. it can be attached to this connector. X2 – 4p Micro Match receptible, female, vertical, through hole, e.g. MPE Garry 369-1-004
Pin Signal

### 1 VCC

### 2 GND

### 3 SCL

### 4 SDA

External Switches
X3 – 8p Micro Match receptible, female, vertical, through hole, e.g. MPE Garry 369-1-008
Pin Signal
1 /SW1
2 /SW2
3 /SW3
4 /SW4
5 /SW5

### 6 LED_OUT (LD1)

7 +3V3

### 8 GND

Pi1541-HAT_ModB_v1.docx 27.02.2019 19:24 Drafted by Sven Petersen Page 3 of 4 Doc.-No.: 111-6-01-01

Raspberry Pi Connector
A 2x20 Pin receptible, assembled on the solder side of the PCB.
Pin GPIO Signal Comment
1 - +3.3V Supply voltage
2 - +5V Supply voltage

### 3 SDA SDA (I²C) I²C-Bus (display)

4 - +5V Supply voltage

### 5 SCL SCL (I²C) I²C-Bus (display)

6 - GND Ground
7 4 /SW4_IN Switch 4, active low
9 - GND Ground
11 17 /CLK_OUT /CLK_(output to IEC-Bus driver) 12 18 /DATA_OUT /DATA (output to IEC-Bus driver) 13 27 /SW1_IN Switch 1, active low
14 - GND Ground
15 22 /SW2_IN Switch 2, active low
16 23 /SW3_IN Switch 3, active low
17 - +3.3V Supply voltage
18 24 ATN_IN ATN (IEC-Bus), 3.3V-level 20 - GND Ground
22 25 DATA_IN DATA (IEC-Bus), 3.3V-level 25 - GND Ground
27 ID_SD ID_SD Secondary I²C: SDA
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

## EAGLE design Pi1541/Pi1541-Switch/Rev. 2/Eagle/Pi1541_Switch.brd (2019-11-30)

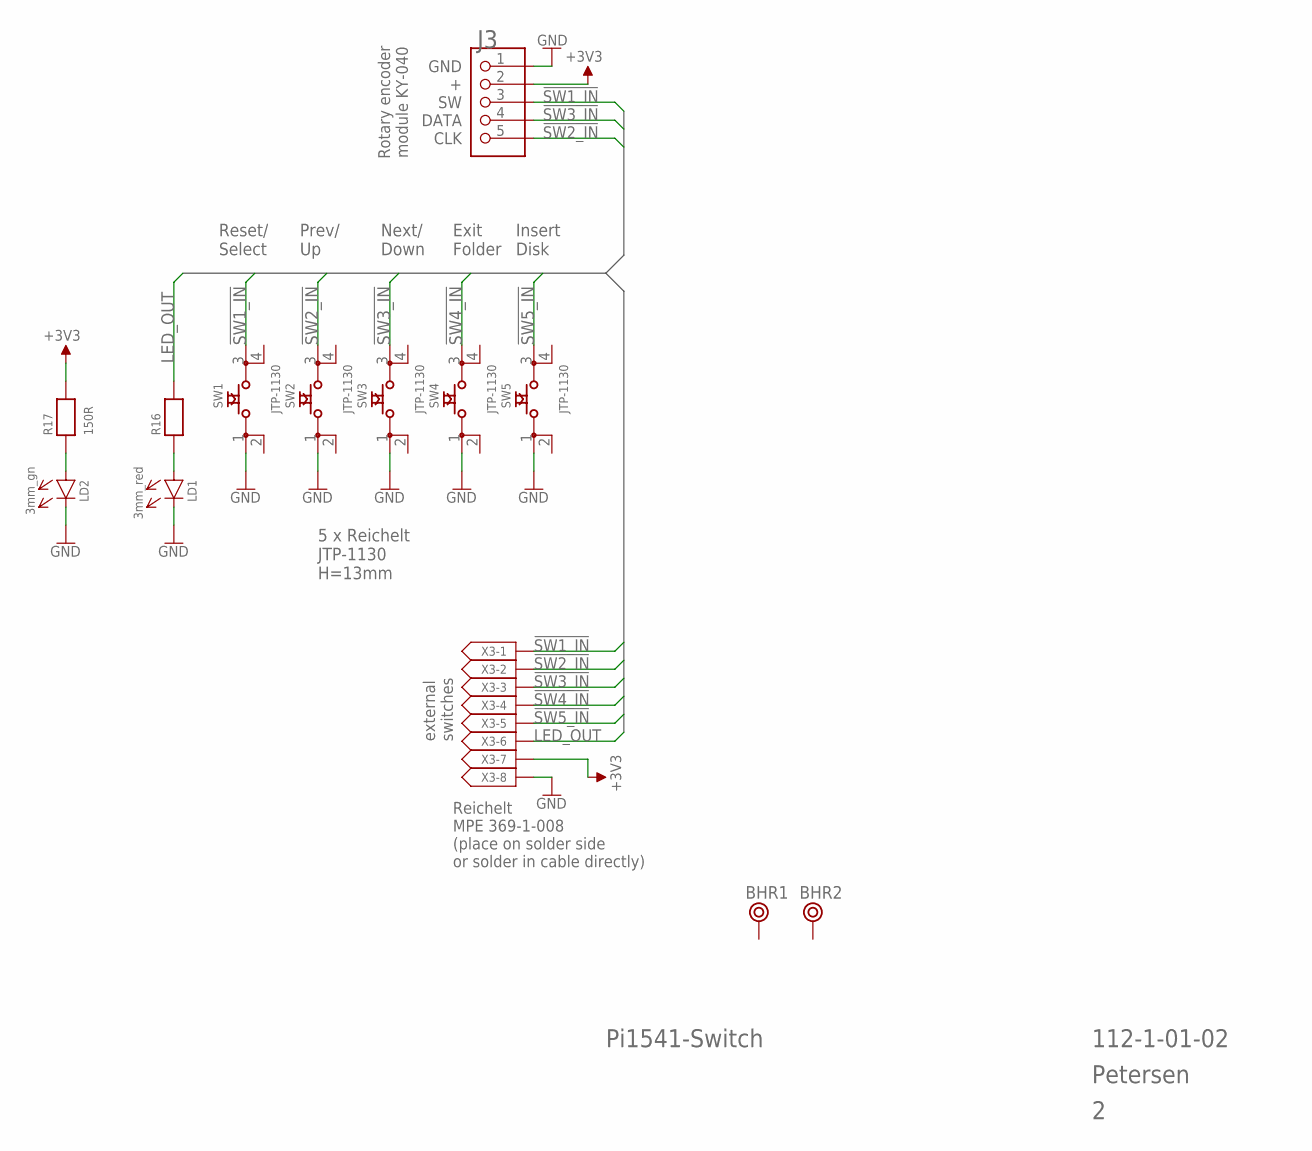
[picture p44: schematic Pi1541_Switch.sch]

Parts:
BHR1, BHR2: BOHR2,8; BOHR2,8_
J3: PINHD-1X5; 1X05
LD1: 3mm_red; 3MM
LD2: 3mm_gn; 3MM
R16, R17: 150R; 0805
SW1, SW2, SW3, SW4, SW5: JTP-1130
X3: MICMA08B

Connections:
!SW1_IN: J3.3, SW1.3, X3.1
!SW2_IN: J3.5, SW2.3, X3.2
!SW3_IN: J3.4, SW3.3, X3.3
!SW4_IN: SW4.3, X3.4
!SW5_IN: SW5.3, X3.5
+3V3: J3.2, R17.2, X3.7
GND: J3.1, LD1.C (K), LD2.C (K), SW1.1, SW2.1, SW3.1, SW4.1, SW5.1, X3.8
LED_OUT: R16.2, X3.6
unnamed: LD2.A, R17.1
unnamed: LD1.A, R16.1

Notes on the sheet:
5 x Reichelt JTP-1130 H=13mm
Reset/ Select
Prev/ Up
Next/ Down
Exit Folder
Insert Disk
external switches
Reichelt MPE 369-1-008 (place on solder side or solder in cable directly)
Pi1541-Switch
Petersen
112-1-01-02
GND
DATA
CLK
Rotary encoder module KY-040

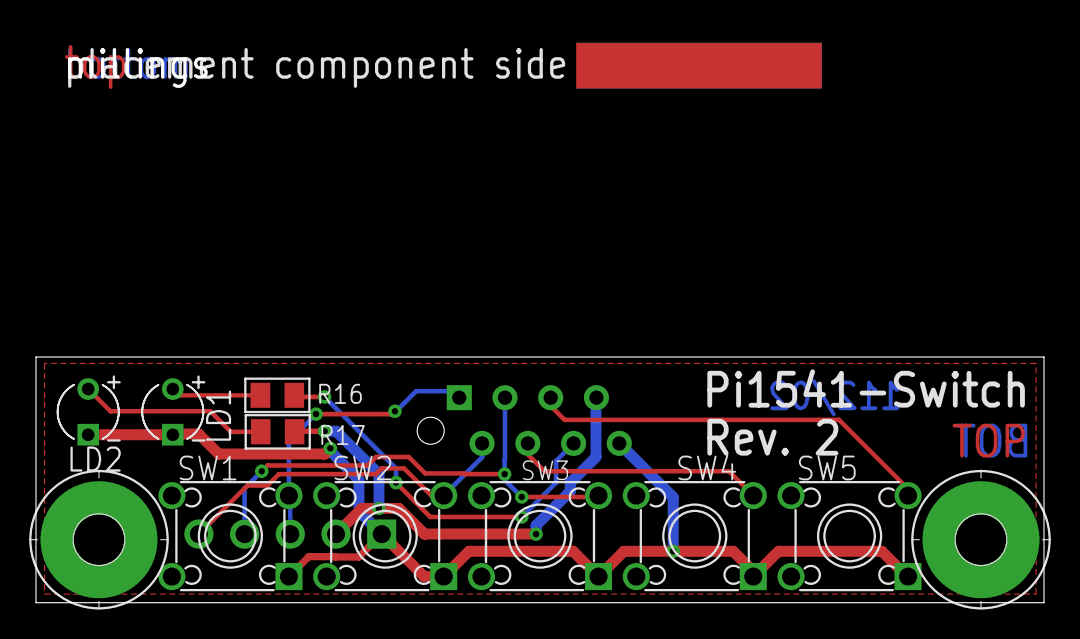
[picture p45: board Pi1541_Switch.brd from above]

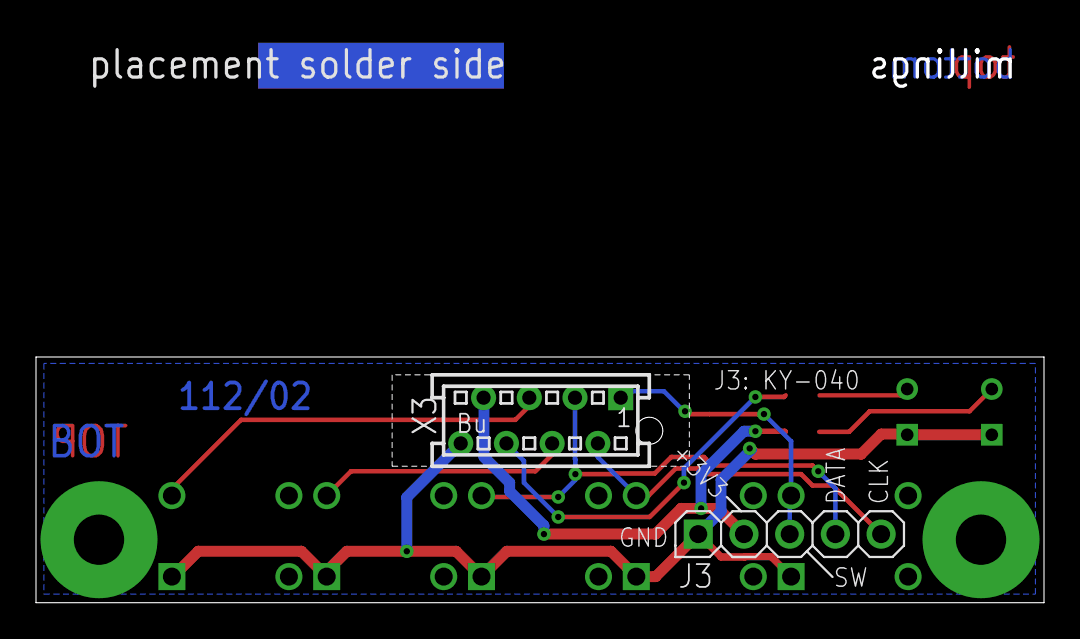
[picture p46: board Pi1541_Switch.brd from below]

Board: 2 copper layers, 56.0 x 13.7 mm, 15 parts (2 on the bottom side), 10 nets.

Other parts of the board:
U$44: 2LAYER
U$45: PCB-TITLE/

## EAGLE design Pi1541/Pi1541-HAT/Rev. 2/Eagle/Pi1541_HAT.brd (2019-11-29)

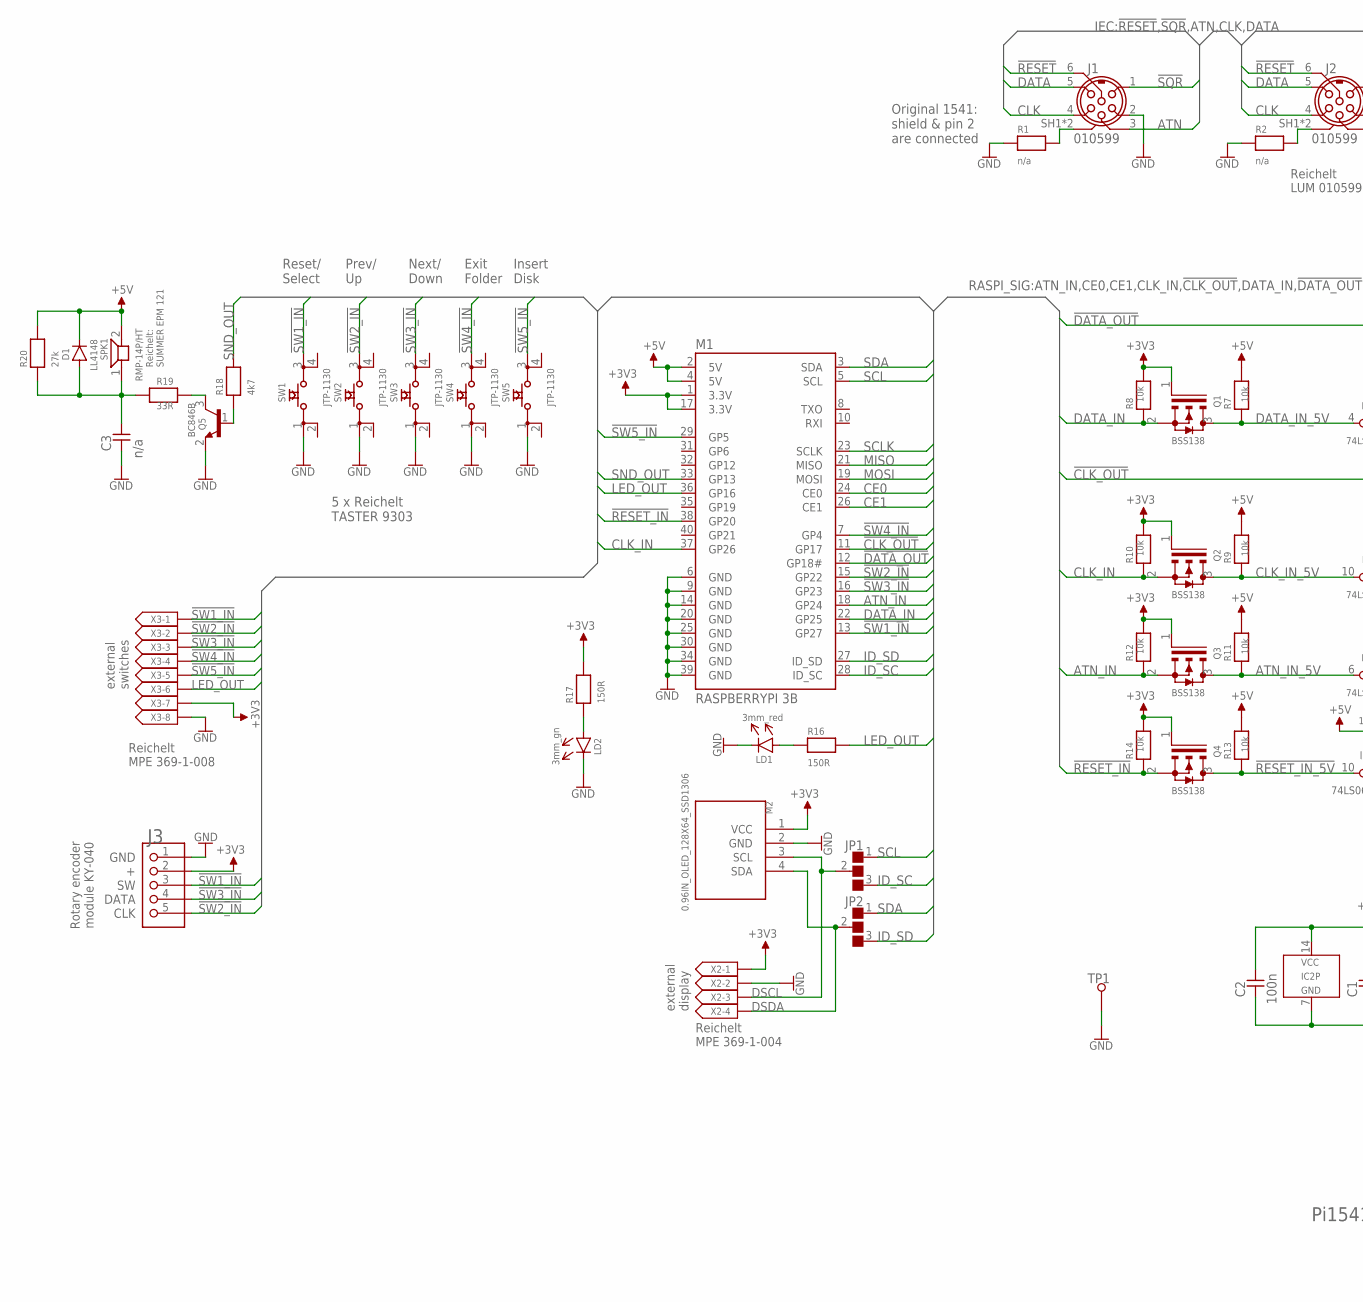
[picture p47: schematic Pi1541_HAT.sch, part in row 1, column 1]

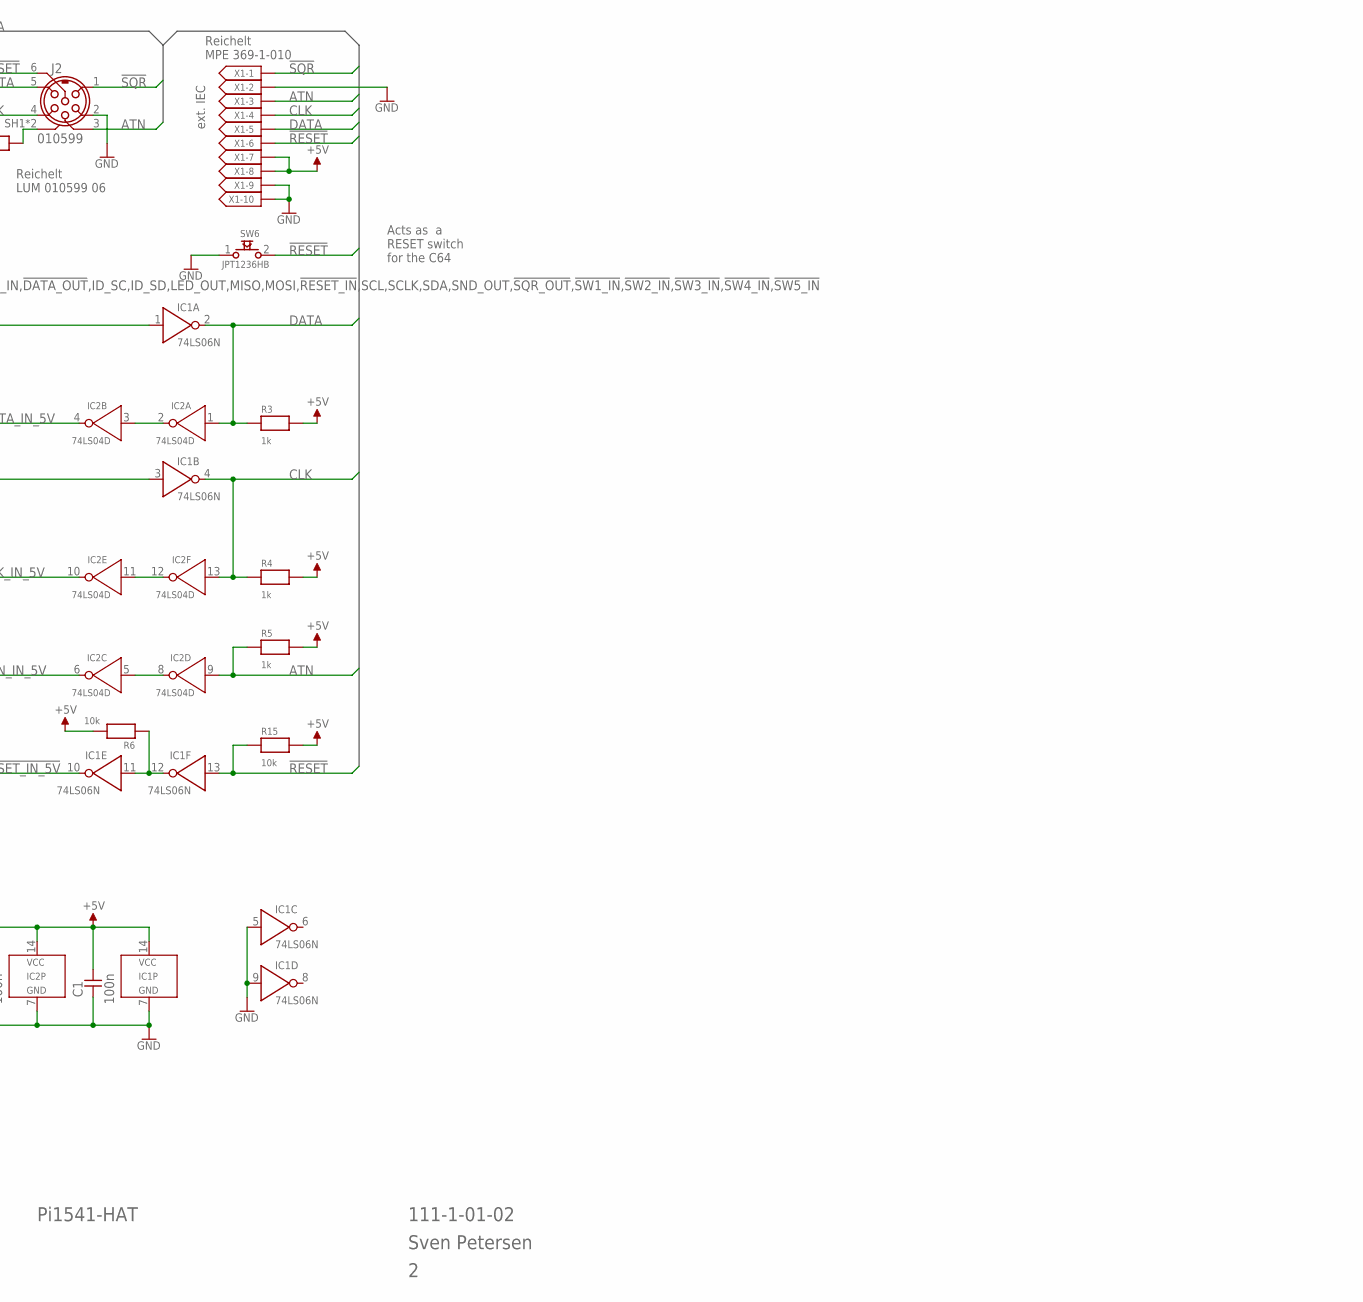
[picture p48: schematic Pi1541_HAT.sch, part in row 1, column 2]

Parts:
C1, C2: 100n; 0805
C3: n/a; 0805
D1: LL4148; SOD80C
IC1: 74LS06N; DIL-14
IC2: 74LS04D; SO-14
J1, J2: 010599
J3: PINHD-1X5; 1X05
JP1, JP2: JMP_0603; CP3P
LD1: 3mm_red; 3MM
LD2: 3mm_gn; 3MM
M1: RASPBERRYPI 3B; PI_HAT_40P
M2: 0.96IN_OLED_128X64_SSD1306; OLED_0.96_SSD1306
Q1, Q2, Q3, Q4: BSS138; SOT23
Q5: BC846B; SOT23
R1, R2: n/a; 0805
R3, R4, R5: 1k; 0805
R6, R7, R8, R9, R10, R11, R12, R13, R14, R15: 10k; 0805
R16, R17: 150R; 0805
R18: 4k7; 0805
R19: 33R; 0805
R20: 27k; 0805
SPK1: RMP-14P/HT
SW1, SW2, SW3, SW4, SW5: JTP-1130
SW6: JPT1236HB; JTP_1236HB
TP1: L1,2_R; 1,2MM_R
X1: 369-1-010; MICMA10B
X2: 369-1-004; MICMA04B
X3: 369-1-008; MICMA08B

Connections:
!CLK_OUT: IC1.3 (I), M1.11 (GP17)
!DATA_OUT: IC1.1 (I), M1.12 (GP18#)
!RESET: IC1.13 (I), J1.6, J2.6, R15.1, SW6.2, X1.6
!RESET_IN: M1.38 (GP20), Q4.2 (S), R14.1
!RESET_IN_5V: IC1.10 (O), Q4.3 (D), R13.1
!SQR: J1.1, J2.1, X1.1
!SW1_IN: J3.3, M1.13 (GP27), SW1.3, X3.1
!SW2_IN: J3.5, M1.15 (GP22), SW2.3, X3.2
!SW3_IN: J3.4, M1.16 (GP23), SW3.3, X3.3
!SW4_IN: M1.7 (GP4), SW4.3, X3.4
!SW5_IN: M1.29 (GP5), SW5.3, X3.5
+3V3: J3.2, M1.1 (3.3V), M1.17 (3.3V), M2.1 (VCC), Q1.1 (G), Q2.1 (G), Q3.1 (G), Q4.1 (G), R8.2, R10.2, R12.2, R14.2, R17.2, X2.1, X3.7
+5V: C1.2, C2.2, D1.K, IC1.14 (VCC), IC2.14 (VCC), M1.2 (5V), M1.4 (5V), R3.2, R4.2, R5.2, R6.2, R7.2, R9.2, R11.2, R13.2, R15.2, R20.2, SPK1.2, X1.7, X1.8
ATN: IC2.9 (I), J1.3, J2.3, R5.1, X1.3
ATN_IN: M1.18 (GP24), Q3.2 (S), R12.1
ATN_IN_5V: IC2.6 (O), Q3.3 (D), R11.1
CE0: M1.24 (CE0)
CE1: M1.26 (CE1)
CLK: IC1.4 (O), IC2.13 (I), J1.4, J2.4, R4.1, X1.4
CLK_IN: M1.37 (GP26), Q2.2 (S), R10.1
CLK_IN_5V: IC2.10 (O), Q2.3 (D), R9.1
DATA: IC1.2 (O), IC2.1 (I), J1.5, J2.5, R3.1, X1.5
DATA_IN: M1.22 (GP25), Q1.2 (S), R8.1
DATA_IN_5V: IC2.4 (O), Q1.3 (D), R7.1
DSCL: JP1.2, M2.3 (SCL), X2.3
DSDA: JP2.2, M2.4 (SDA), X2.4
GND: C1.1, C2.1, C3.1, IC1.5 (I), IC1.7 (GND), IC1.9 (I), IC2.7 (GND), J1.2, J2.2, J3.1, LD1.K, LD2.K, M1.6 (GND), M1.9 (GND), M1.14 (GND), M1.20 (GND), M1.25 (GND), M1.30 (GND), M1.34 (GND), M1.39 (GND), M2.2 (GND), Q5.2 (E), R1.1, R2.1, SW1.1, SW2.1, SW3.1, SW4.1, SW5.1, SW6.1, TP1.1, X1.2, X1.9, X1.10, X2.2, X3.8
ID_SC: JP1.3, M1.28 (ID_SC)
ID_SD: JP2.3, M1.27 (ID_SD)
LED_OUT: M1.36 (GP16), R16.2, X3.6
MISO: M1.21 (MISO)
MOSI: M1.19 (MOSI)
unnamed: J1.SH1 (SH), J1.SH2 (SH), R1.2
unnamed: J2.SH1 (SH), J2.SH2 (SH), R2.2
unnamed: IC2.2 (O), IC2.3 (I)
unnamed: IC2.11 (I), IC2.12 (O)
unnamed: IC2.5 (I), IC2.8 (O)
unnamed: IC1.11 (I), IC1.12 (O), R6.1
unnamed: LD2.A, R17.1
unnamed: Q5.1 (B), R18.1
unnamed: Q5.3 (C), R19.2
unnamed: C3.2, D1.A, R19.1, R20.1, SPK1.1
unnamed: LD1.A, R16.1
SCL: JP1.1, M1.5 (SCL)
SCLK: M1.23 (SCLK)
SDA: JP2.1, M1.3 (SDA)
SND_OUT: M1.33 (GP13), R18.2

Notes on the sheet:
Original 1541: shield & pin 2 are connected
5 x Reichelt TASTER 9303
Reset/ Select
Prev/ Up
Next/ Down
Exit Folder
Insert Disk
Reichelt: SUMMER EPM 121
external display
external switches
Acts as a RESET switch for the C64
Reichelt MPE 369-1-004
Reichelt MPE 369-1-008
Reichelt MPE 369-1-010
ext. IEC
Reichelt LUM 010599 06
Pi1541-HAT
Sven Petersen
111-1-01-02
GND
DATA
CLK
Rotary encoder module KY-040

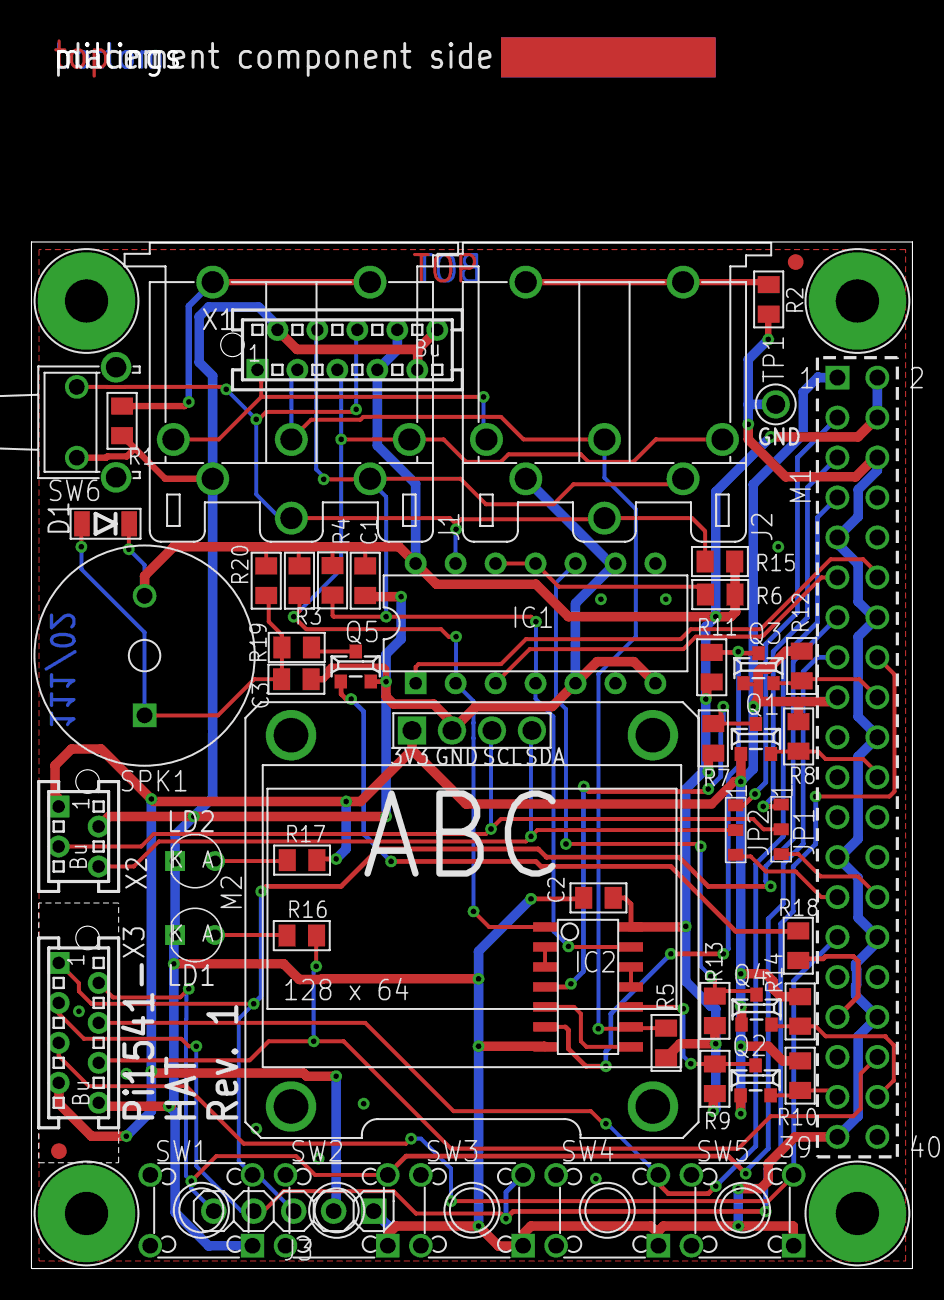
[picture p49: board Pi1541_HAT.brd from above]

Board: 2 copper layers, 56.0 x 65.2 mm, 55 parts (0 on the bottom side), 42 nets.

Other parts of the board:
U$44: 2LAYER
U$45: PCB-TITLE/
U$47, U$48: SMD_REF_R1MM

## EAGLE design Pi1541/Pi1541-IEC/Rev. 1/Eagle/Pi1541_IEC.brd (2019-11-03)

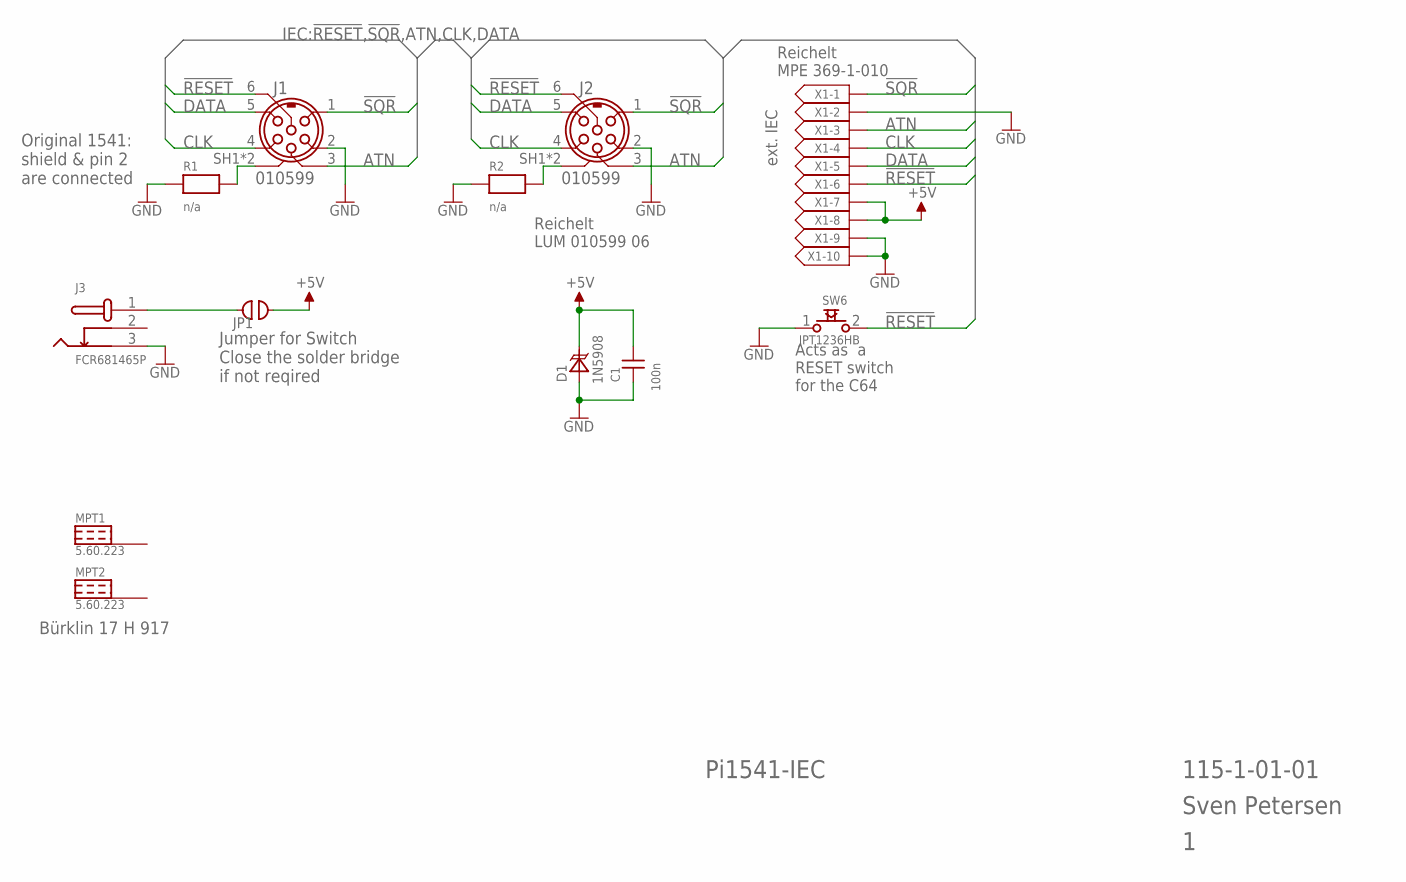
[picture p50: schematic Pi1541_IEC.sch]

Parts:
C1: 100n; C-2,5
D1: 1N5908; CB429
J1, J2: 010599
J3: FCR681465P
JP1: COMBI_2P; COMBI-2P
MPT1, MPT2: 5.60.223
R1, R2: n/a; 0805
SW6: JPT1236HB; JTP_1236HB
X1: 369-1-010; MICMA10B

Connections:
!RESET: J1.6, J2.6, SW6.2, X1.6
!SQR: J1.1, J2.1, X1.1
+5V: C1.2, D1.K, JP1.2, X1.7, X1.8
ATN: J1.3, J2.3, X1.3
CLK: J1.4, J2.4, X1.4
DATA: J1.5, J2.5, X1.5
GND: C1.1, D1.A, J1.2, J2.2, J3.3, R1.1, R2.1, SW6.1, X1.2, X1.9, X1.10
unnamed: J1.SH1 (SH), J1.SH2 (SH), R1.2
unnamed: J2.SH1 (SH), J2.SH2 (SH), R2.2
unnamed: J3.1, JP1.1

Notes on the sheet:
Original 1541: shield & pin 2 are connected
Acts as a RESET switch for the C64
Reichelt MPE 369-1-010
ext. IEC
Reichelt LUM 010599 06
Pi1541-IEC
Sven Petersen
115-1-01-01
Bürklin 17 H 917
Jumper for Switch Close the solder bridge if not reqired

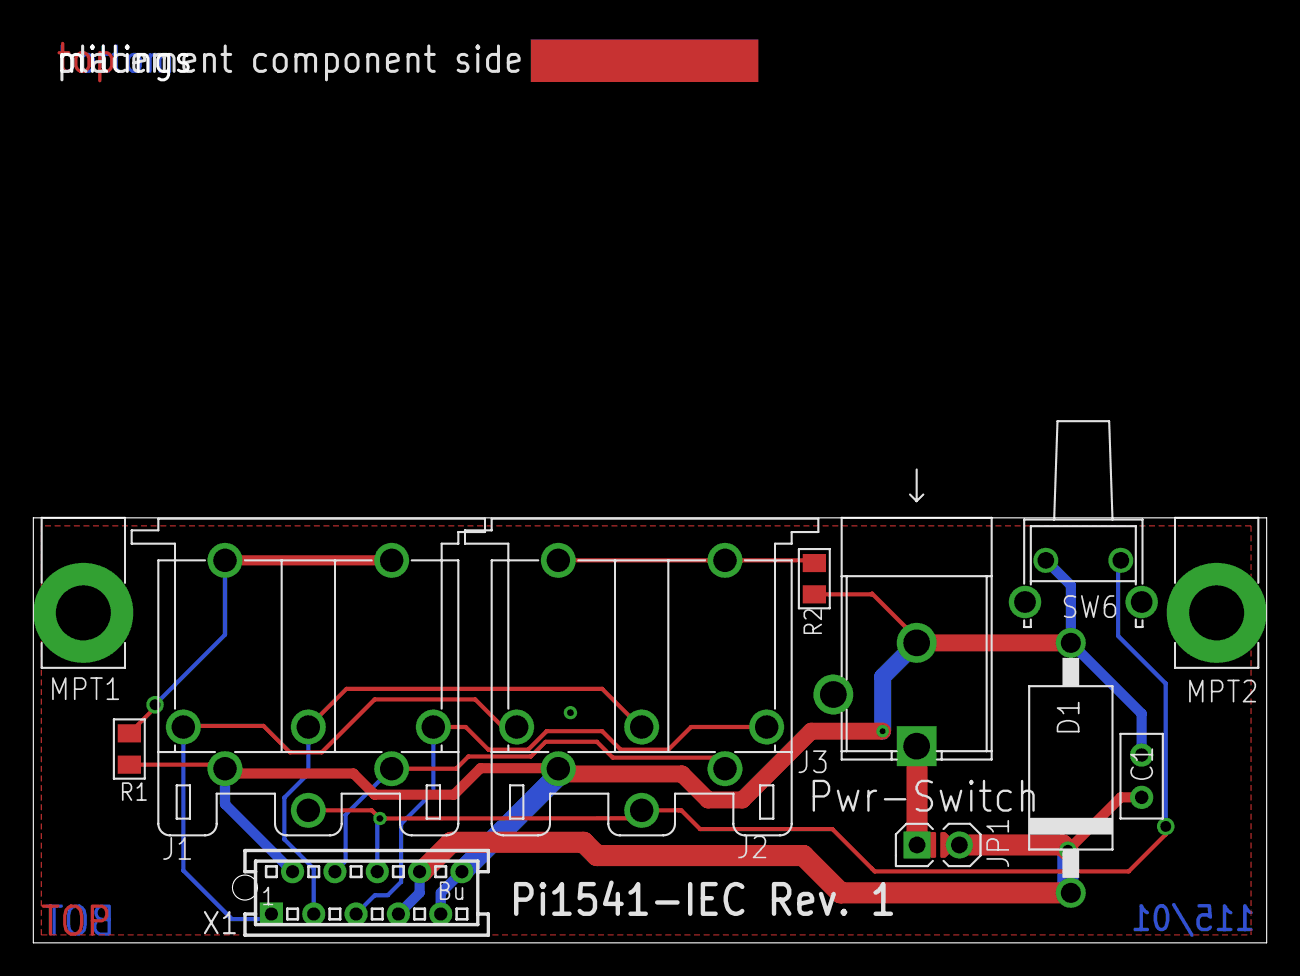
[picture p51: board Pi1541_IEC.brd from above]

Board: 2 copper layers, 74.0 x 25.5 mm, 14 parts (0 on the bottom side), 10 nets.

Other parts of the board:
U$44: 2LAYER
U$45: PCB-TITLE/

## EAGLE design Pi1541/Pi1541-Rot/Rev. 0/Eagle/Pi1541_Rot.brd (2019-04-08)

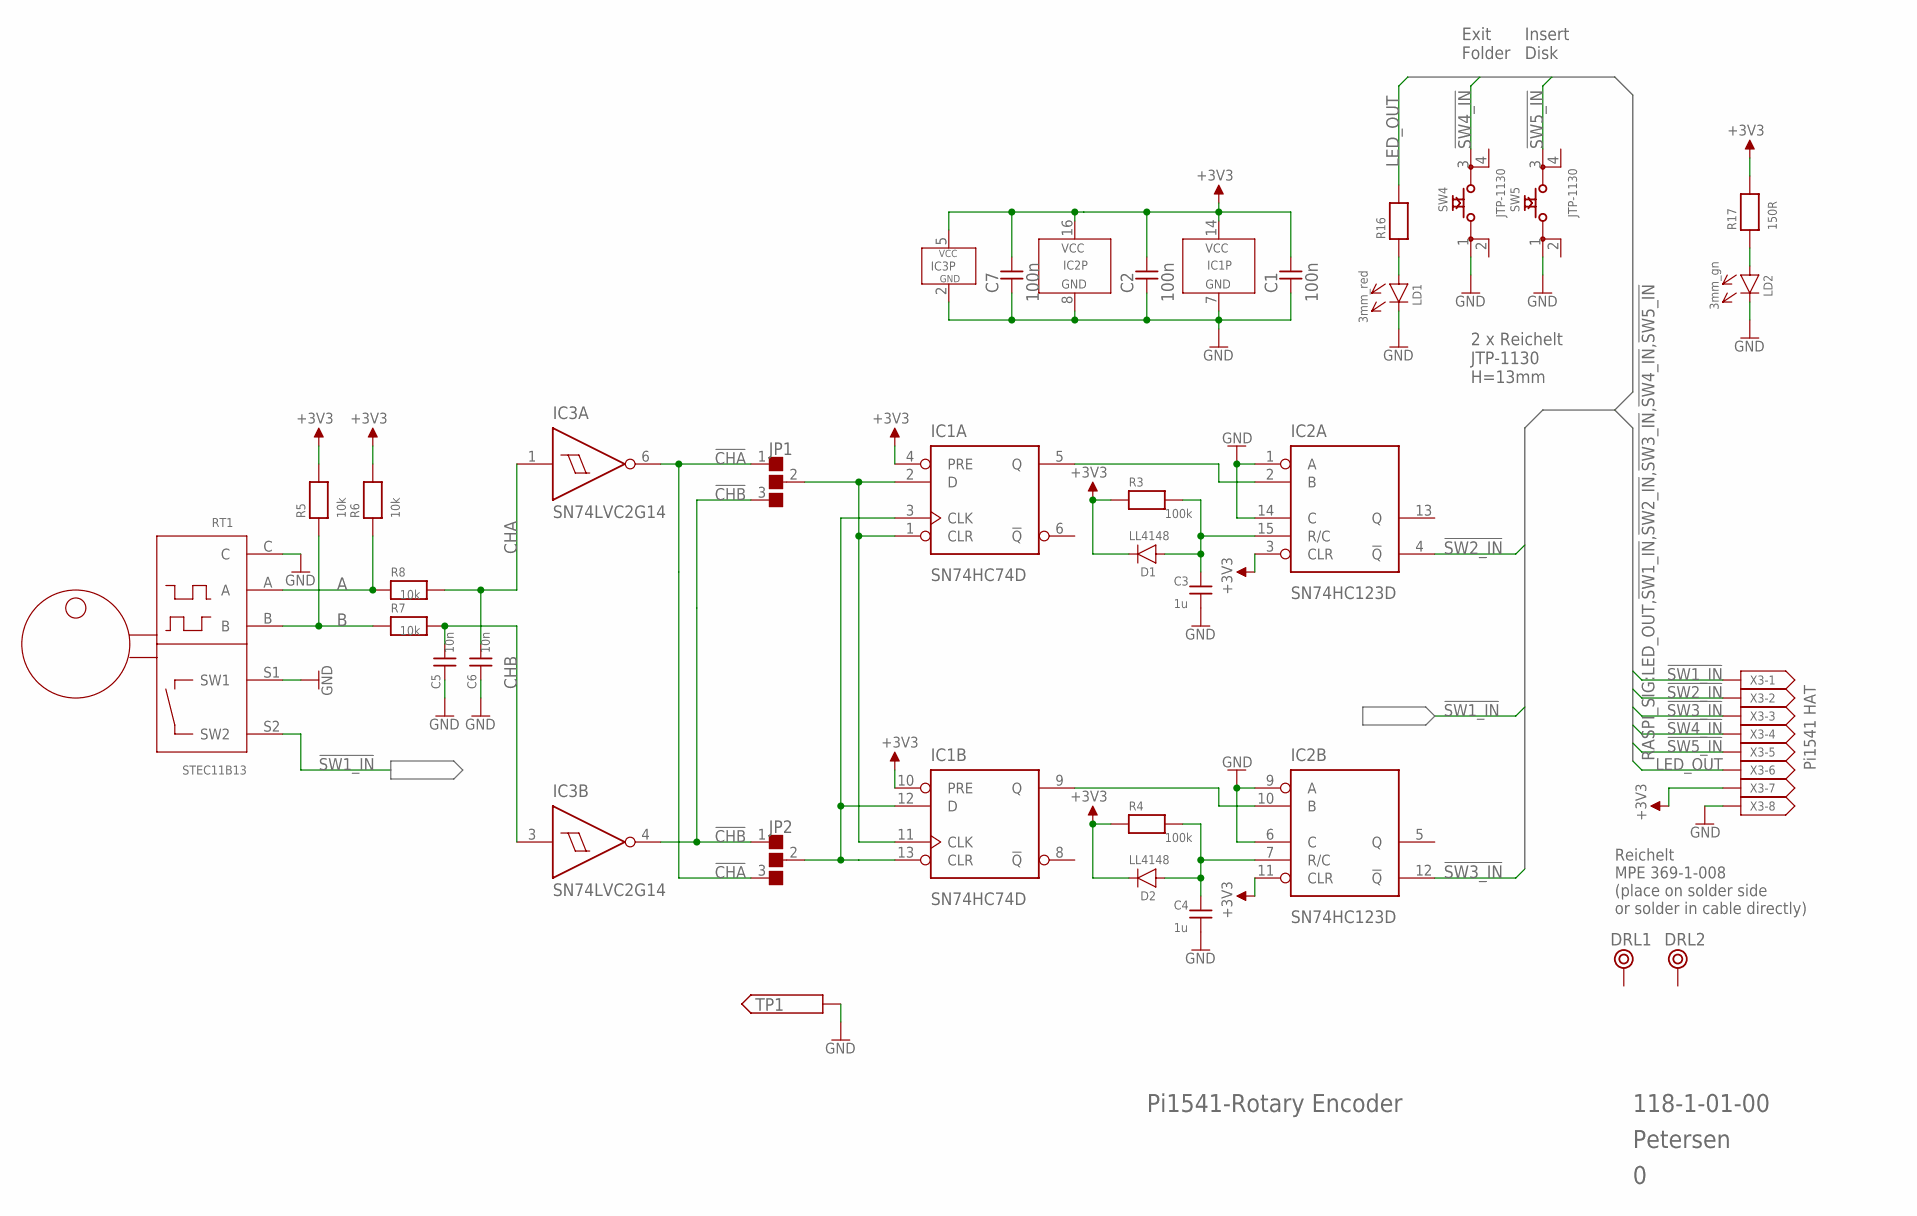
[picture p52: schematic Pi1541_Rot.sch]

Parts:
C1, C2, C7: 100n; 0805
C3, C4: 1u; 0805
C5, C6: 10n; 0805
D1, D2: LL4148; SOD80C
DRL1, DRL2: BOHR2,8; BOHR2,8_
IC1: SN74HC74D; SO-14
IC2: SN74HC123D; SO-16
IC3: SN74LVC2G14; SOT23-6
JP1, JP2: JMP_0603; CP3P
LD1: 3mm_red; 3MM
LD2: 3mm_gn; 3MM
R3, R4: 100k; 0805
R5, R6, R7, R8: 10k; 0805
R16, R17: 150R; 0805
RT1: STEC11B13
SW4, SW5: JTP-1130
TP1: PAD1,0/AUTO; 1.0/AUTO
X3: MICMA08B

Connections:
!CHA: IC3.6 (O), JP1.1, JP2.3
!CHB: IC3.4 (O), JP1.3, JP2.1
!SW1_IN: RT1.S2 (SW2), X3.1
!SW2_IN: IC2.4 (!Q), X3.2
!SW3_IN: IC2.12 (!Q), X3.3
!SW4_IN: SW4.3, X3.4
!SW5_IN: SW5.3, X3.5
+3V3: C1.2, C2.2, C7.2, D1.K, D2.K, IC1.4 (PRE), IC1.10 (PRE), IC1.14 (VCC), IC2.3 (CLR), IC2.11 (CLR), IC2.16 (VCC), IC3.5 (VCC), R3.1, R4.1, R5.2, R6.2, R17.2, X3.7
A: R6.1, R8.1, RT1.A
B: R5.1, R7.1, RT1.B
CHA: C6.2, IC3.1 (I), R8.2
CHB: C5.2, IC3.3 (I), R7.2
GND: C1.1, C2.1, C3.2, C4.2, C5.1, C6.1, C7.1, IC1.7 (GND), IC2.1 (A), IC2.6 (C), IC2.8 (GND), IC2.9 (A), IC2.14 (C), IC3.2 (GND), LD1.C (K), LD2.C (K), RT1.C, RT1.S1 (SW1), SW4.1, SW5.1, TP1.1, X3.8
LED_OUT: R16.2, X3.6
unnamed: IC1.5 (Q), IC2.2 (B)
unnamed: IC1.9 (Q), IC2.10 (B)
unnamed: IC1.1 (CLR), IC1.2 (D), IC1.11 (CLK), JP1.2
unnamed: C3.1, D1.A, IC2.15 (R/C), R3.2
unnamed: C4.1, D2.A, IC2.7 (R/C), R4.2
unnamed: IC1.3 (CLK), IC1.12 (D), IC1.13 (CLR), JP2.2
unnamed: LD2.A, R17.1
unnamed: LD1.A, R16.1

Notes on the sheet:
2 x Reichelt JTP-1130 H=13mm
Exit Folder
Insert Disk
Pi1541 HAT
Reichelt MPE 369-1-008 (place on solder side or solder in cable directly)
Pi1541-Rotary Encoder
Petersen
118-1-01-00

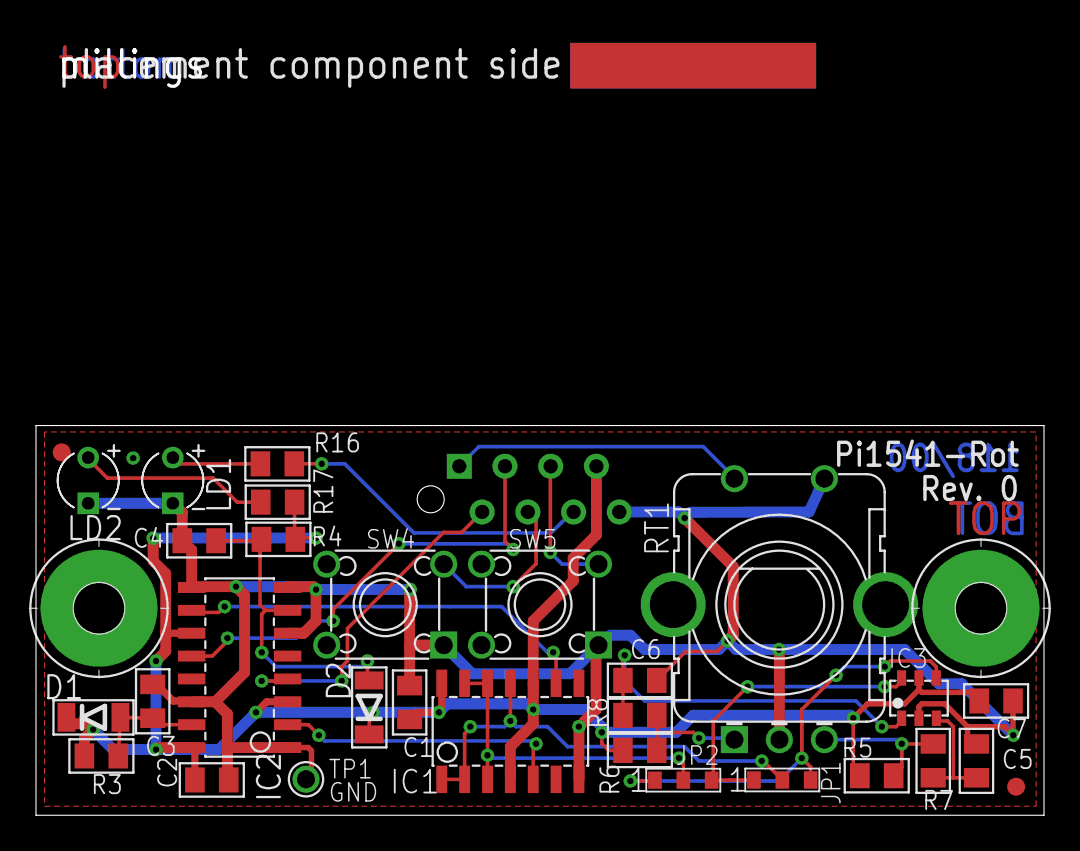
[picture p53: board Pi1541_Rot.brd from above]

Board: 2 copper layers, 56.0 x 21.6 mm, 35 parts (1 on the bottom side), 22 nets.

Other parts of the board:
U$23, U$24: SMD_REF_R1MM
U$44: 2LAYER
U$45: PCB-TITLE/

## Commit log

2019-03-17 Initial Upload
    [Pi1541-HAT_BOM_v1_0.xlsx, Pi1541-IEC_BOM_v0_0.xlsx, Pi1541-Switch_BOM_v1_0.xlsx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]
2019-03-18 Addendum Prototype Testing
    I have found something out.
2019-03-18 Addendum Prototype testing
    I found out, how flipping disks works...
2019-04-08 Now new: Rotary encoder option
    The Pi1541 can work with a rotary encoder instead of the Pi1541 Switch board. The original firmware works, since the circuit mimiks the original switches.
    [PI1541-Rot_BOM_v0_0.xlsx, PI1541-Rot_BOM_v0_1.xlsx, Pi1541_Rot.brd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]
2019-04-08 Added a picture of the rotary encoder board
2019-11-03 Add files via upload
    Added a pin header to connect a power switch
    [Pi1541-IEC_BOM_v1_0.xlsx, Pi1541_IEC.brd, Pi1541_IEC.dxf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]
2019-11-29 Revision 2 (rotary encoder support)
    [Pi1541-HAT_BOM_v2_0.xlsx, Pi1541_HAT.brd, Pi1541_HAT.dxf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]
2019-11-30 Add files via upload
    Rev. 2 released, this sopports the connection of a rotary encoder module, like KY-040. A standard rotary encoder is supported after firmware/kernel version v1.21
    [Pi1541-Switch_BOM_v2_0.xlsx, Pi1541_Switch.brd, Pi1541_Switch.dxf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]
